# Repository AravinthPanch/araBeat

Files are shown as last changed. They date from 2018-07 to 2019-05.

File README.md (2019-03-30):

<p align="center">
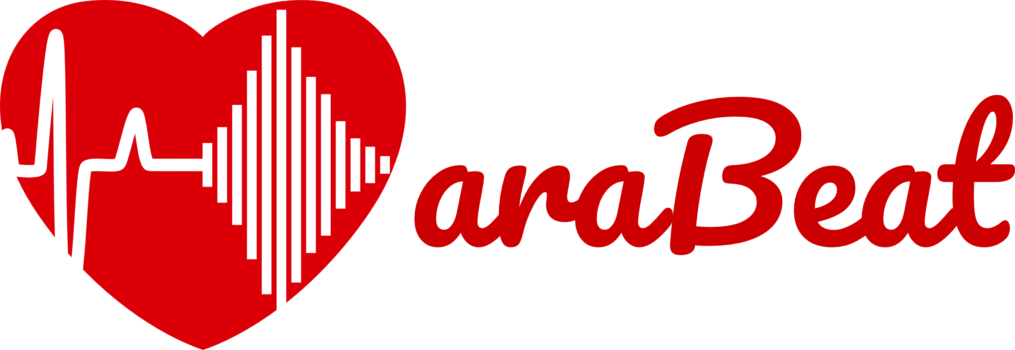
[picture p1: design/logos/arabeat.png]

</p>

# araBeat

araBeat is an interactive new media art developed for the artistic sonification of Electrocardiogram (ECG). It is a complete system that consists of modules of ECG, DSP, MCU & Motherboard.

araBeat captures ECG of human Interactors through two gel-less electrodes, identifies the QRS complex of ECG, calculates the time difference between the R wave peaks and using Audio DSP, it synthesizes high & low frequency sound in realtime, which is synchronized with the heartbeats of the Interactor.

araBeat lies in the spectrum of new media art, the form of interaction with the technology is designed with aesthetics in mind using stainless steel electrodes in the form of human hand.

araBeat is designed to be extendable using modular designs, so that every component can be just individually plugged into the motherboard. It is also built as an industrial grade system to operate in harsh weather conditions from -40 ° Celsius to 85 ° Celsius. Furthermore, it is designed to comply with medical grade electronics to have low electrical noises and safety.

In the first public appearance, araBeat is integrated into a permanent & public mosaic art installation called "The Heart Of Uptown", located at MoZaic East, Minneapolis, USA.

<p align="center">
<b>The Heart Of Uptown powered by araBeat</b>
</br>
</br>
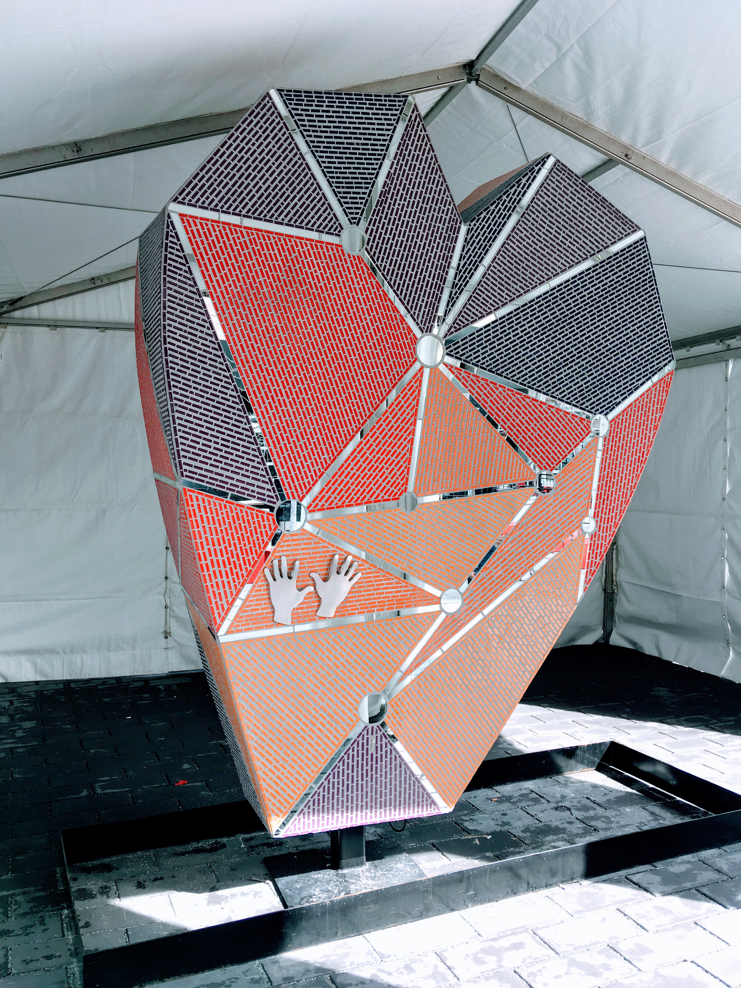
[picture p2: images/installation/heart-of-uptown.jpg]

</p>

## ARTISTS

-   Aravinth Panch &lt; <http://aravinth.info> > New Media Art
-   Stacia Goodman &lt; <http://www.staciagoodmanmosaics.com> > Mosaic Art

## COLLABORATORS

-   Marc Basara - Project Management, Minneapolis
-   Stuart Ackerberg - Art Producer, Minneapolis
-   Felix Christmann - Industrial Design, Berlin
-   Alessandro Aresta - Sound Engineering, Berlin
-   Len Goodman - Graphic Design, Minneapolis
-   John Bean, Giam Nguyen, Hart Johnson, Randi Johnson - Production Management, Minneapolis
-   Pavel Spieker, Kelly Ludeking, Anthony Kling - Structural Design & Construction, Minneapolis
-   Shresth Agrawal - Software Engineering, Berlin
-   Chris Kooper - Metalworking, Berlin

## SUPPORTERS

-   Natalia Aravinth, Mladen Miljic, Darina Onoprienko - Family & Mental Support
-   David Riding, Jasmin Skenderi - Electrical Design Review, Next Big Thing, Berlin
-   Karissa Xie, Rolin Pei - CNC Machining, HLH Prototypes, Shenzhen
-   Monica Shen, Ivy Li, Carmen Zheng - PCB Manufacturing, Seeed Studio, Shenzhen
-   Goran, Sascha Hamacher - WaterJet Cutting, S-Hamacher Art Production Studio, Berlin
-   Robert Blowsky - Digital Signal Processing, Analog Devices, EZ Forum

## STUDIOS AND MANUFACTURERS

-   nLab, Berlin - Interaction Technology Design & Development
-   MotionLab, Berlin - Prototype CNC Machining
-   Tivoli Too, Minneapolis - Structural Design & Construction
-   Seeed Studio, Shenzhen - PCB Manufacturing
-   Troublemaker, Shenzhen - Prototyping
-   HLH Prototypes, Shenzhen - CNC Machining
-   S-Hamacher Art Production Studio, Berlin - WaterJet Cutting & Metalworking

## DESIGN

### Interaction Technology & Mosaic Installation Concept

<p align="center">
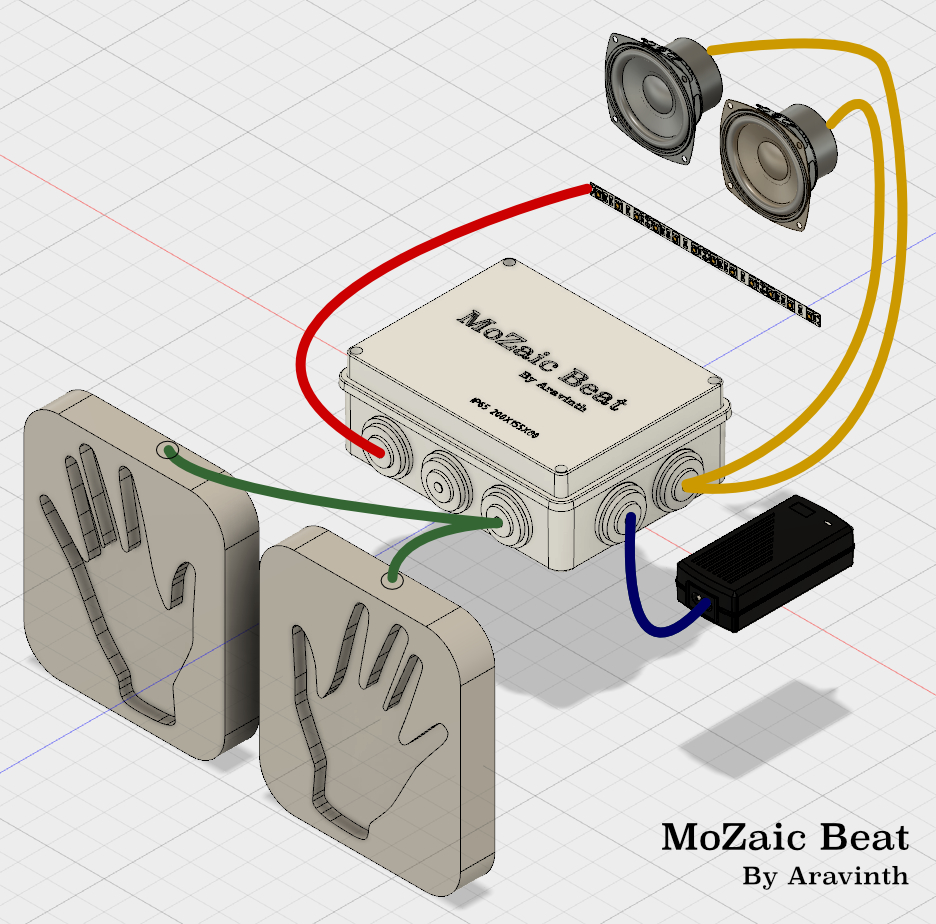
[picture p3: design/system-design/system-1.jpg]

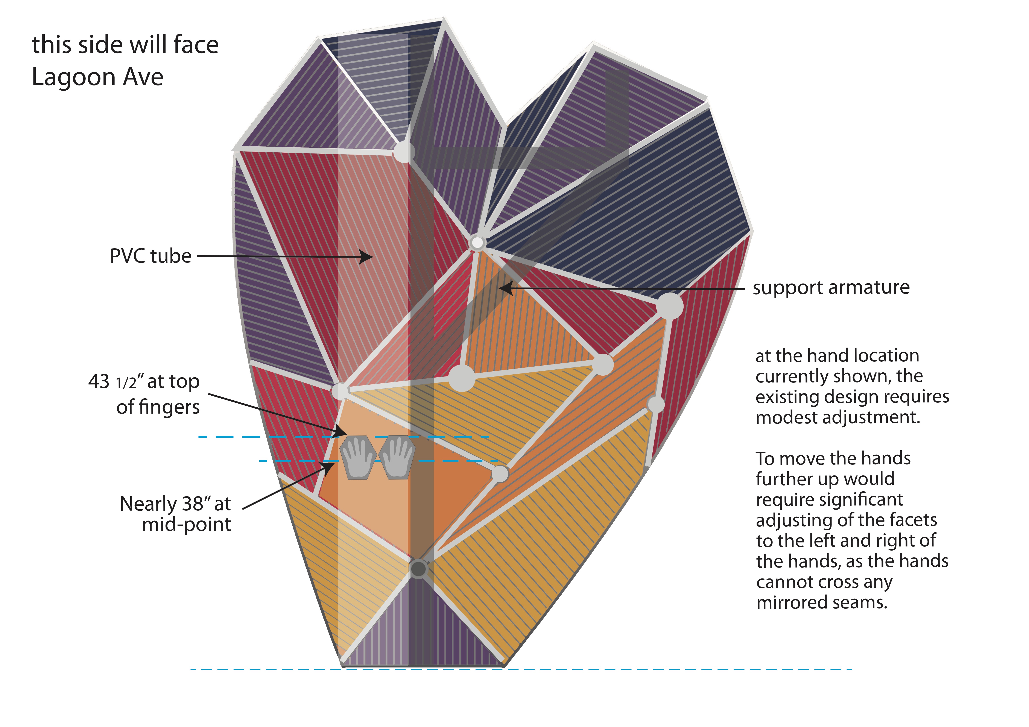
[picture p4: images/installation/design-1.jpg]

</p>

## DEVELOPMENT

### The Heart Of Uptown Installation

-   #### Stage 1 Completion

<p align="center">
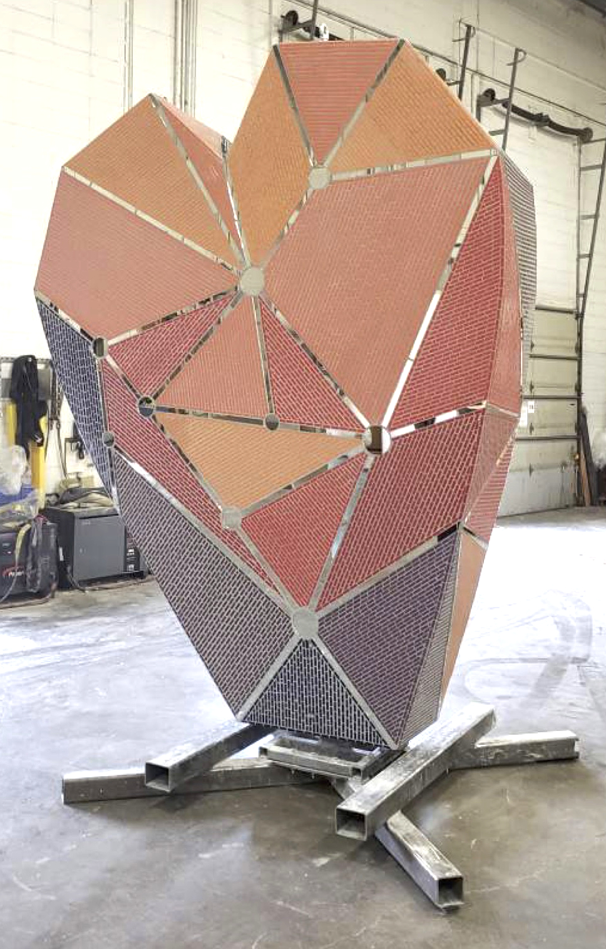
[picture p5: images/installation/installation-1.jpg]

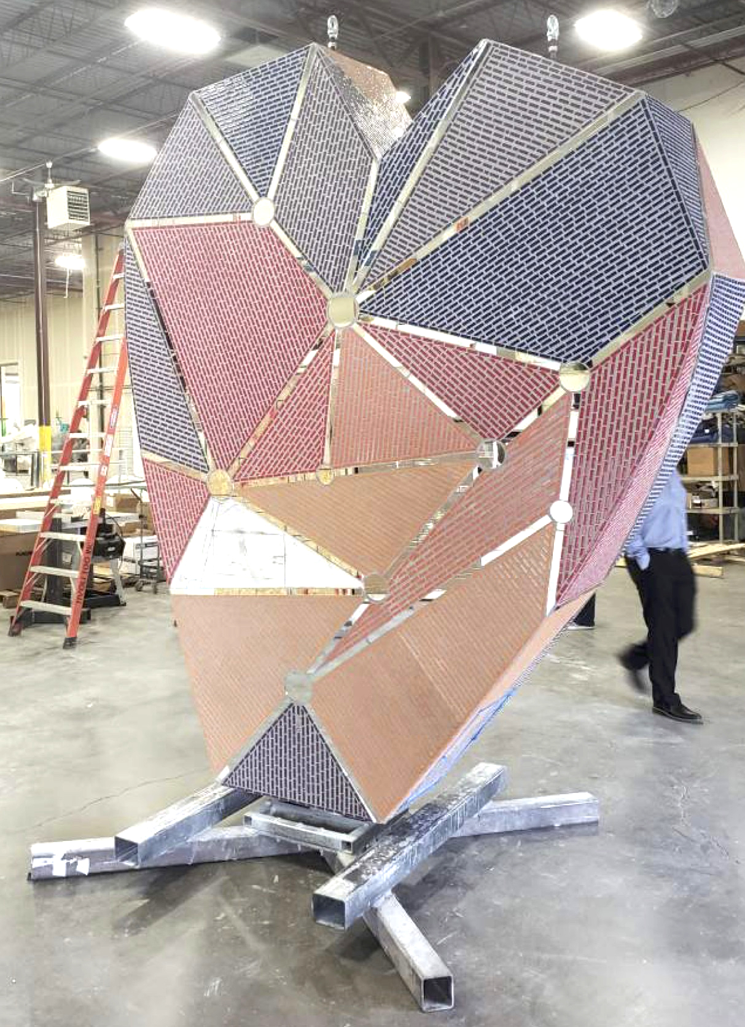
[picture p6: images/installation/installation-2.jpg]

</p>

-   #### Stage 2 Completion

<p align="center">
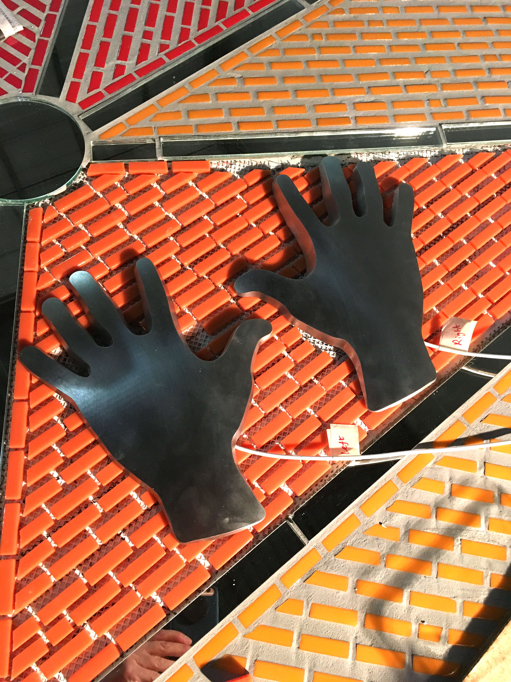
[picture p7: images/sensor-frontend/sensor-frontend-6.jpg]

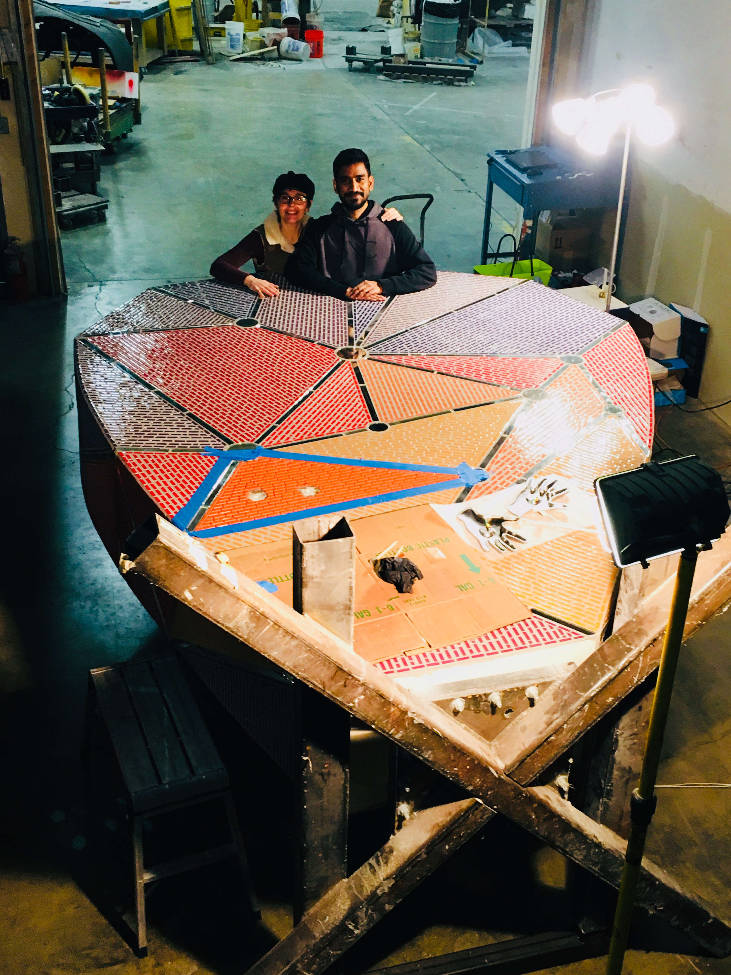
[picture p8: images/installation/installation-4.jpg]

</p>

-   #### Stage 3 Completion

<p align="center">
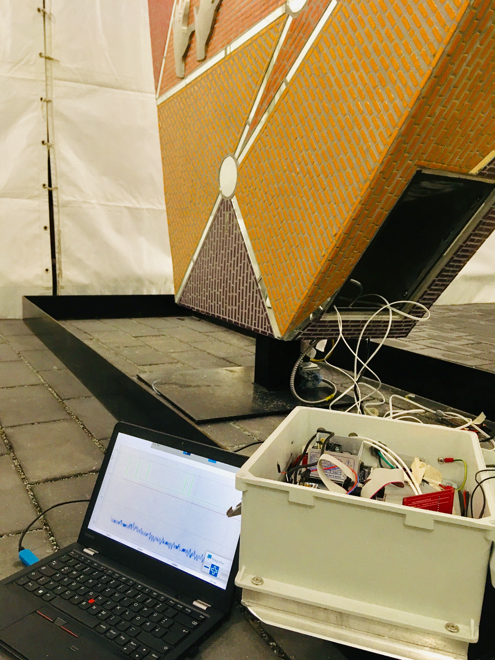
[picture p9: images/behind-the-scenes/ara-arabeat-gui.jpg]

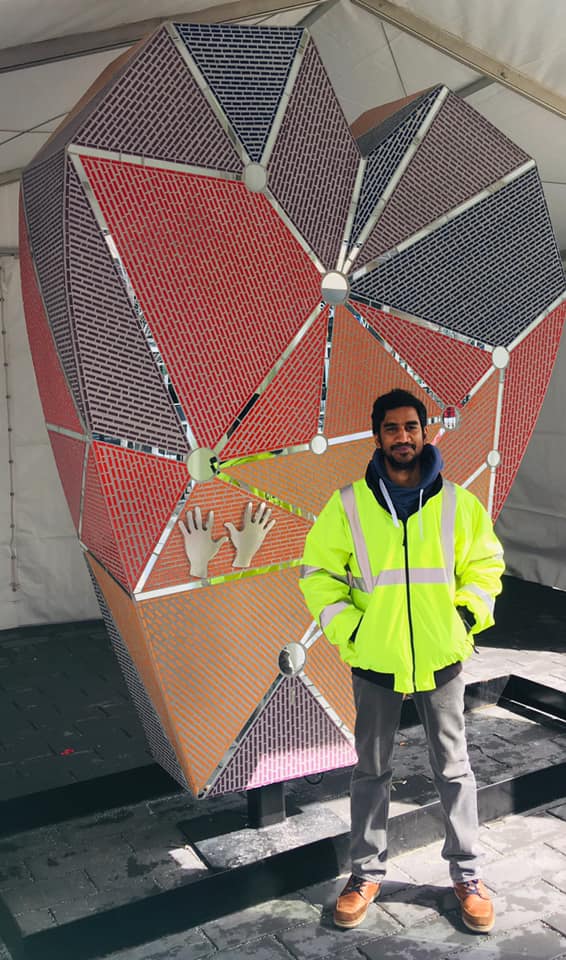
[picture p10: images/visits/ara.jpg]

</p>

### Interaction Technology

-   #### Wiring Design

<p align="center">
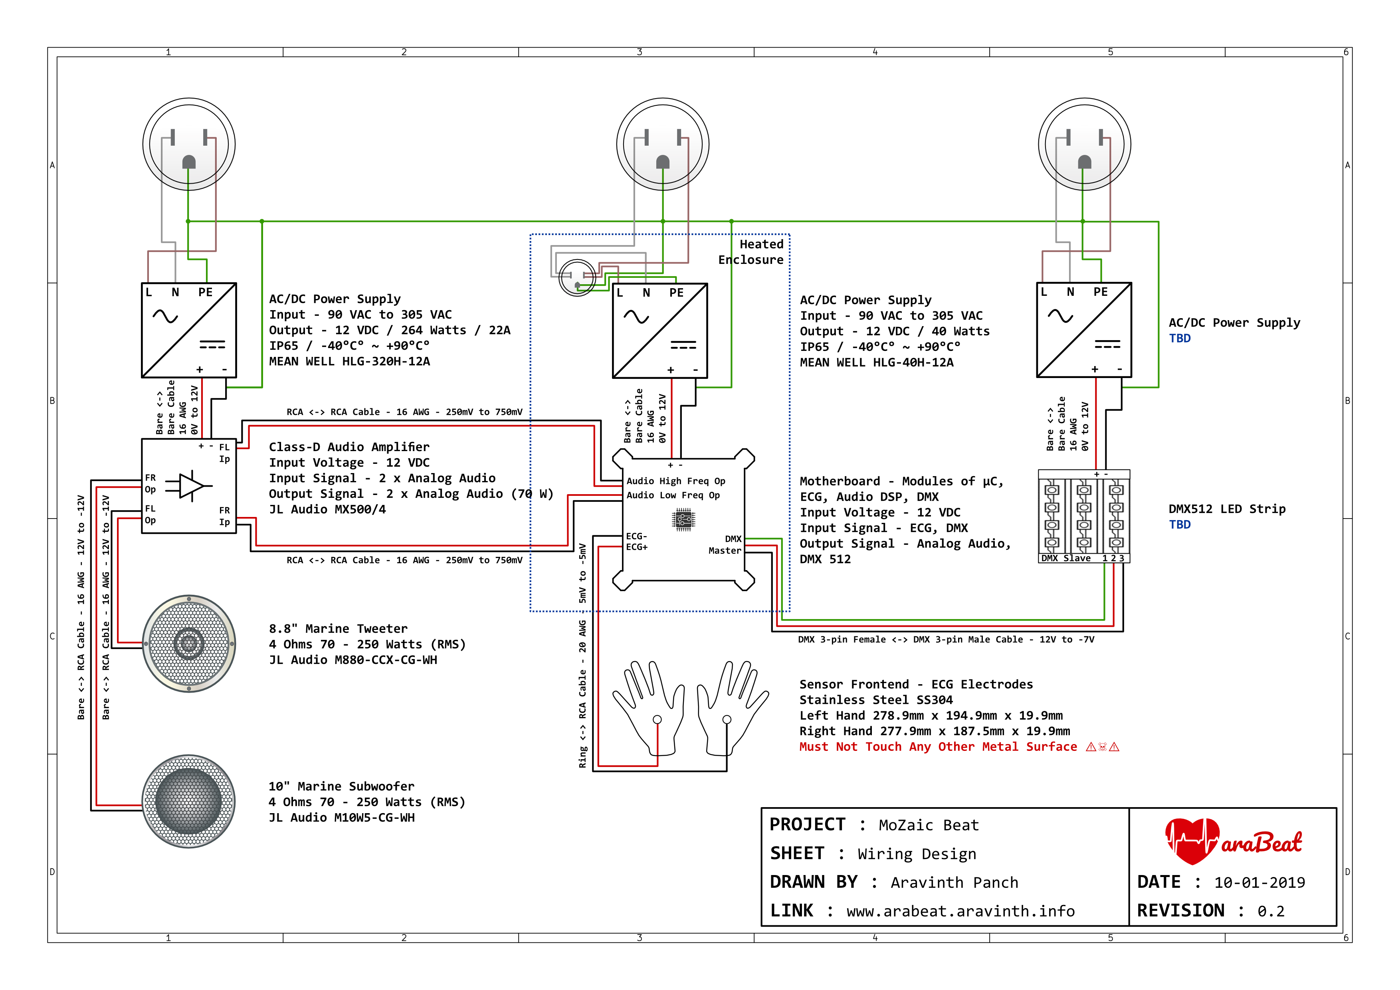
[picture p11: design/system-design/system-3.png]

</p>

-   #### Prototype v1.0

<p align="center">
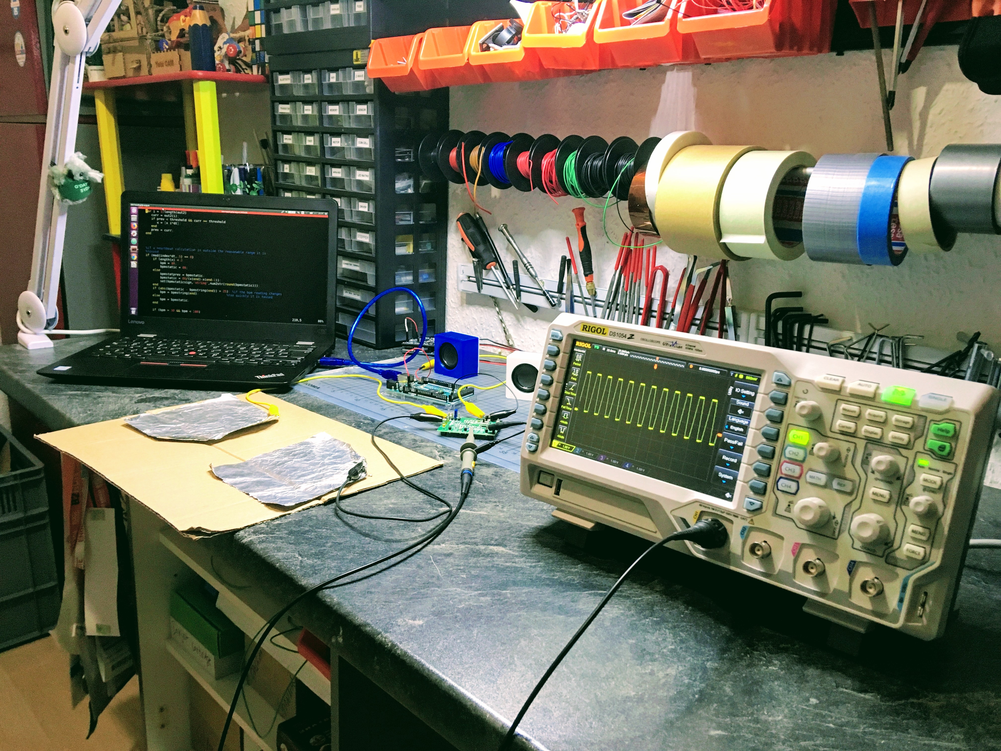
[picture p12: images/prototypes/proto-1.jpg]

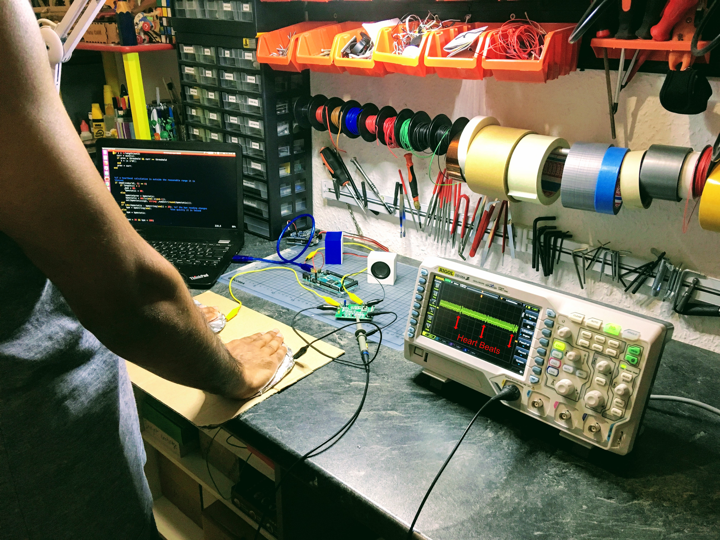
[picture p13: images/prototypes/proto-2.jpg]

</p>

-   #### Prototype v2.0

<p align="center">
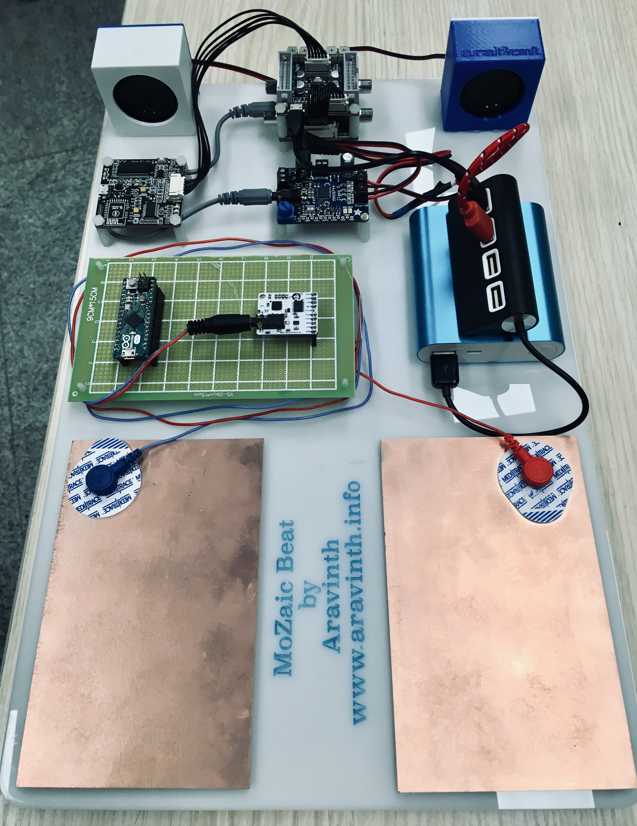
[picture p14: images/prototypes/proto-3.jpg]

</p>

-   #### Prototype v3.0

<p align="center">
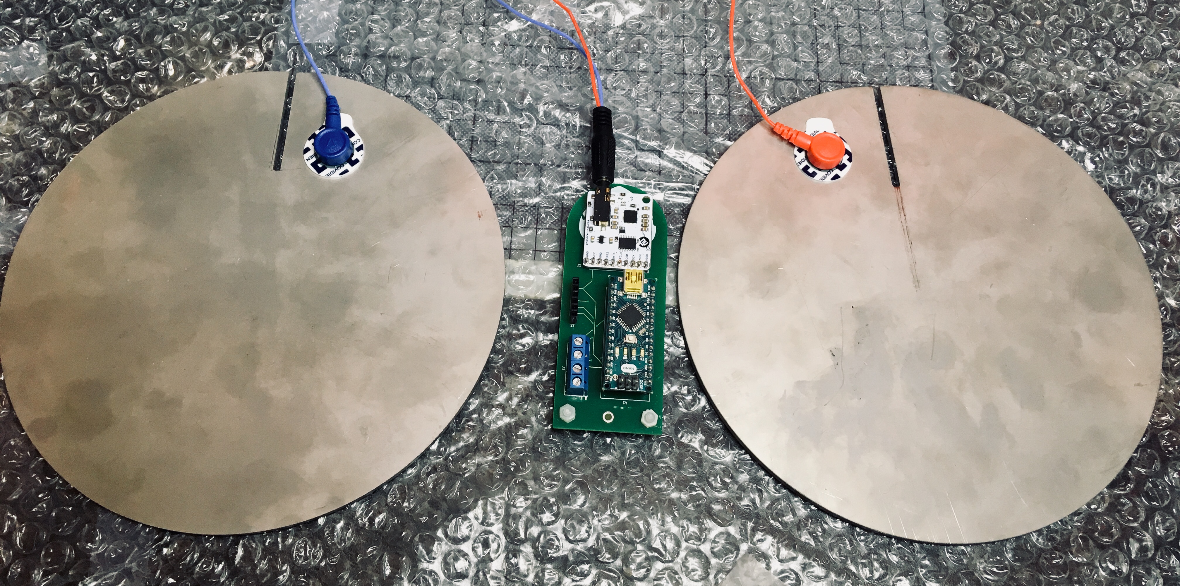
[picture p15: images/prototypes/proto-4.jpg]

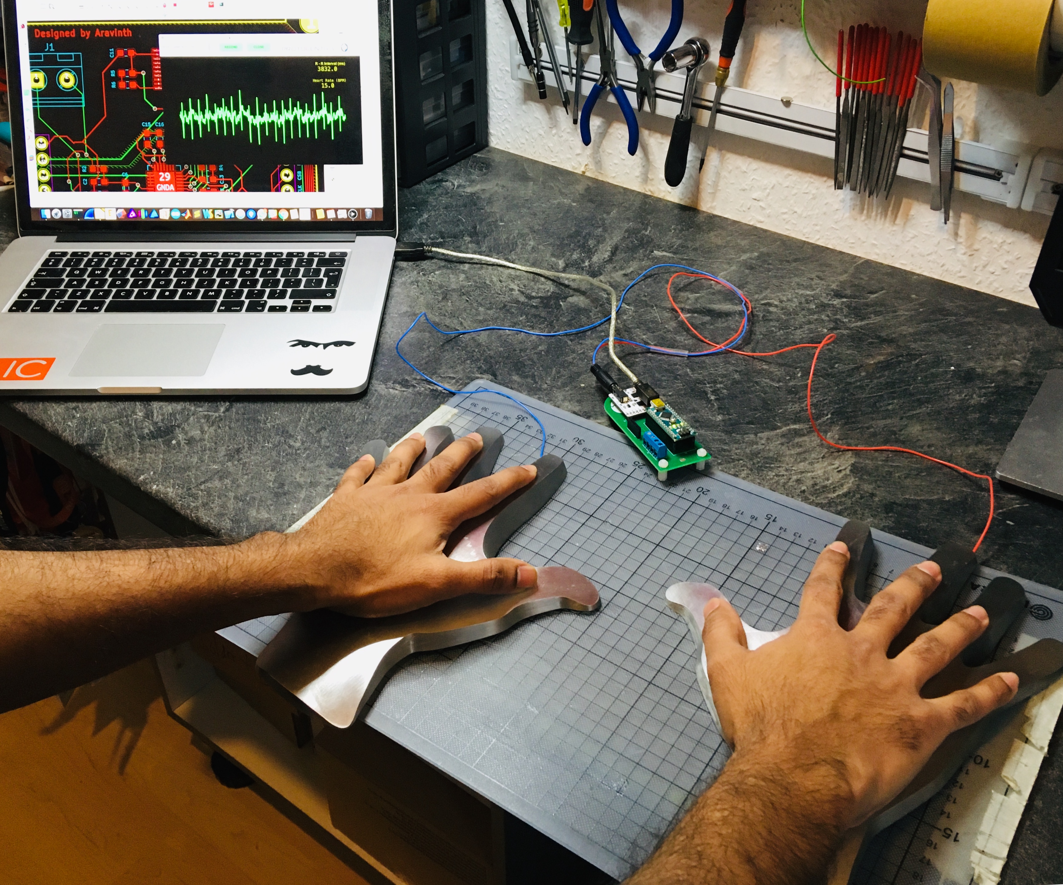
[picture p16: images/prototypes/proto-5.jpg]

</p>

-   #### Prototype v4.0

<p align="center">
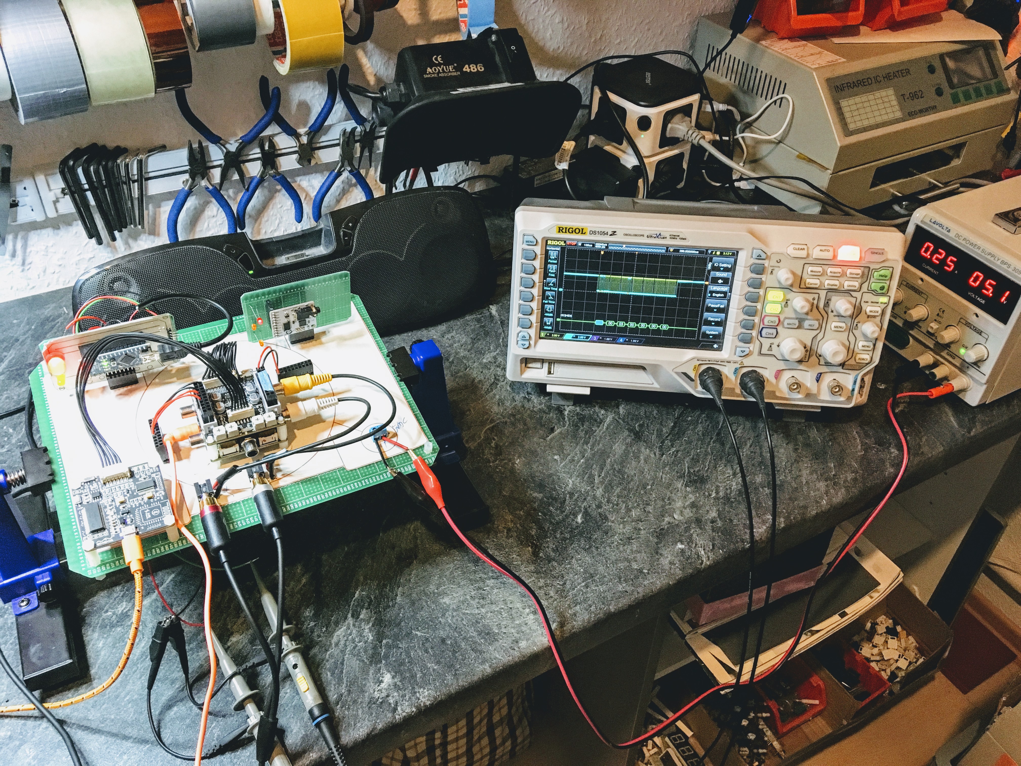
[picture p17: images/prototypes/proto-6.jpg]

</p>

-   #### Motherboard v0.1

<p align="center">
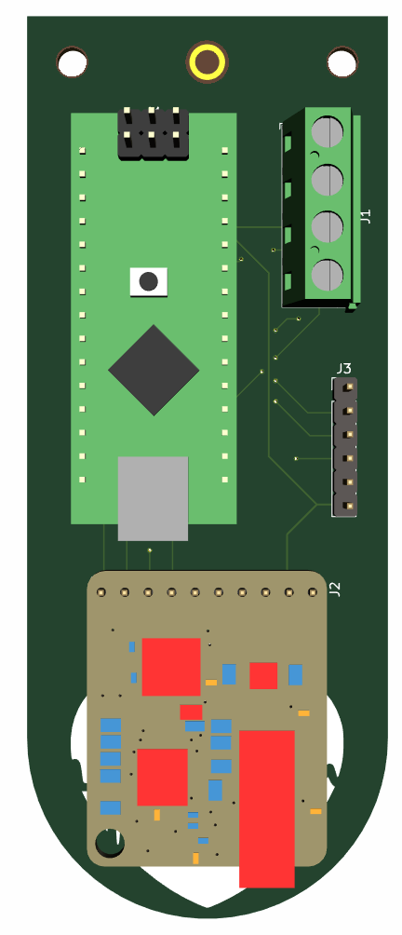
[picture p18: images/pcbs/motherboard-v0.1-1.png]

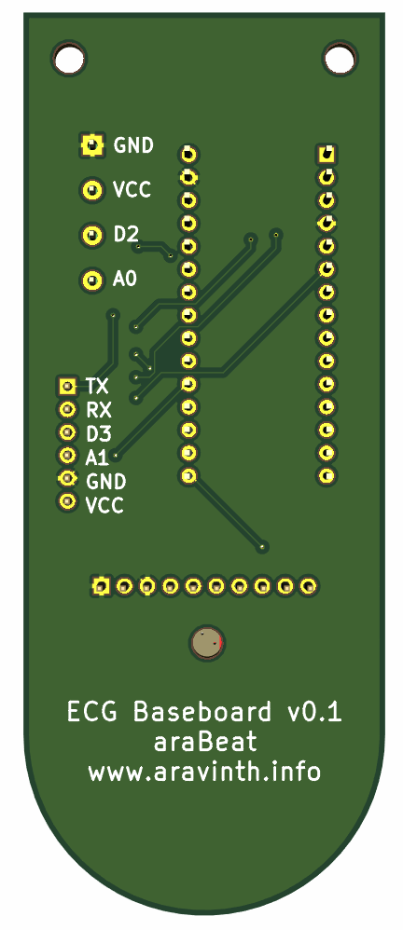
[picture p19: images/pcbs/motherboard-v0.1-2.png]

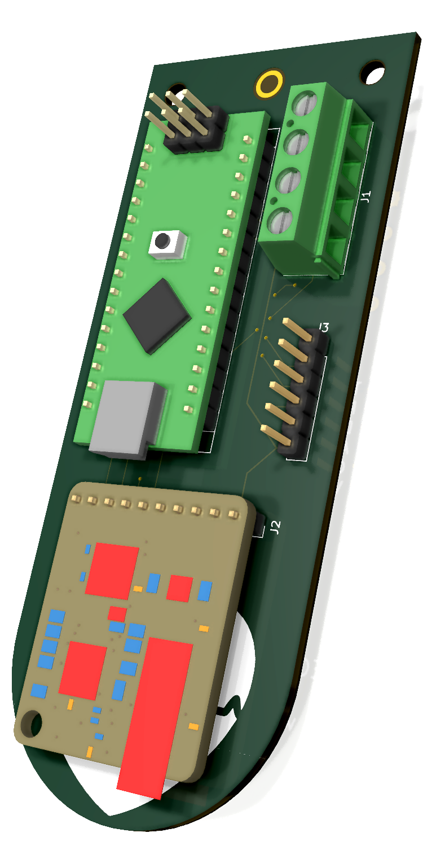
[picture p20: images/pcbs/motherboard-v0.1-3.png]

</br>
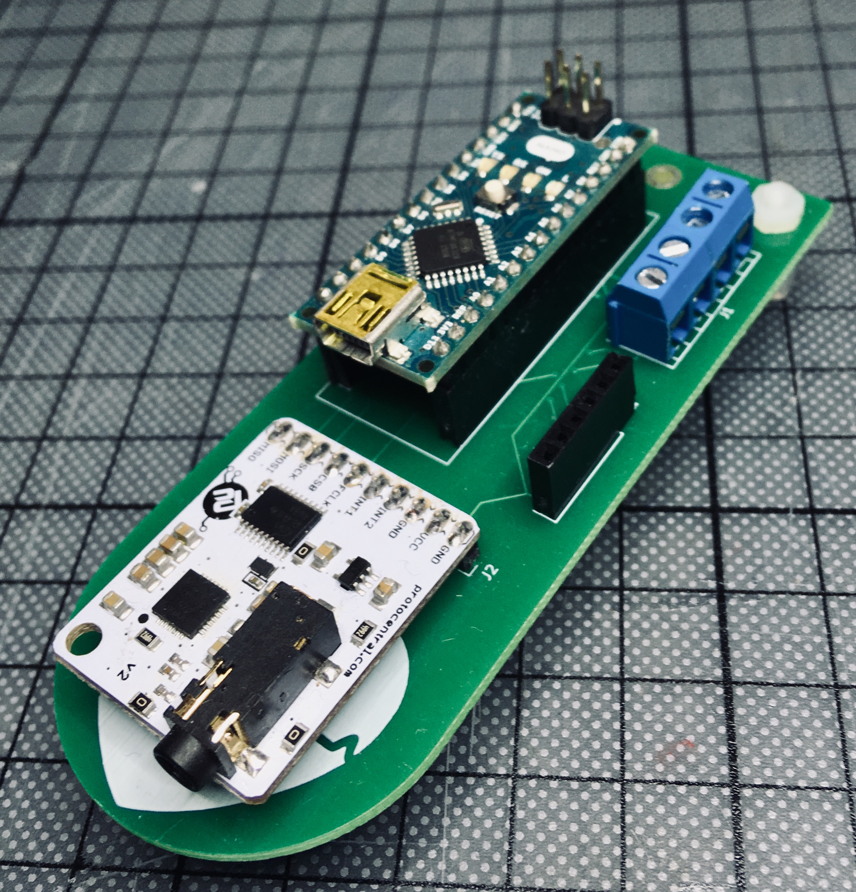
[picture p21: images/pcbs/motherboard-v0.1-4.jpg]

</p>

-   #### ECG Module v0.1

<p align="center">
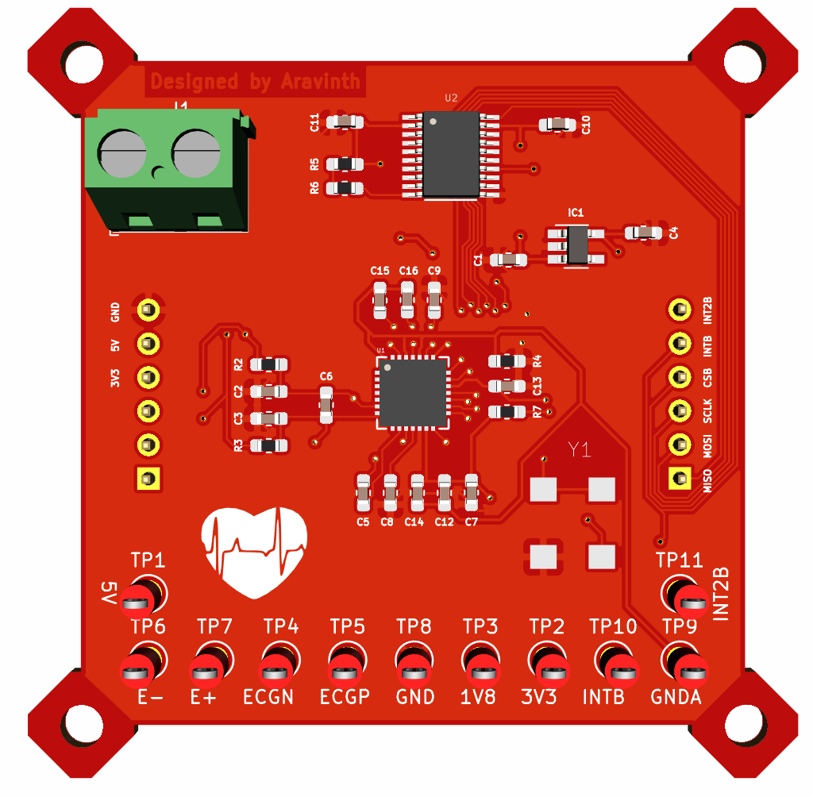
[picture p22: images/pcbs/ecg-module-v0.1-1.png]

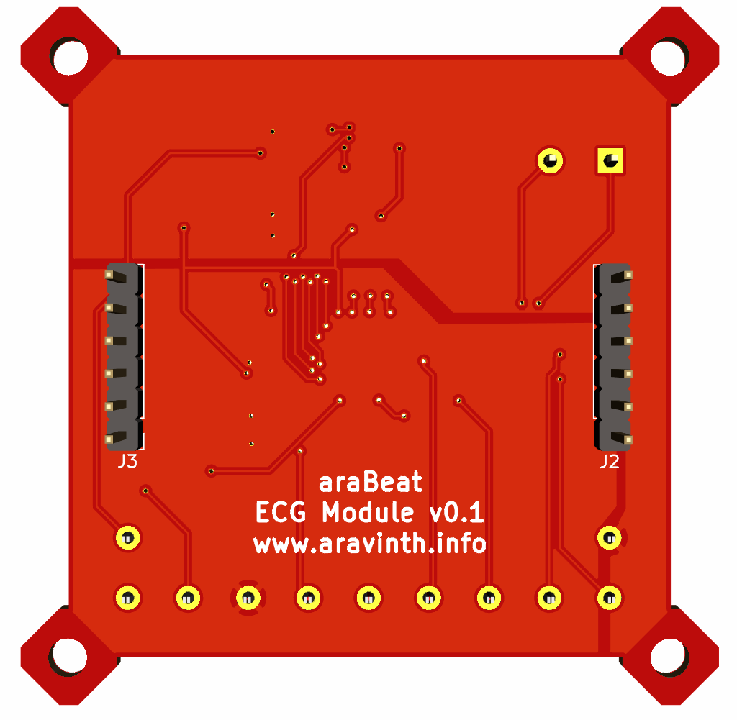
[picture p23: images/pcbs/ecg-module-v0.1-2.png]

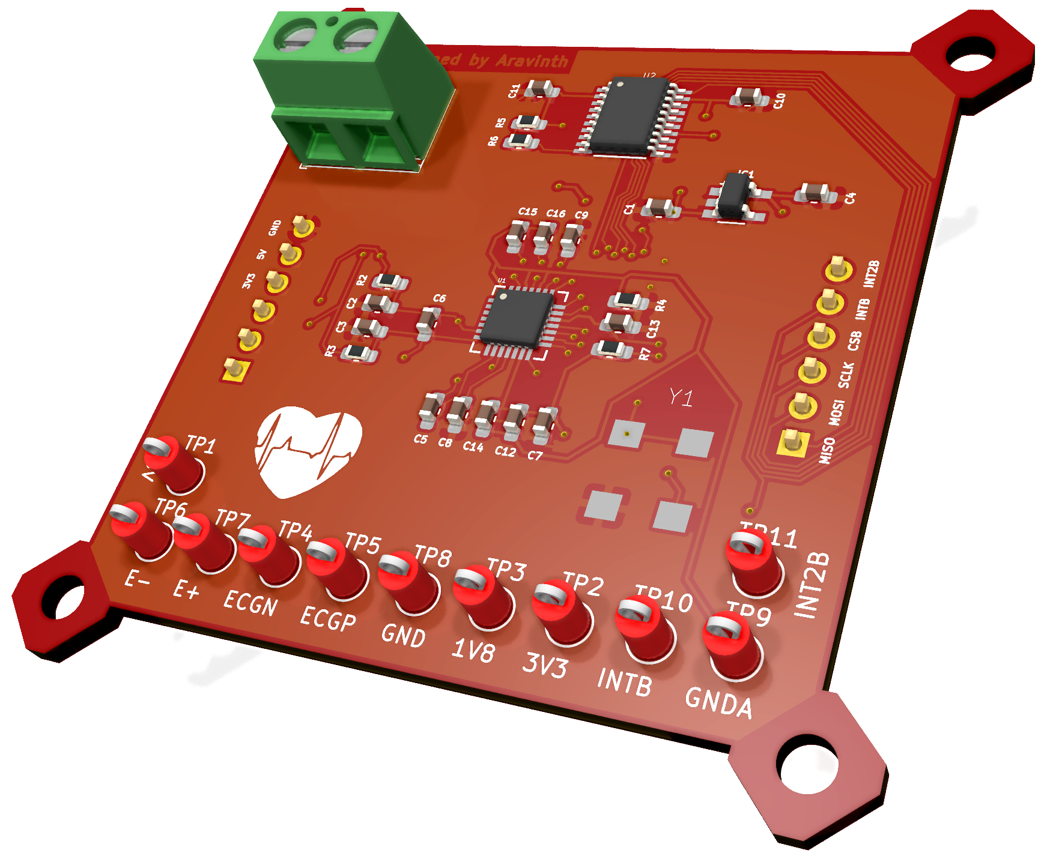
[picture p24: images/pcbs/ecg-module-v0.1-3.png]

</p>

-   #### ECG Module v0.2

<p align="center">
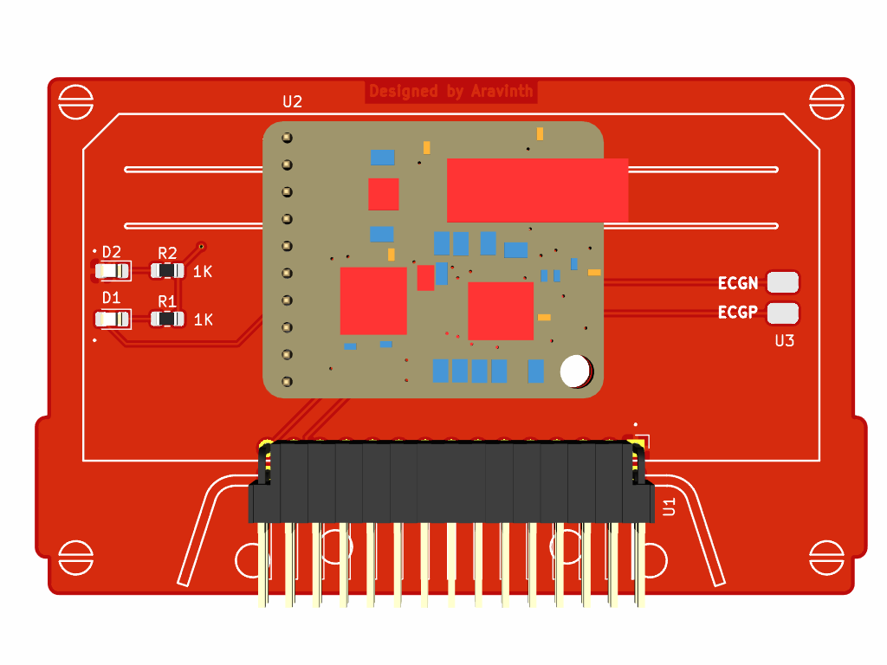
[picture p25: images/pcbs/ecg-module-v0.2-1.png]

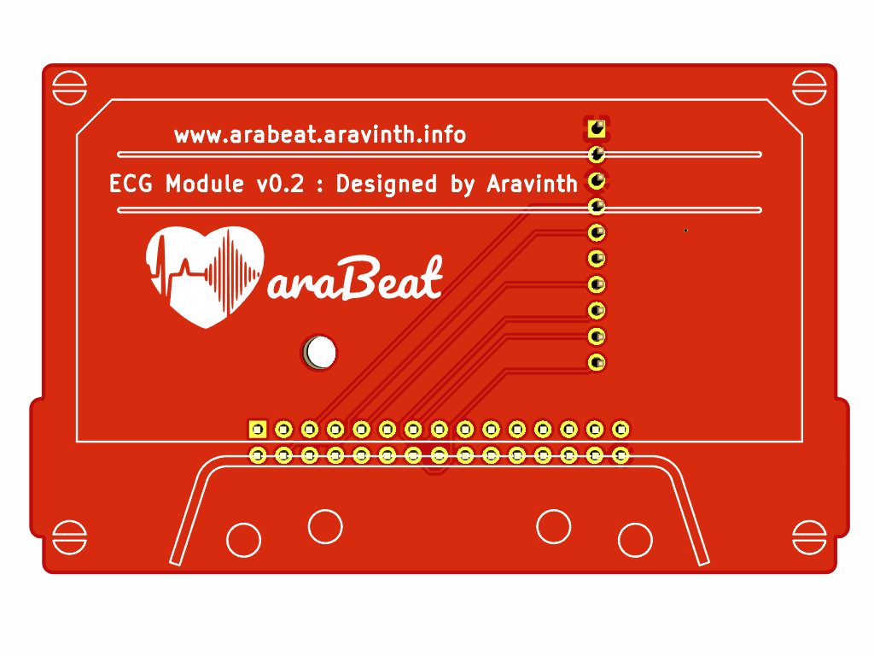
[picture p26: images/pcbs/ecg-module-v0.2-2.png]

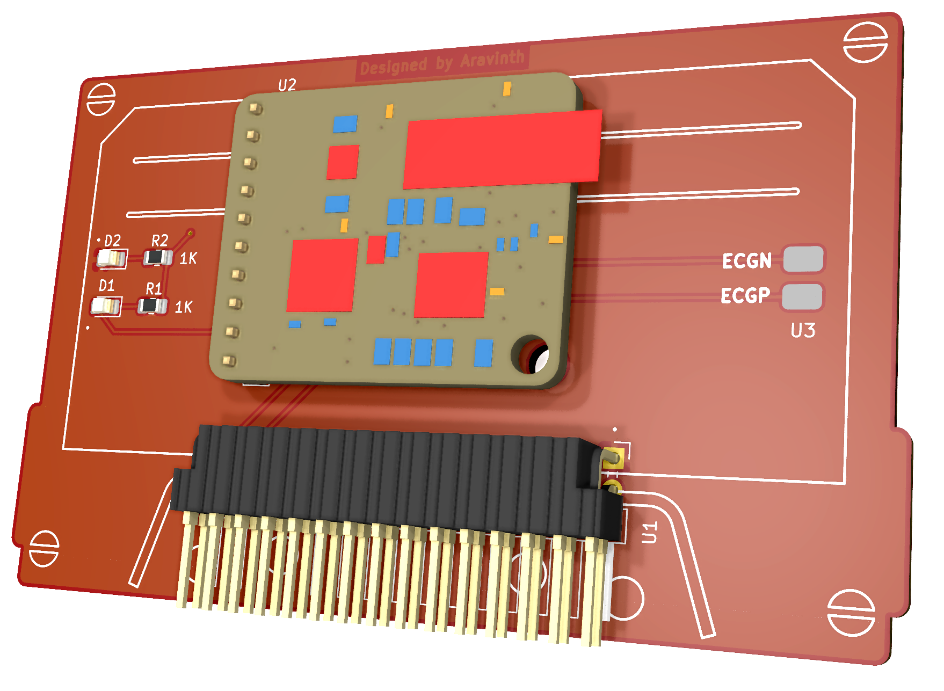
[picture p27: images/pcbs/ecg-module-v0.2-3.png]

</p>

-   #### MCU Module v0.1

<p align="center">
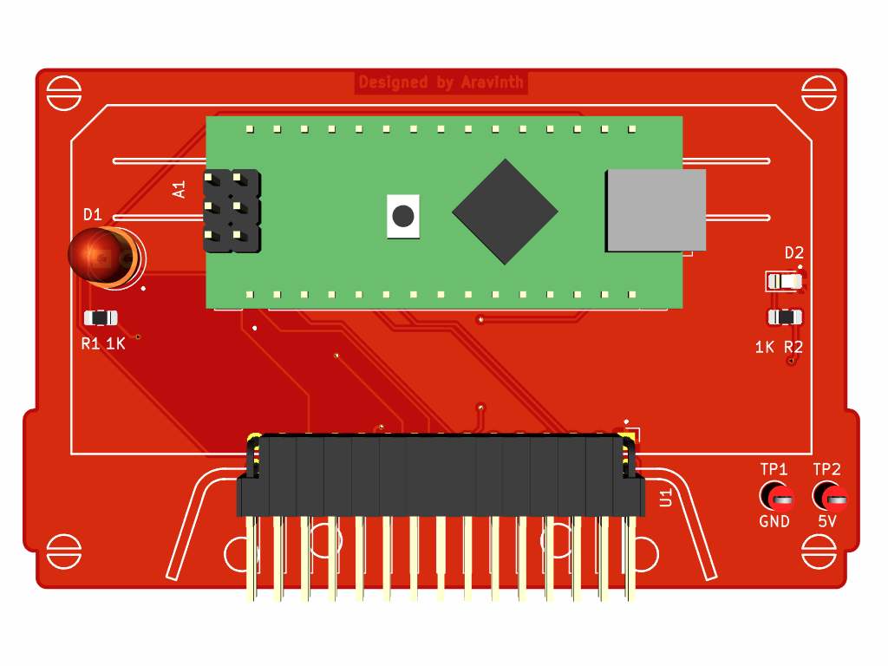
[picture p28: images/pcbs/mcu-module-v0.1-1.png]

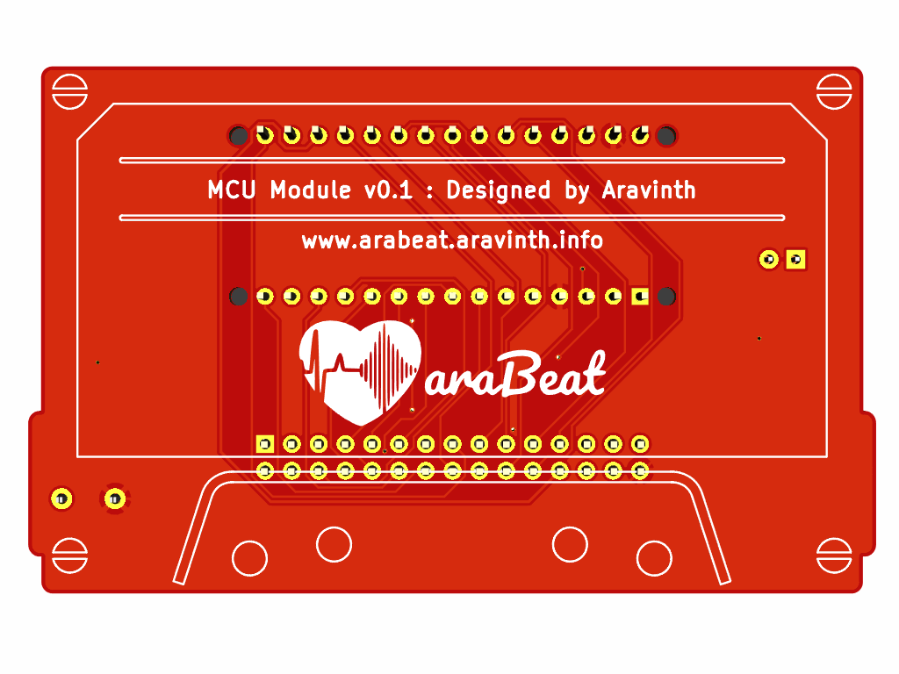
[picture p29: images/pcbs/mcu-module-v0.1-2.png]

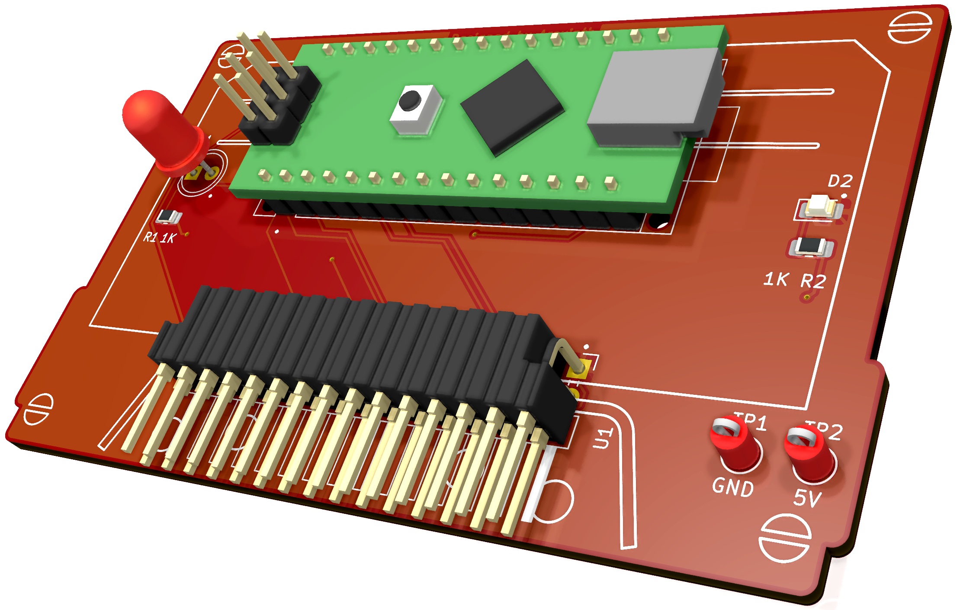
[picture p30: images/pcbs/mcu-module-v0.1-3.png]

</p>

-   #### Motherboard v1.0

<p align="center">
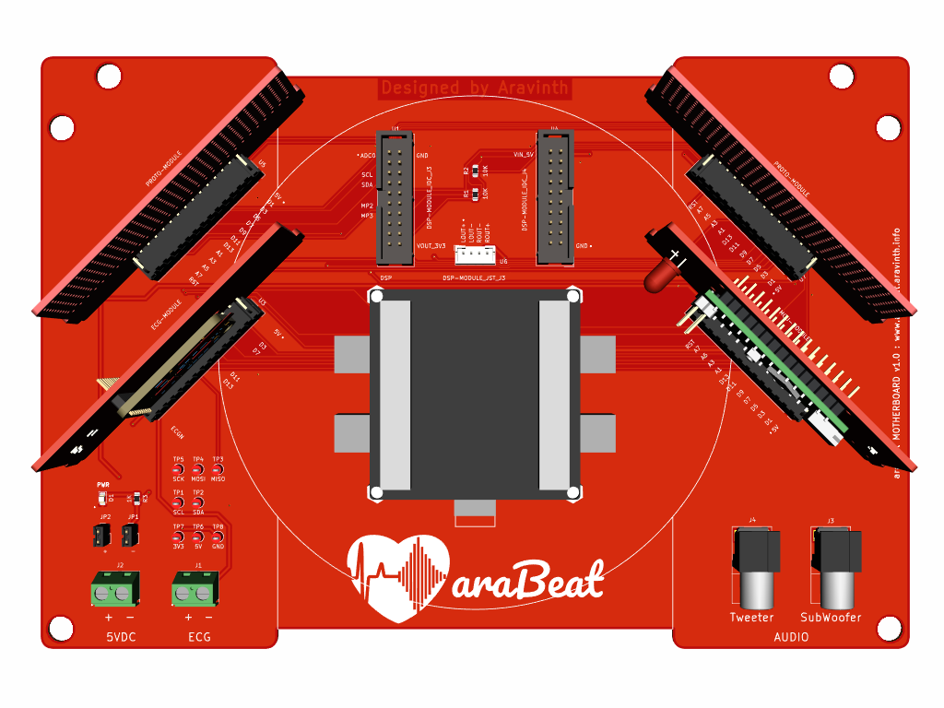
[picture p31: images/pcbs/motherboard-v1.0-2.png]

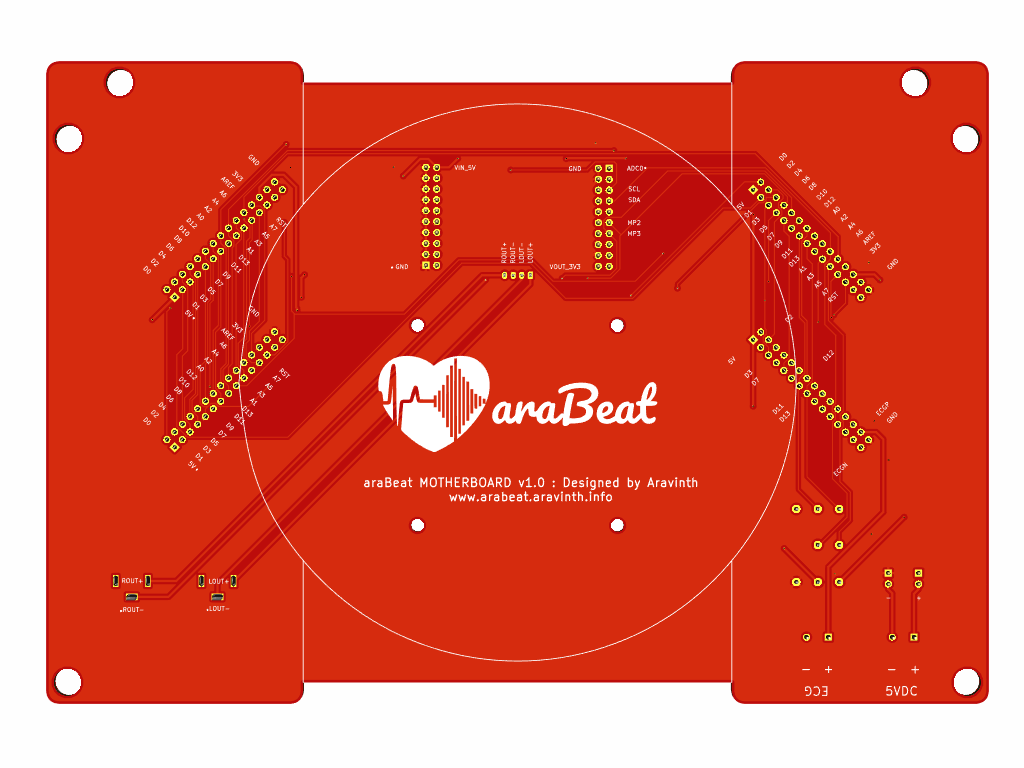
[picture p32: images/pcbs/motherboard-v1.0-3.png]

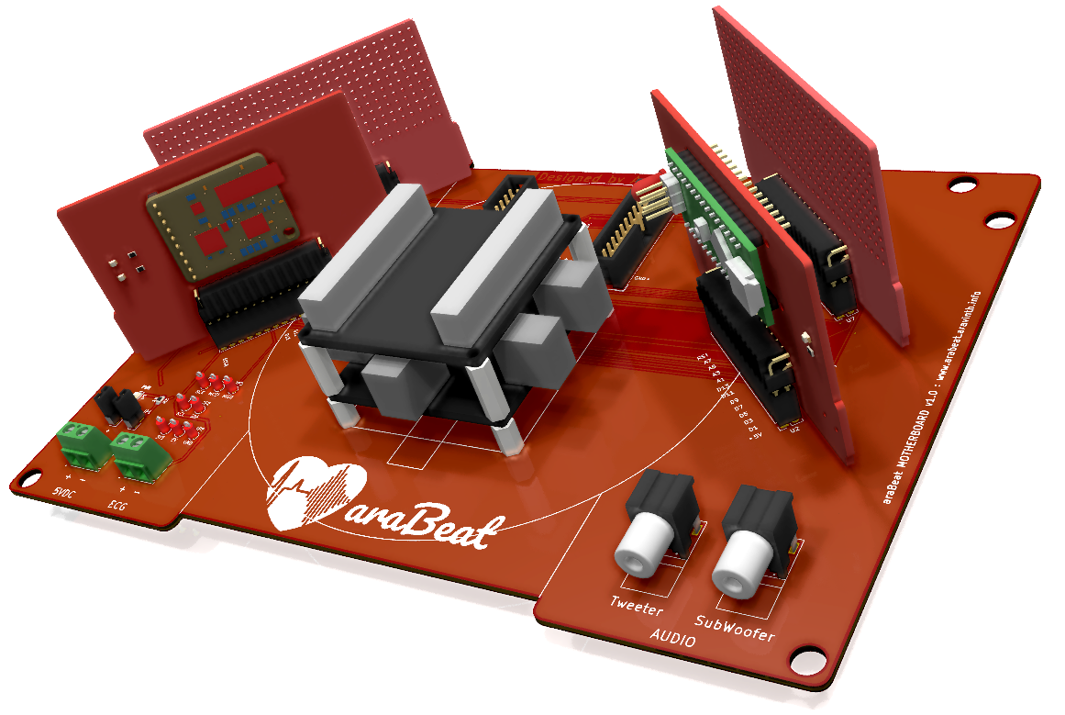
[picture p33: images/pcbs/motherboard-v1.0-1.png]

</br>
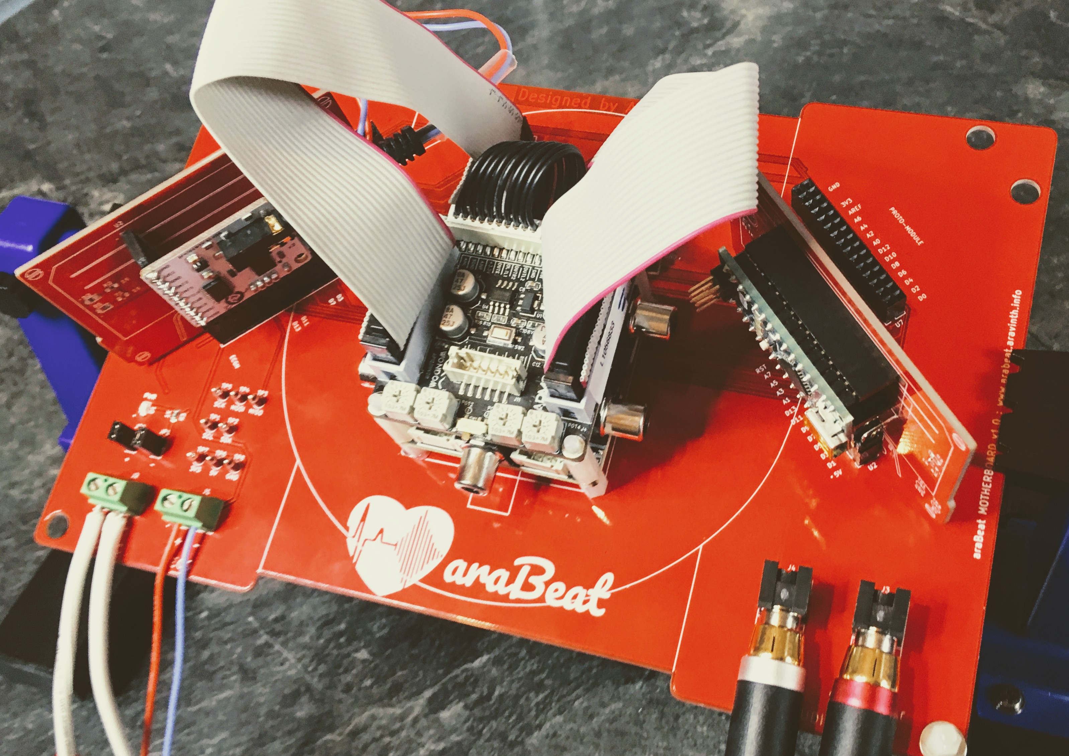
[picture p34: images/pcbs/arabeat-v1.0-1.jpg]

</p>

-   #### Motherboard v1.0 in Weatherproof Industrial Heated Enclosure

<p align="center">
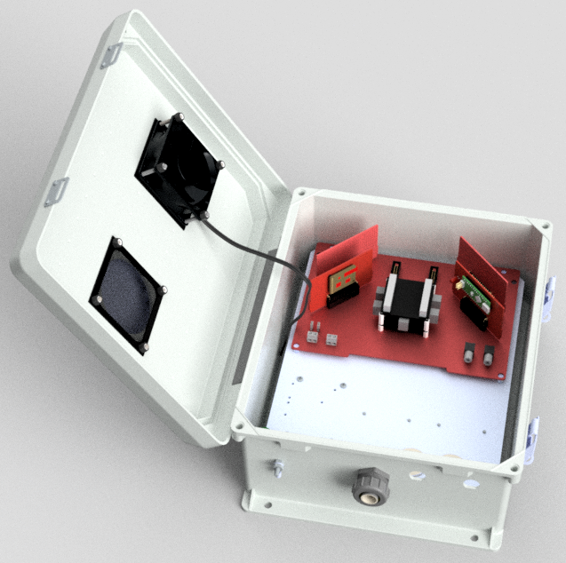
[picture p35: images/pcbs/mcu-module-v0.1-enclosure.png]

</p>

### Sensor Frontend

-   #### Design

<p align="center">
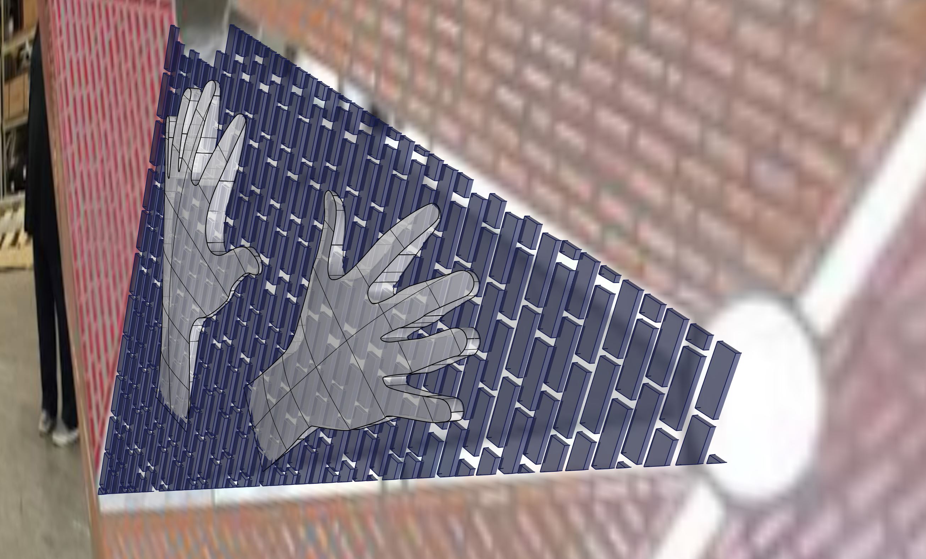
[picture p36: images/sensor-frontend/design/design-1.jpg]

</p>

-   #### Prototype

<p align="center">
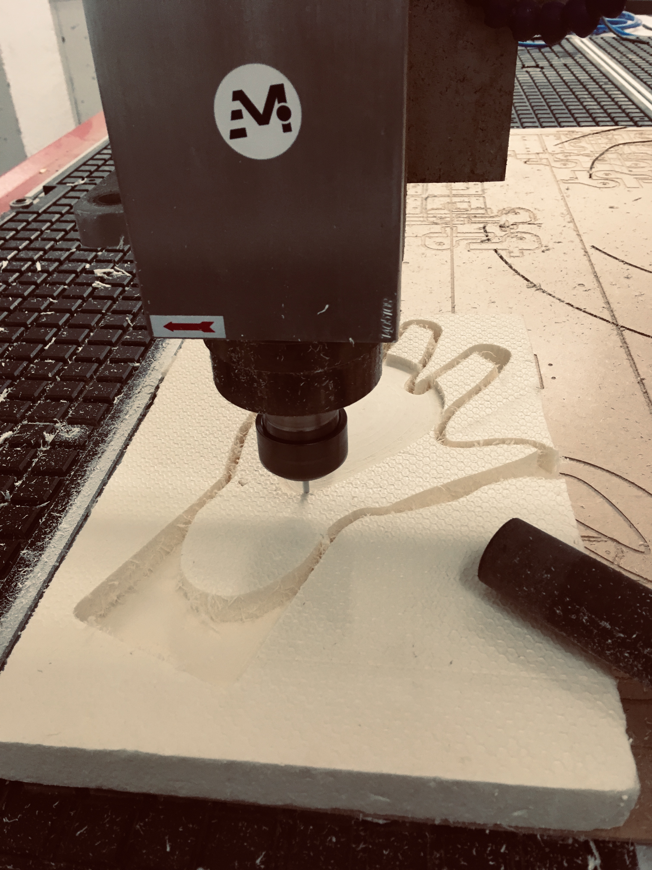
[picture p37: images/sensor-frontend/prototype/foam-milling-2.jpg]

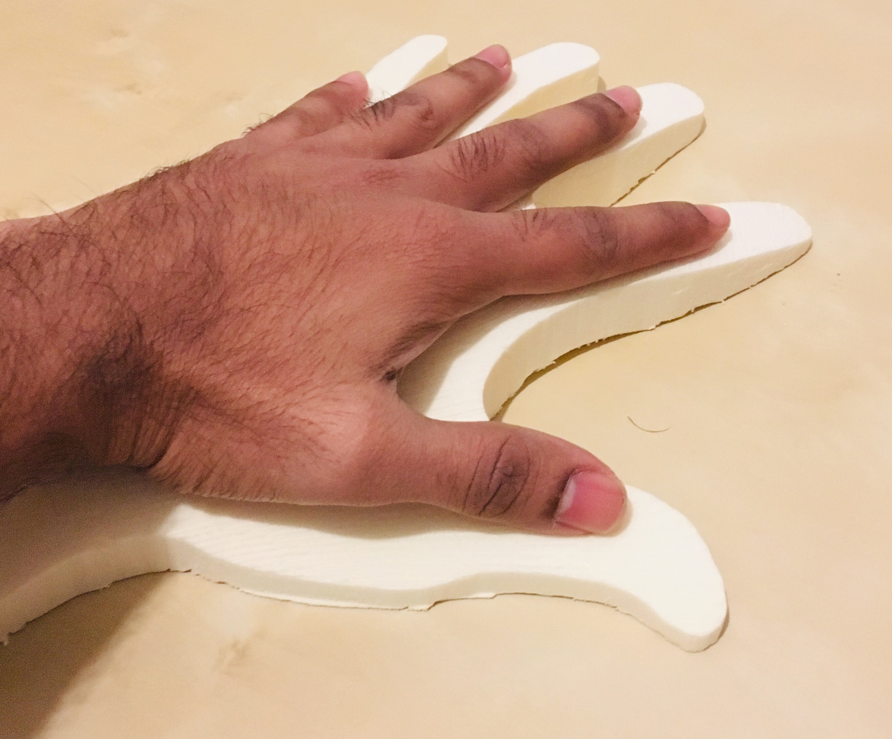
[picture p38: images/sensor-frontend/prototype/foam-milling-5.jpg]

</p>

-   #### Sensor Frontend v1.0

<p align="center">
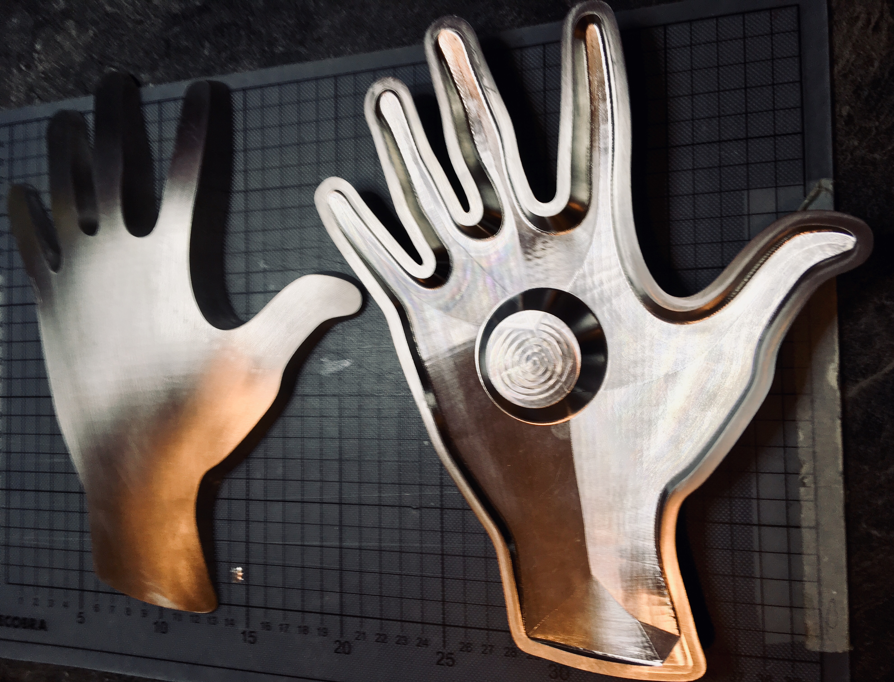
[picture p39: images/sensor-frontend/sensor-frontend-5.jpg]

</p>

#### Marine Standard Tweeter, Sub-Woofer, Amplifier, PSU

<p align="center">
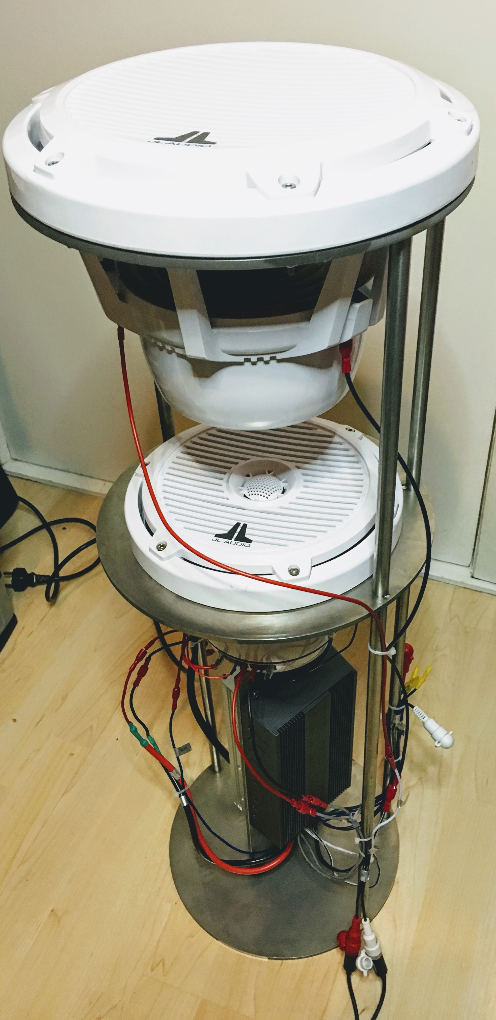
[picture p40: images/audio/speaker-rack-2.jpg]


</p>

#### Electronics & Audio Chambers

<p align="center">


</p>

## DESIGN & DEVELOPMENT TOOLS

-   #### KiCad v5.0.1-3 for PCB Design

<p align="center">

</p>

-   #### Atom v1.34.0 + Platform IO v4.0.0a3 for ECG Firmware Development

<p align="center">

</p>

-   #### Fusion 360 v2.0.5357 for Mechanical Design

<p align="center">

</p>

-   #### Rhino + Grasshoper for Surface Design

<p align="center">

</p>

-   #### Affinity Designer v1.6.1 for Vector Design

<p align="center">

</p>

-   #### SigmaStudio v4.2 for Audio Synthesis

<p align="center">

</p>

-   #### Processing v3.5.3 for araBeat GUI Software Development

<p align="center">

</p>

-   #### araBeat GUI v0.9 for Optimisation of ECG and Audio Waveforms

<p align="center">

</p>

## The Making - Behind the scenes

-   #### Aravinth - Prototype CNC Milling at MotionLab, Berlin

<p align="center">

</p>

-   #### Stacia - Mosaic Making at Private Studio, Minneapolis

<p align="center">

</p>

-   #### Stacia - Mosaic Making at Private Studio, Minneapolis

<p align="center">

</p>

-   #### Len - Structural Construction at Tivoli Too, Minneapolis

<p align="center">

</p>

-   #### Stacia - Styrofoam + Fibreglass Surface Finish at Tivoli Too, Minneapolis

<p align="center">

</p>

-   #### Len - Mosaic Finish at Tivoli Too, Minneapolis

<p align="center">

</p>

-   #### Alessandro - Sound Design at Private Studio, Berlin

<p align="center">

</p>

-   #### Chris - Metalworking at S-Hamacher Art Production Studio, Berlin

<p align="center">

</p>

-   #### Pavel - Metalworking at Tivoli Too, Minneapolis

<p align="center">

</p>

-   #### Kelly - Metalworking at Tivoli Too, Minneapolis

<p align="center">

</p>

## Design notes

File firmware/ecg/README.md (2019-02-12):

# ECG Firmware

This is developed to detect heartbeats reliably from 2 gel-less electrodes and send the pulses to DSP, that produces music from ECG.

### Firmware Development Setup
- Install Atom IDE (https://atom.io)
- Install PlatformIO IDE for Atom (https://platformio.org/platformio-ide) and restart Atom
- Open ./firmware/ecg/src/main.cpp
- Plugin araBeat ECG Development Kit via USB and click "Upload" under "PlatformIO" menu in Atom to flash the firmware

### araBeat ECG Development Kit

<p align="center">
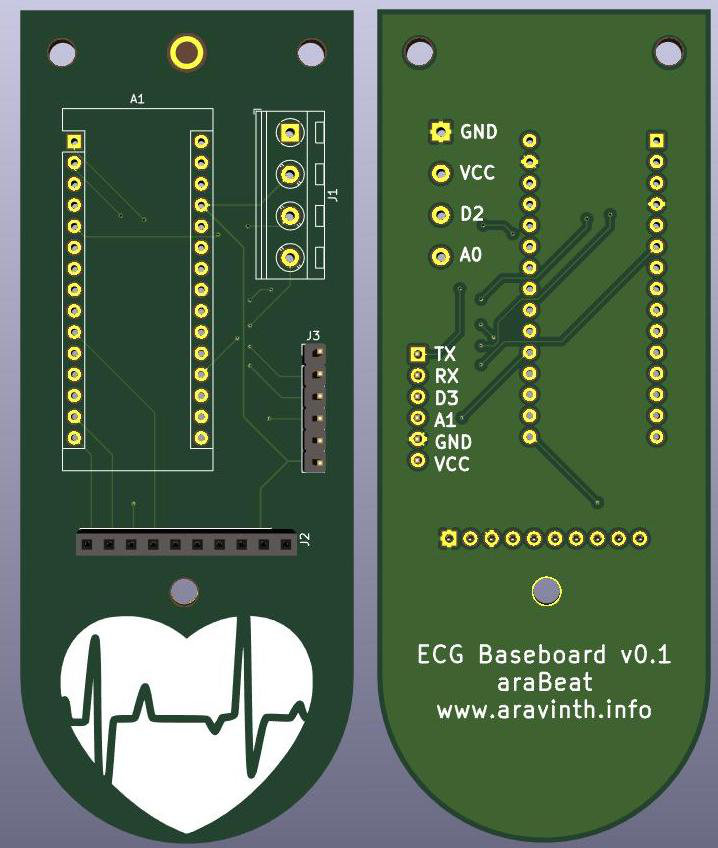
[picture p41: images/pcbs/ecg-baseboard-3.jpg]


</p>

## MAX30003

MAX30003 is a complete, biopotential, analog front- end solution for wearable applications. It offers high performance for clinical and fitness applications, with ultra-low power for long battery life. The MAX30003 is a single biopotential channel providing ECG waveforms and heart rate detection.

The biopotential channel has ESD protection, EMI filtering, internal lead biasing, DC leads-off detection, ultra-low power leads-on detection during standby mode, and extensive calibration voltages for built-in self-test. Soft power-up sequencing ensures no large transients are injected into the electrodes. The biopotential channel also has high input impedance, low noise, high CMRR, programmable gain, various low-pass and high-pass filter options, and a high resolution analog-to-digital converter. The biopotential channel is DC coupled, can handle large electrode voltage offsets, and has a fast recovery mode to quickly recover from overdrive conditions, such as defibrillation and electrosurgery.

### Production Hardware

<p align="center">
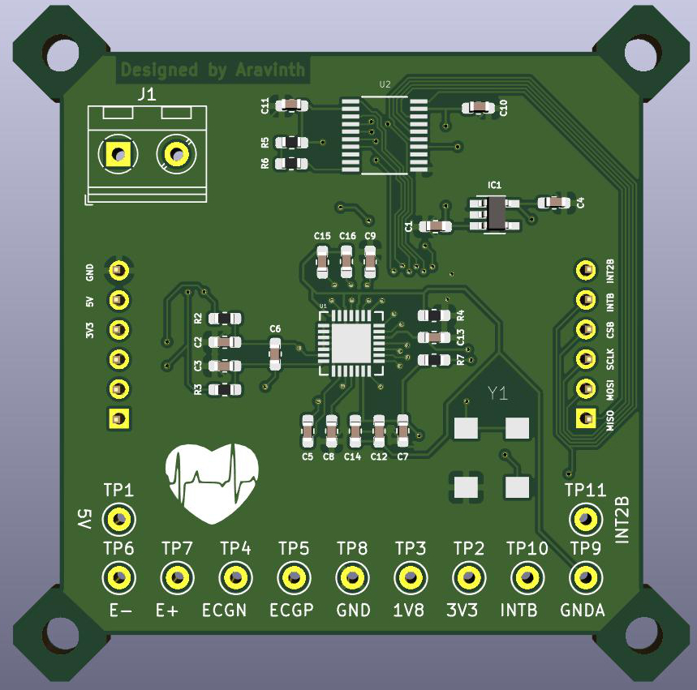
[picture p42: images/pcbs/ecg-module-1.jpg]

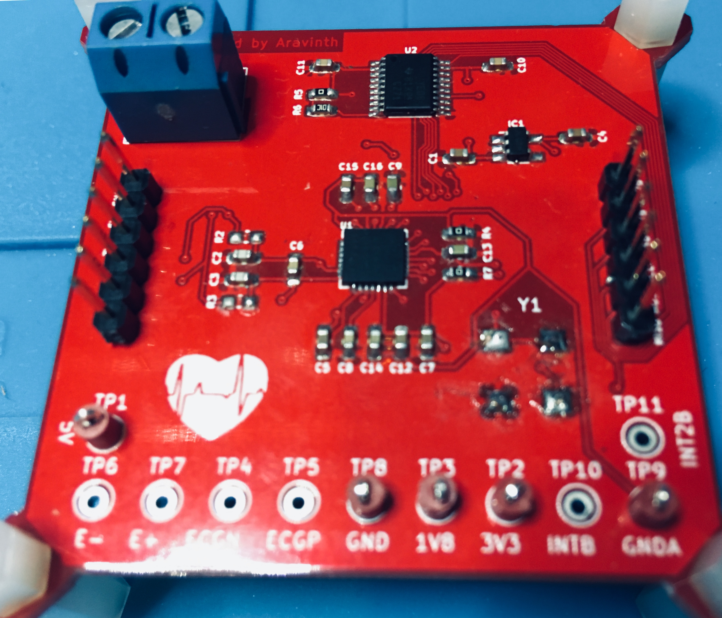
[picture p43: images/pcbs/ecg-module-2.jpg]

</p>

### Pinout

|MAX30003 pin | Pin Function |ATMEGA328 Pin |
|---|:---:|---:|
| MISO | Slave Out |  D12 |
| MOSI | Slave In |  D11 |
| SCLK | Serial Clock |  D13 |
| CS | Chip Select |  D7 |
| VCC | Digital VDD |  +5V |
| GND | Digital Gnd |  Gnd |
| FCLK | 32K CLOCK |  - |
| INT1 | Interrupt1 |  - |
| INT2 | Interrupt2 |  - |

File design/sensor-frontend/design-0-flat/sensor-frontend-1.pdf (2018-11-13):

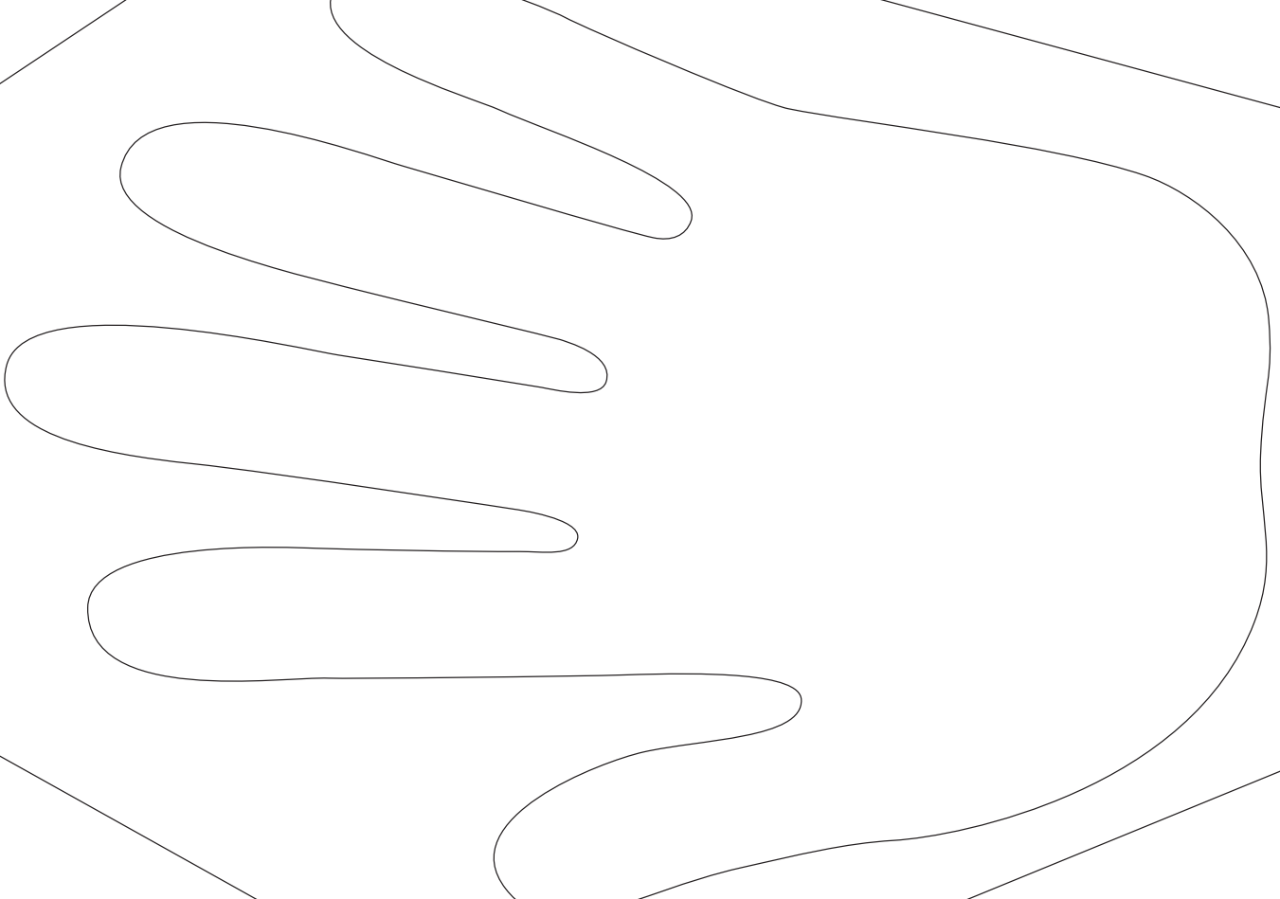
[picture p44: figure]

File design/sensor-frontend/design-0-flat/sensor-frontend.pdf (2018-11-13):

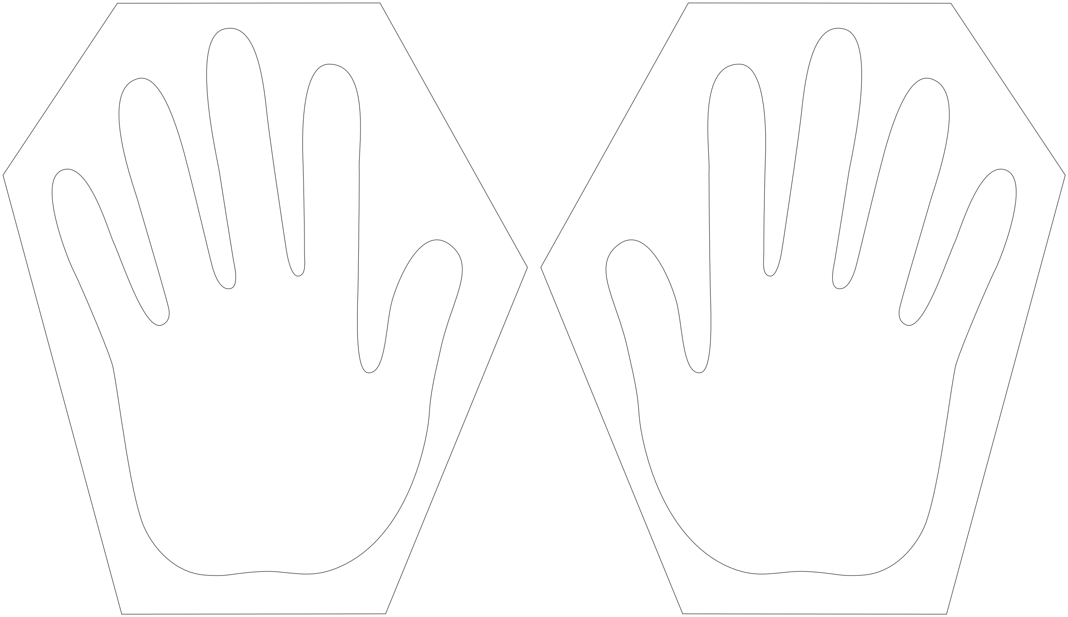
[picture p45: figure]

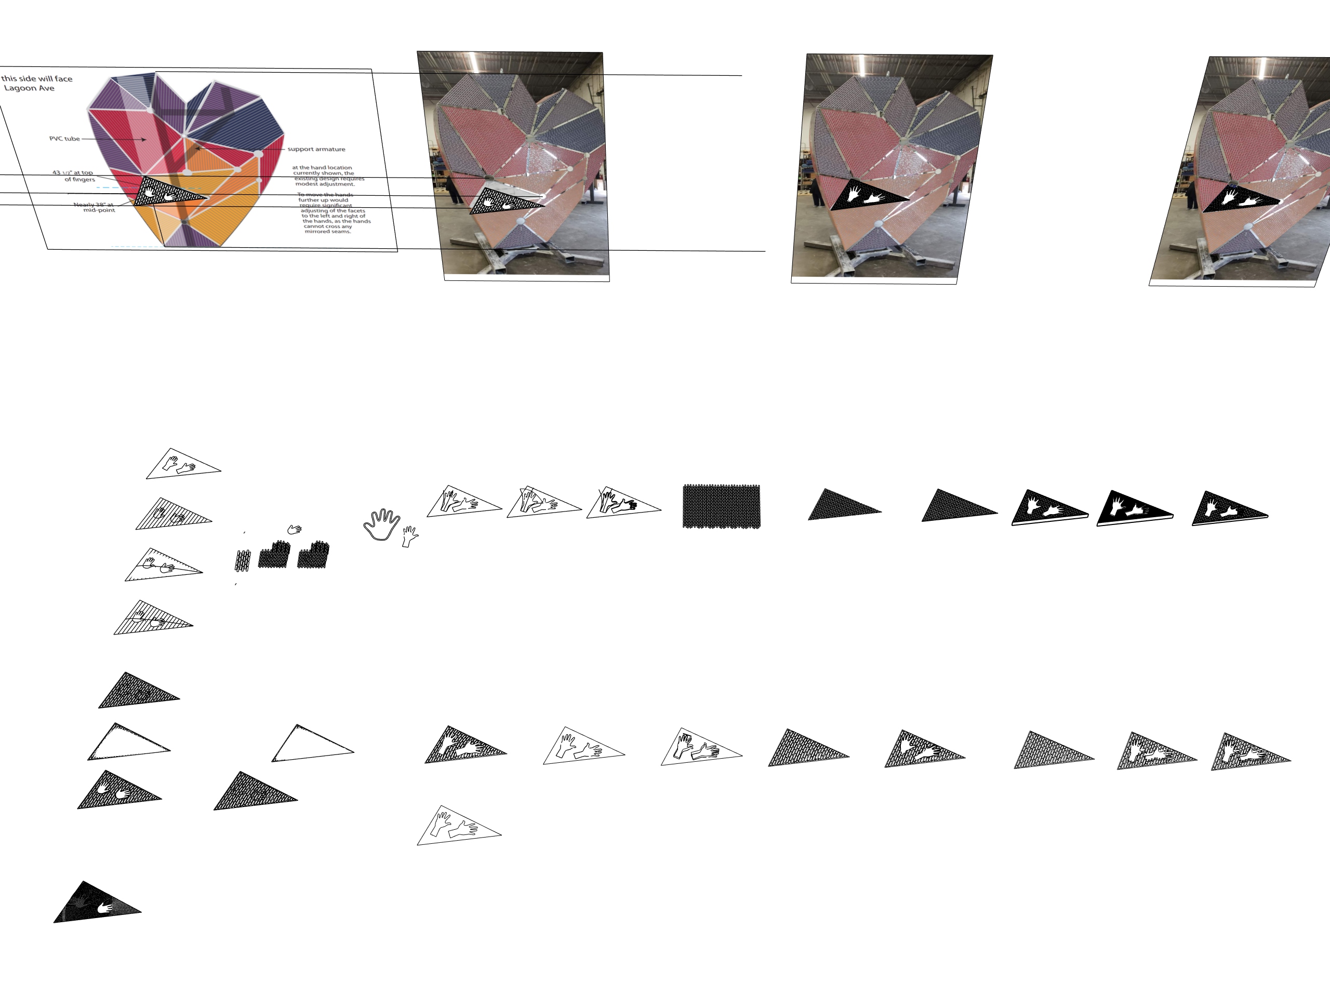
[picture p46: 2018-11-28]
images/sensor-frontend/design/design-process.jpg

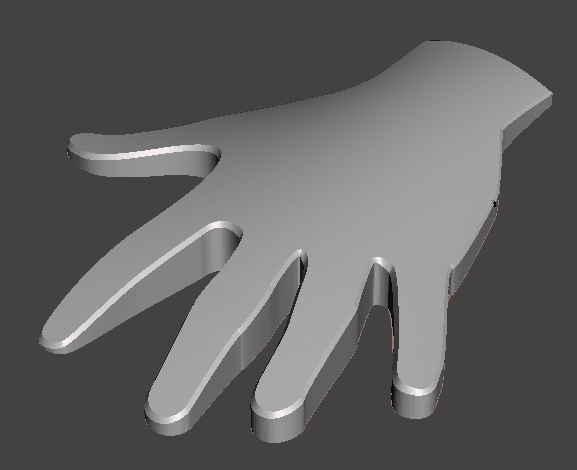
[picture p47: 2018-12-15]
images/sensor-frontend/design/steel-design-1.png

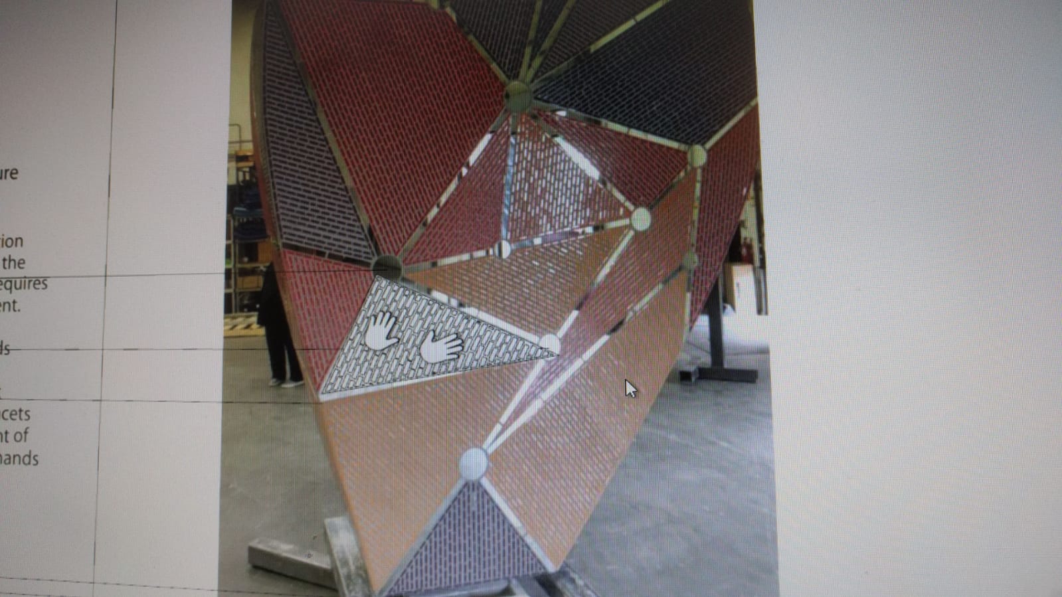
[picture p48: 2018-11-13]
images/sensor-frontend/design/initial-design.jpg

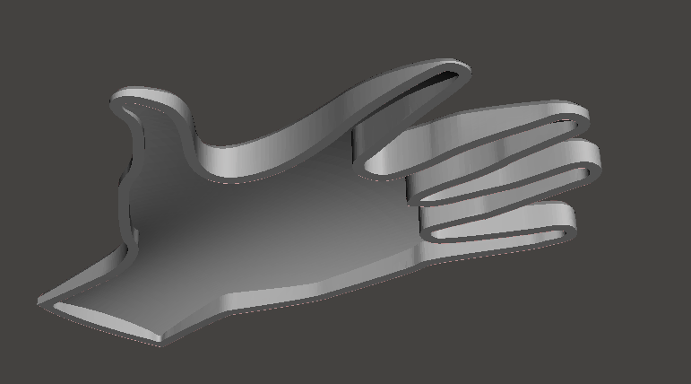
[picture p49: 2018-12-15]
images/sensor-frontend/design/steel-design-2.png

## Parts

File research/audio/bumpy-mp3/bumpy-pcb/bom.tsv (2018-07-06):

Name | Vendor | Part number | Count | Identifier
12.288 MHz crystal | Digikey | XC1771CT-ND | 1 | Y2
8 MHz crystal | Digikey | XC1271CT-ND | 1 | Y1
Power switcher | Digikey | 296-34595-5-ND | 1 | U1
Encoder wheel | Digikey | P13381SCT-ND | 1 | S2
8-bit shift register | Digikey | 568-2263-1-ND | 1 | U6
Green LED (1206) | Digikey | 160-1169-1-ND | 8 | LED1-8
2.8V buck regulator | Digikey | LM3671MF-2.8/NOPBCT-ND | 1 | U5
3.3V buck regulator | Digikey | LM3671MF-3.3/NOPBCT-ND | 1 | U4
2.2uH inductor | Digikey | 541-1236-1-ND | 2 | L1, L2
Slide switch | Digikey | 401-1999-1-ND | 1 | S1
MicroSD holder | Digikey | 732-3819-1-ND | 1 | U3
USB mini plug | Digikey | ED2992CT-ND | 1 | JP1
Audio jack | Digikey | CP-3523SJCT-ND | 1 | U7
6-pin FTDI header | Digikey | A106757-ND | 1 | JP2
6-pin SPI header | Digikey | A106478-ND | 1 | J1
Atmega32u4 | Digikey | ATMEGA32U4-AURCT-ND | 1 | U9
Max1555 charger | Digikey | MAX1555EZK+TCT-ND | 1 | U2
10 Ohm 0603 resistor | Digikey | P10GCT-ND | 3 | R17, R18, R19
22 Ohm 0603 resistor | Digikey | P22GCT-ND | 2 | R1, R2
75 Ohm 0603 resistor | Digikey | P75GCT-ND | 8 | R24-31
100 Ohm 0603 resistor | Digikey | P100GCT-ND | 2 | R20, R21
392 Ohm 0603 resistor | Digikey | P392HCT-ND | 1 | R5
10 Kohm 0603 resistor | Digikey | P10KGCT-ND | 7 | R3, R4, R10, R11, R22, R23
100 Kohm 0603 resistor | Digikey | P100KGCT-ND | 5 | R7, R12,R13, R14, R16
1 MOhm 0603 resistor | Digikey | P1.0MGCT-ND | 1 | R15
33 pF 0603 capacitor | Digikey | 1276-2267-1-ND | 4 | C5, C6, C11, C12
10 nF 0603 capacitor | Digikey | 445-1311-1-ND | 2 | C28, C29
47 nF 0603 capacitor | Digikey | 445-1313-1-ND | 1 | C27
0.1 uF 0603 capacitor | Digikey | 445-1314-1-ND | 12 | C2, C3, C8, C15, C16, C17, C19, C20, C21, C22, C23, C24, C25
1 uF 0603 capacitor | Digikey | 445-1322-1-ND | 4 | C4, C7, C18, C26
4.7 uF 0603 capacitor | Digikey | 445-5178-1-ND | 2 | C9, C10
10 uF 0603 capacitor | Digikey | 445-4112-1-ND | 5 | C1, C13, C14, C30, C31
1000 mAh Lithium battery | Sparkfun | PRT-00339 | 1 | JP3
MP3 codec | Sparkfun | COM-09398 | 1 | U8

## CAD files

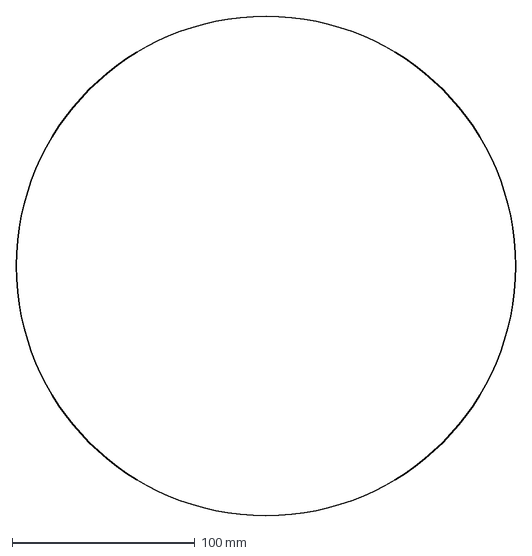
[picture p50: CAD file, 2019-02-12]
design/audio-rack/base-disc.dxf
273.0 x 273.0 mm

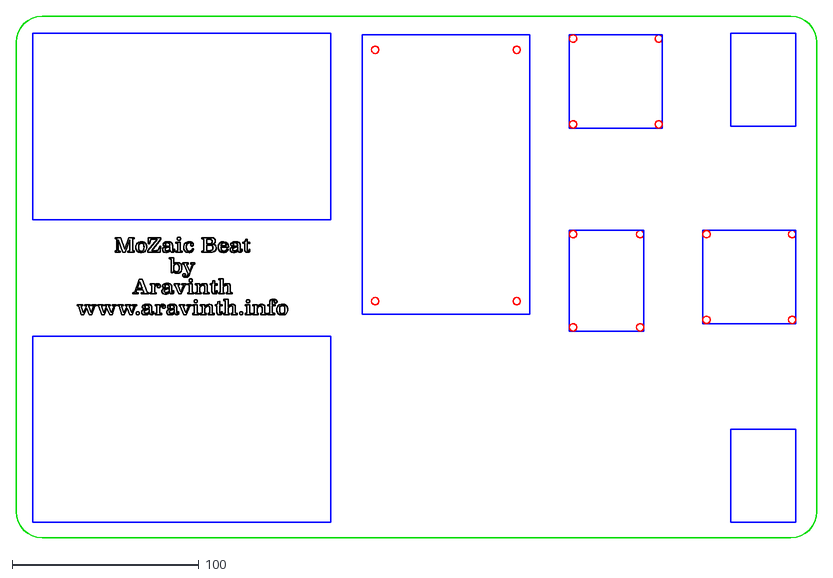
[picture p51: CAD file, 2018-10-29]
design/prototypes/acrylic-plate/proto-1.dxf
429.0 x 279.4

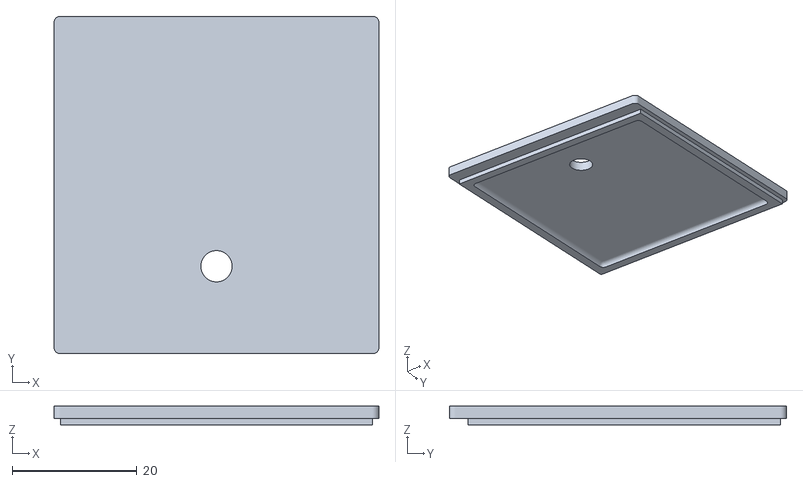
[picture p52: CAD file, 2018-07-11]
design/prototypes/mini-speaker-enclosure/enclosure-back.stl
52.0 x 54.0 x 3.00

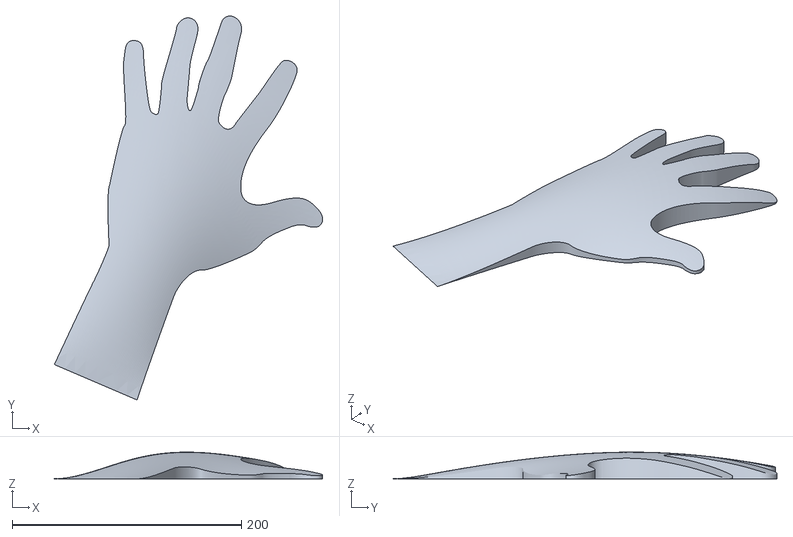
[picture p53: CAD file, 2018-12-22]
design/sensor-frontend/design-1-long/left-shell.stl
234.3 x 335.2 x 23.3

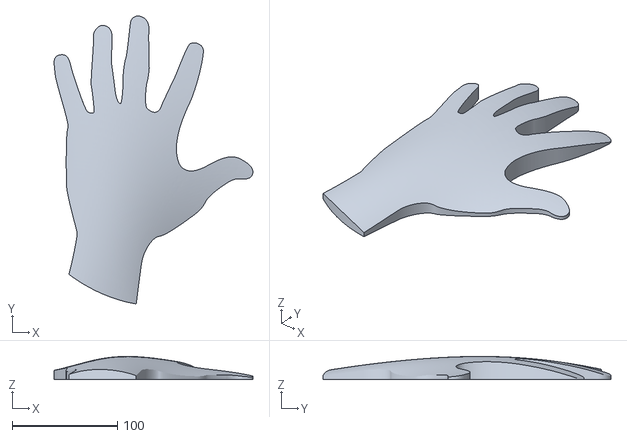
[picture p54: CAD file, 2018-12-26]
design/sensor-frontend/design-2-chamfer/left-shell.stl
189.2 x 274.0 x 22.0

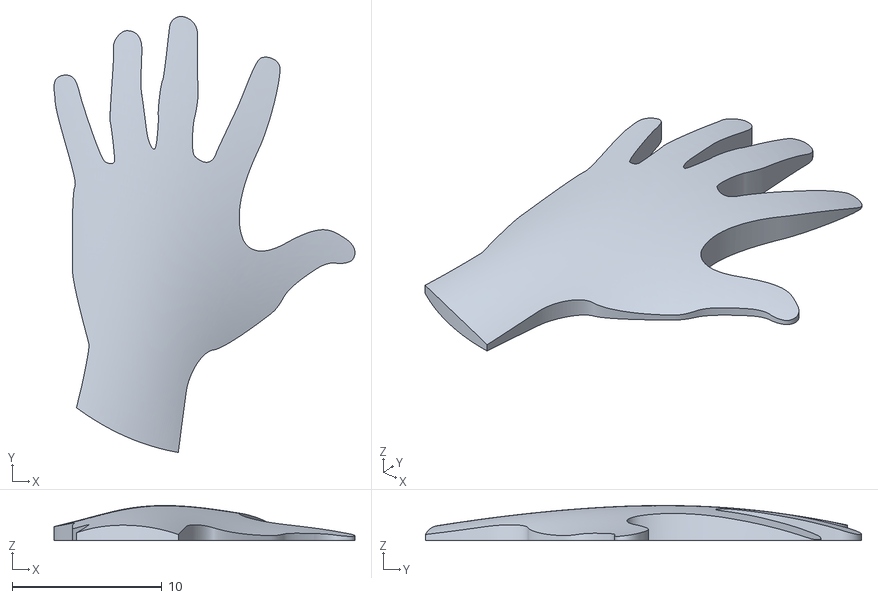
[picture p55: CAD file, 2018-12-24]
design/sensor-frontend/design-3-no-chamfer/left.stl
20.1 x 29.1 x 2.33

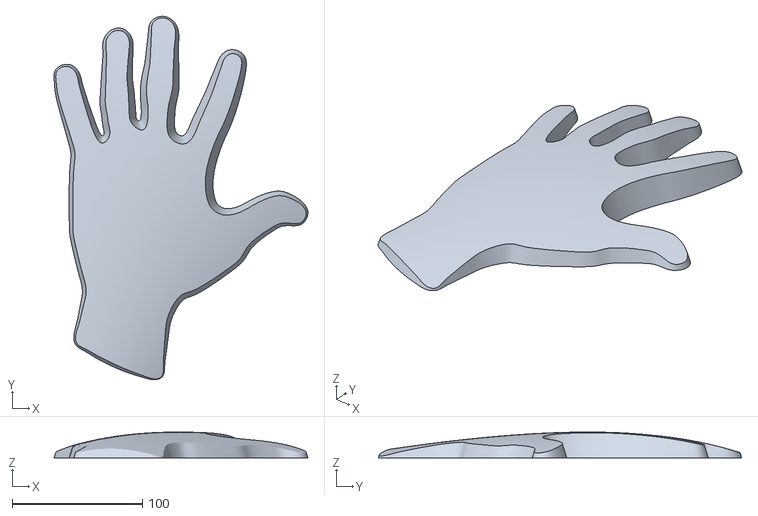
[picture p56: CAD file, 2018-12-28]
design/sensor-frontend/design-4-draft-chamfer/left-final.stl
194.9 x 278.9 x 19.9

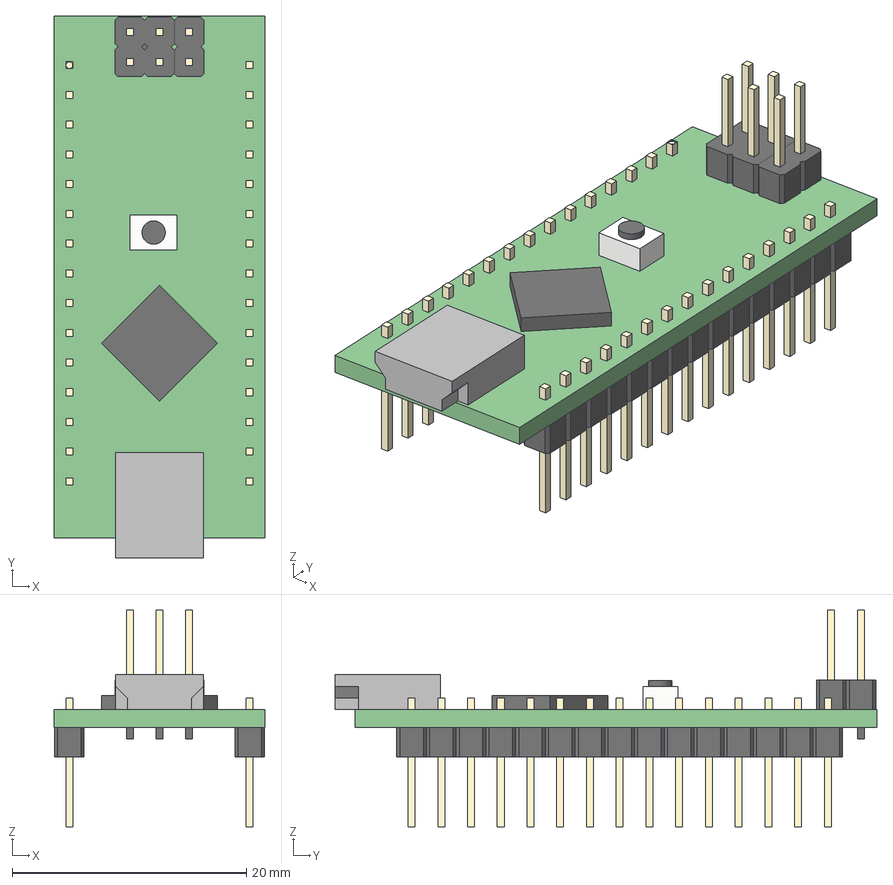
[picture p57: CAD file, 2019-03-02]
hardware/-resources/3d-models/arduino-nano.step
18.0 x 46.3 x 18.5 mm

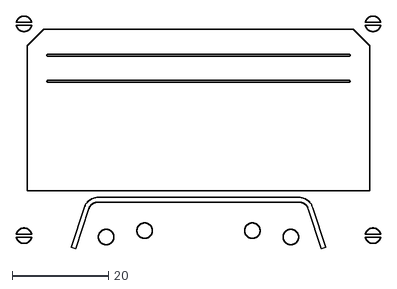
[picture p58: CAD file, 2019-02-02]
hardware/-resources/edgecut-silkscreen/ecg-cassette/ecg-cassette-silkscreen.dxf
75.6 x 48.3

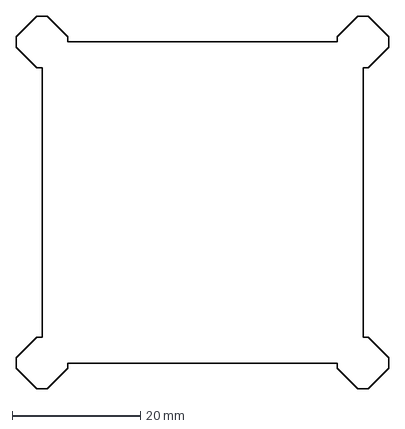
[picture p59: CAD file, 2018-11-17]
hardware/-resources/edgecut-silkscreen/ecg-module/ecg-module.dxf
58.0 x 58.0 mm

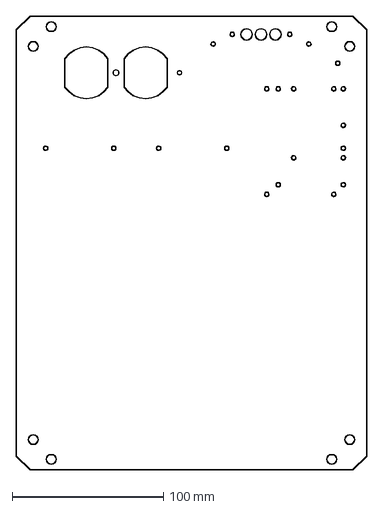
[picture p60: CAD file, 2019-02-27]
hardware/-resources/edgecut-silkscreen/heated-plate/heated-enclosure.dxf
231.8 x 300.0 mm

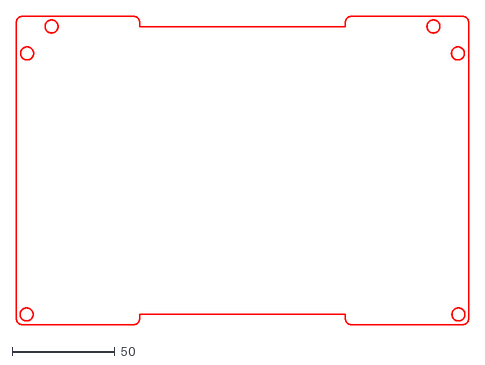
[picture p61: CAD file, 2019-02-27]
hardware/-resources/edgecut-silkscreen/motherboard/motherboard-mounting.dxf
220.0 x 150.0

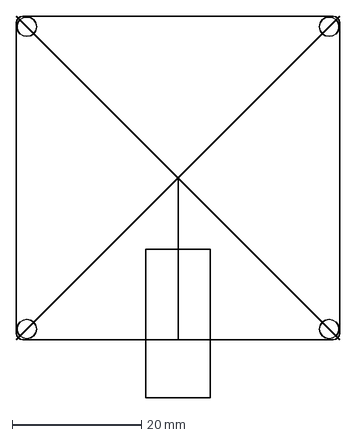
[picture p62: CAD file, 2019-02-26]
hardware/-resources/edgecut-silkscreen/wondom-dsp-board.dxf
50.0 x 59.0 mm

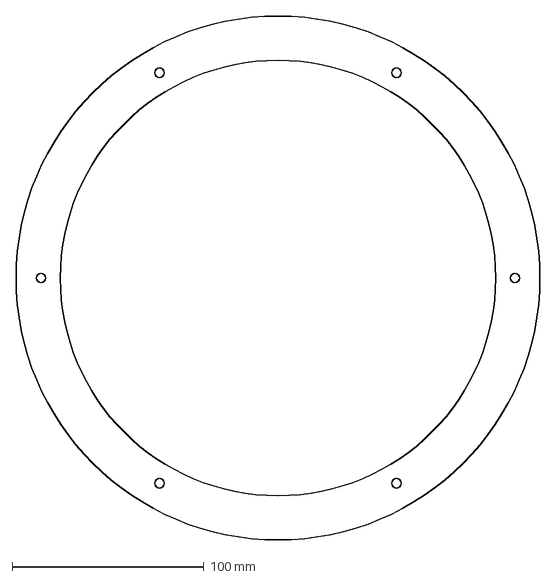
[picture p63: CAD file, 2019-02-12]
design/audio-rack/subwoofer-disc.dxf
273.0 x 273.0 mm

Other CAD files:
design/prototypes/mini-speaker-enclosure/enclosure-front.stl
design/sensor-frontend/design-1-long/left-filled.stl
design/sensor-frontend/design-2-chamfer/right-shell.stl
design/sensor-frontend/design-3-no-chamfer/right.stl
design/audio-rack/tweeter-disc.dxf
design/prototypes/mini-speaker-enclosure/mini-speaker-enclosure.f3d
design/sensor-frontend/design-1-long/left-right-mosaic.stp
design/sensor-frontend/design-1-long/right-shell.stl
design/sensor-frontend/design-2-chamfer/left-right-chamfer.stp
design/sensor-frontend/design-3-no-chamfer/left-right-no-chamfer.stp
design/sensor-frontend/design-4-draft-chamfer/right-final.stl
design/sensor-frontend/design-4-draft-chamfer/right-final.stp
hardware/-resources/3d-models/ecg-baseboard.step
hardware/-resources/3d-models/ecg-cassette.step
hardware/-resources/3d-models/keystone-5000.step
hardware/-resources/3d-models/mcu-cassette.step
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

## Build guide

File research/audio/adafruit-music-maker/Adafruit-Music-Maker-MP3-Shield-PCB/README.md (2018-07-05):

# Adafruit-Music-Maker-MP3-Shield-PCB
PCB files for the Adafruit Music Maker VS1053 (MP3/MIDI/WAV/Ogg...) Shield for Arduino

Format is EagleCAD schematic and board layout

For more details, check out the product page at

-----> https://www.adafruit.com/product/1788

-----> https://www.adafruit.com/product/1790

Adafruit invests time and resources providing this open source design, 
please support Adafruit and open-source hardware by purchasing 
products from Adafruit!

Designed by Adafruit Industries.  
Creative Commons Attribution, Share-Alike license, check license.txt for more information
All text above must be included in any redistribution

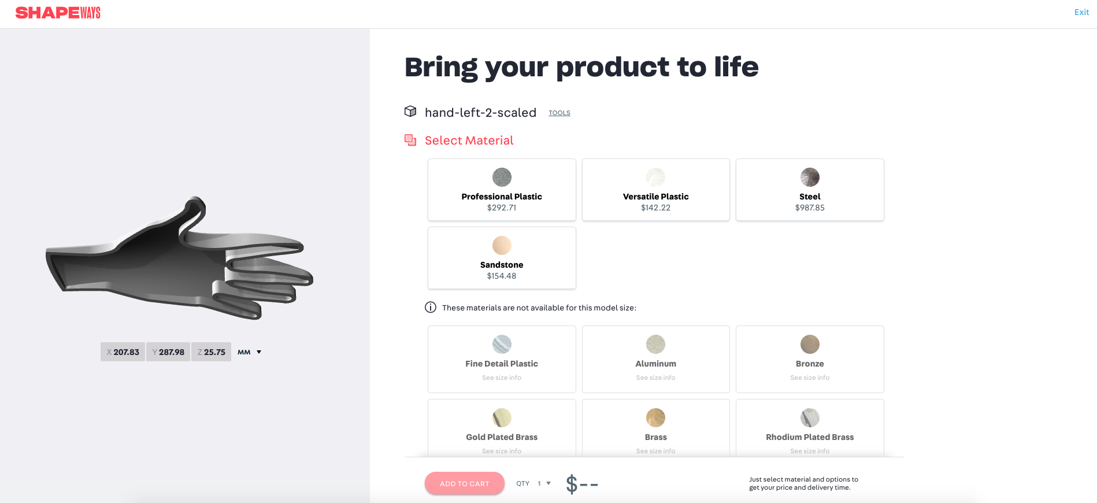
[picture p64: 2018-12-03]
images/sensor-frontend/prototype/3d-print-steel.png

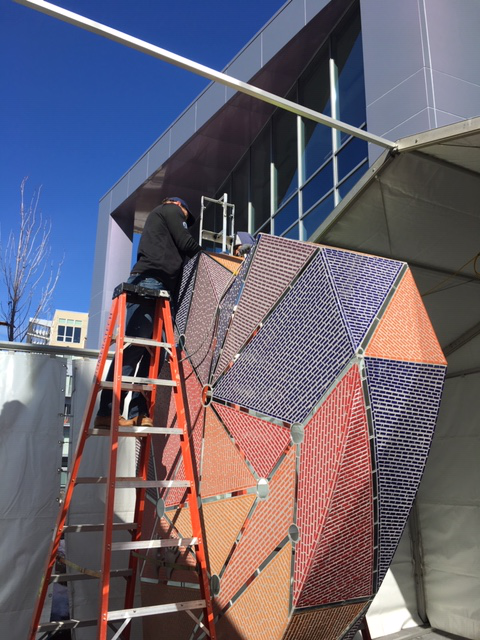
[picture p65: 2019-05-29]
images/behind-the-scenes/ara-speaker-installation.jpg

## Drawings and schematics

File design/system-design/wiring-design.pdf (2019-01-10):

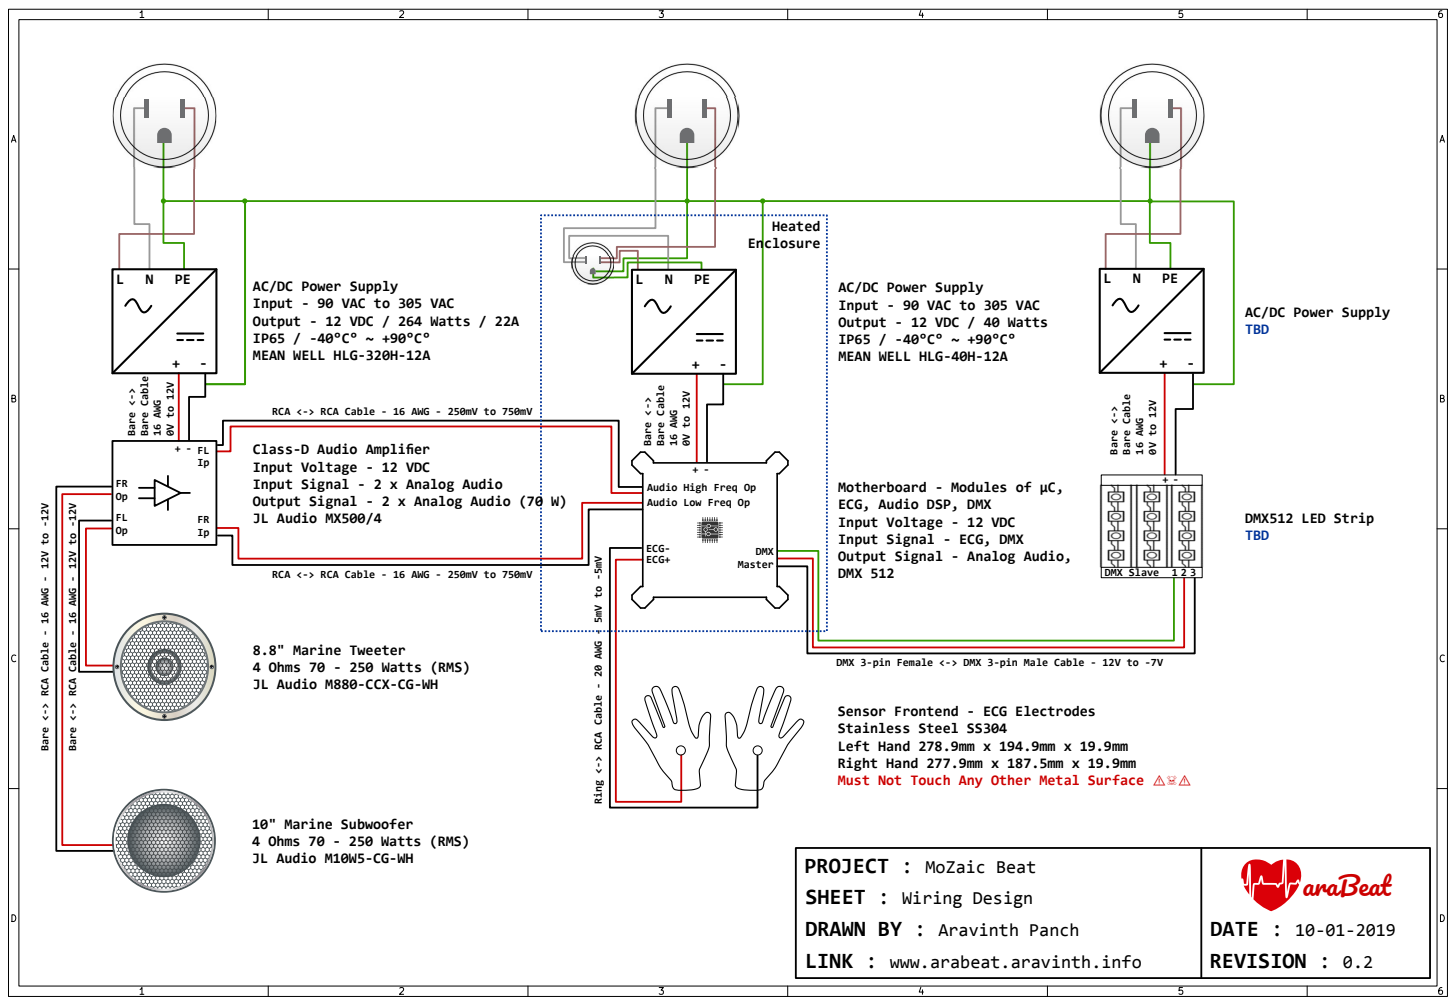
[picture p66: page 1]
DRAWN BY : Aravinth Panch; DATE : 10-01-2019; REVISION : 0.2; araBeat; ECG- ECG+; DMX Master; Heated Enclosure; Bare <->; Bare Cable; 16 AWG; DMX Slave 1 2 3; DMX512 LED Strip TBD

AC/DC Power Supply
Input - 90 VAC to 305 VAC
Output - 12 VDC / 264 Watts / 22A
MEAN WELL HLG-320H-12A

Output - 12 VDC / 40 Watts
MEAN WELL HLG-40H-12A

TBD

Audio Low Freq Op Bare <-> Bare Cable 16 AWG 0V to 12V

RCA <-> RCA Cable - 16 AWG - 250mV to 750mV

Class-D Audio Amplifier
Input Voltage - 12 VDC
Input Signal - 2 x Analog Audio
Output Signal - 2 x Analog Audio (70 W)
JL Audio MX500/4

Audio High Freq Op

Motherboard - Modules of μC,
ECG, Audio DSP, DMX
Input Signal - ECG, DMX
Output Signal - Analog Audio,
DMX 512

Bare <-> RCA Cable - 16 AWG - 12V to -12V

Ring <-> RCA Cable - 20 AWG - 5mV to -5mV

8.8" Marine Tweeter
4 Ohms 70 - 250 Watts (RMS)
JL Audio M880-CCX-CG-WH

DMX 3-pin Female <-> DMX 3-pin Male Cable - 12V to -7V

Sensor Frontend - ECG Electrodes
Stainless Steel SS304
Left Hand 278.9mm x 194.9mm x 19.9mm
Right Hand 277.9mm x 187.5mm x 19.9mm
Must Not Touch Any Other Metal Surface ⚠☠⚠

10" Marine Subwoofer
JL Audio M10W5-CG-WH

PROJECT : MoZaic Beat
SHEET : Wiring Design
LINK : www.arabeat.aravinth.info

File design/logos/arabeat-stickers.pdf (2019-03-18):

# araBeat

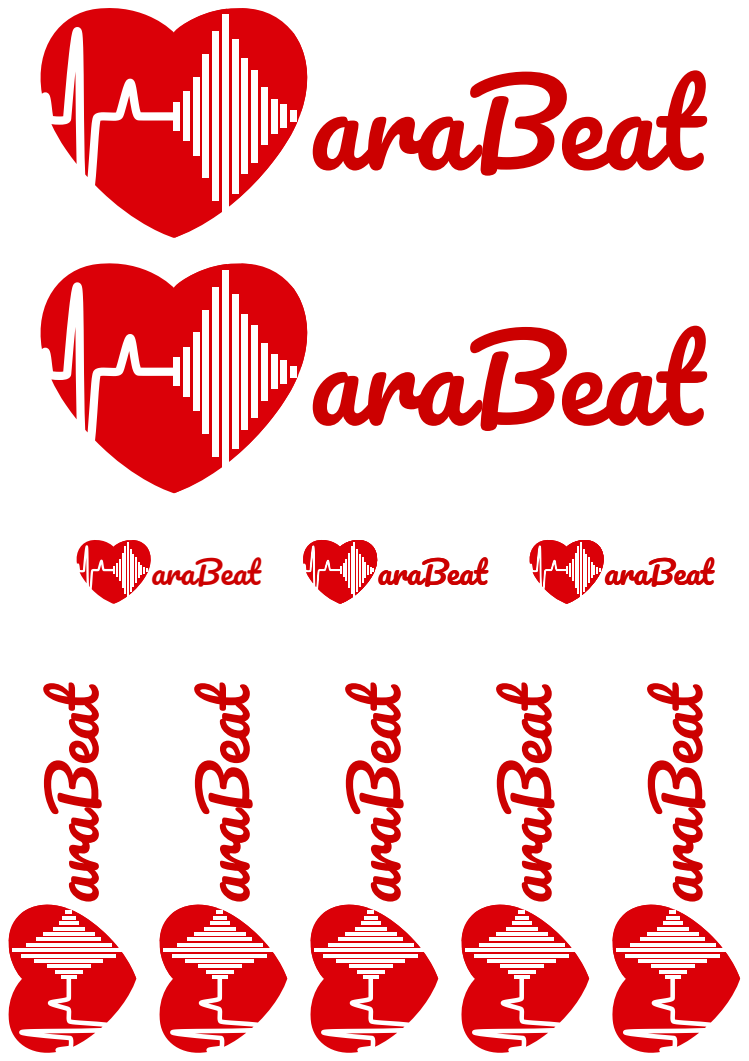
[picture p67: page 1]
araBeat

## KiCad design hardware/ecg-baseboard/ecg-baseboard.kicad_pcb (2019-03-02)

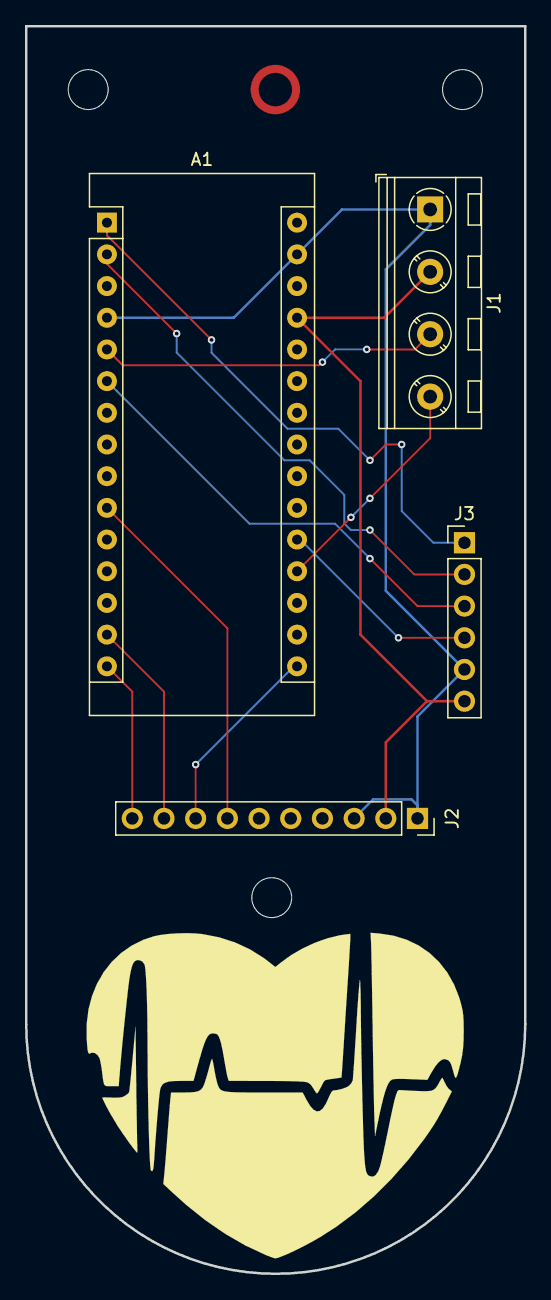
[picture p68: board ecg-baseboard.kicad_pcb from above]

Board: 2 copper layers, 40.0 x 100.0 mm, 4 parts (0 on the bottom side), 12 nets.

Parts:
A1: Arduino_Nano_v3.x; Arduino_Nano
J1: Screw_Terminal_01x04; TerminalBlock_RND_205-00047_1x04_P5.00mm_Horizontal
J2: Protocentral MAX30003; PinSocket_1x10_P2.54mm_Vertical
J3: Conn_01x06; PinHeader_1x06_P2.54mm_Vertical

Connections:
/VCC: A1.27, J1.2, J2.2, J3.6
GND: A1.4, A1.29, J1.1, J2.1, J2.3, J3.5
unnamed: A1.1, J3.1
unnamed: A1.2, J3.2
unnamed: A1.5, J1.3
unnamed: A1.6, J3.3
unnamed: A1.10, J2.7
unnamed: A1.14, J2.9
unnamed: A1.15, J2.10
unnamed: A1.16, J2.8
unnamed: A1.19, J1.4
unnamed: A1.20, J3.4

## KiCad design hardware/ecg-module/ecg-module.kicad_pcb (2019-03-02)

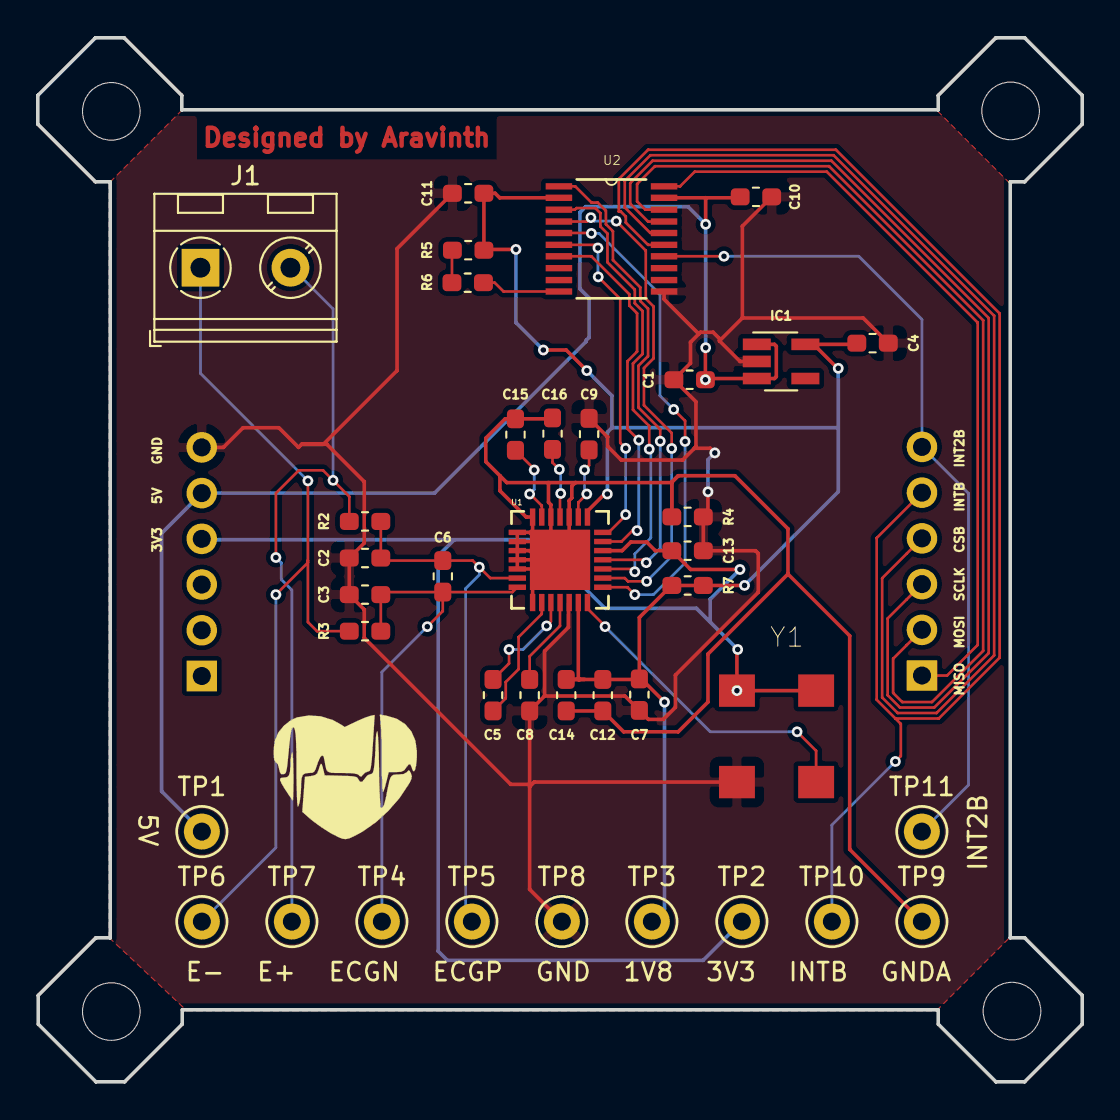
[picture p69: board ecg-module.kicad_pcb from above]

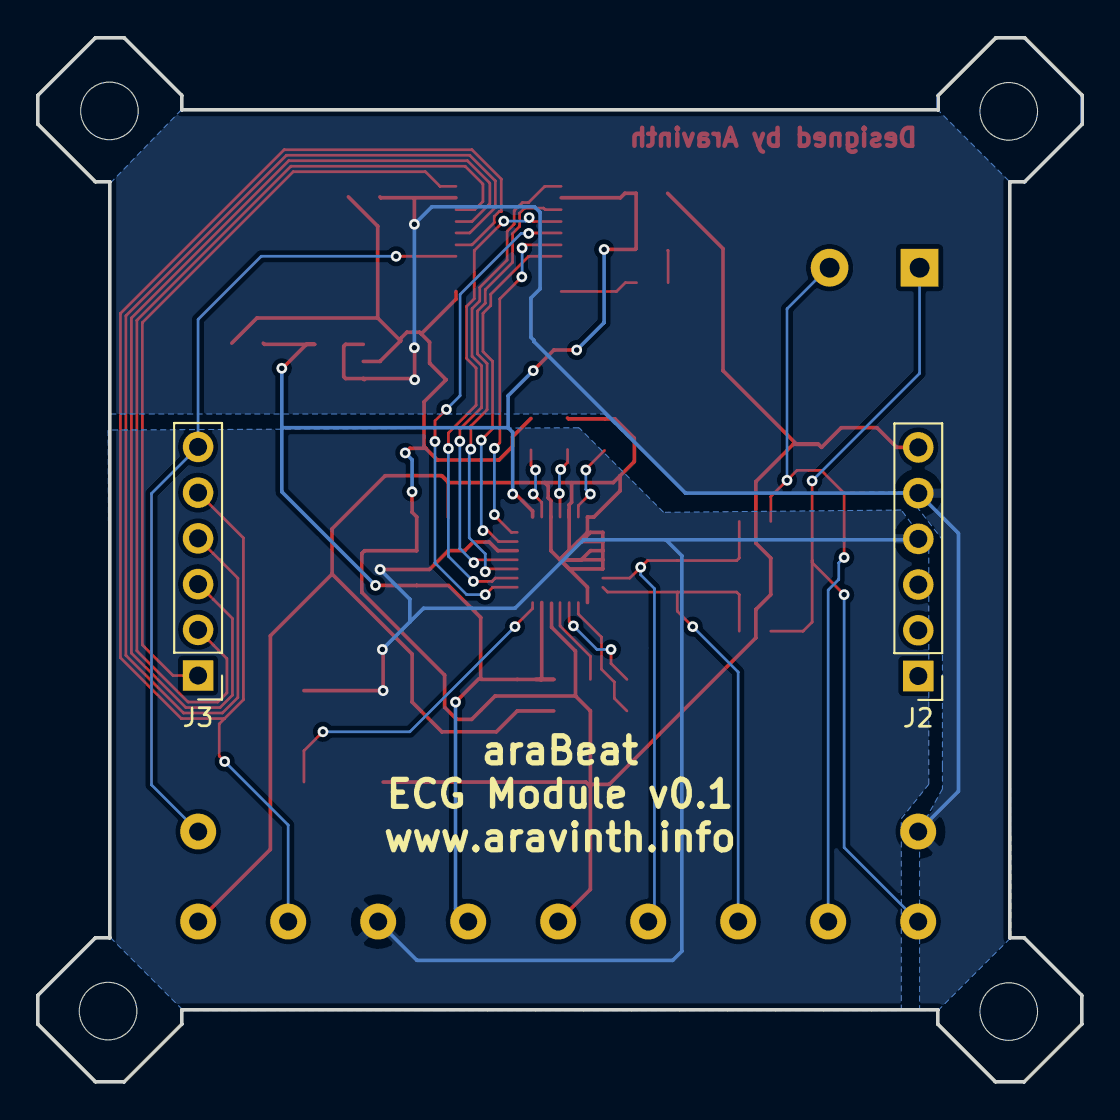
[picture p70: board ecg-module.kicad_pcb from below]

Board: 2 copper layers, 58.0 x 58.0 mm, 40 parts (2 on the bottom side), 30 nets.

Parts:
C1, C4, C5, C7, C12, C15: 1uF; C_0603_1608Metric_Pad1.05x0.95mm_HandSolder
C2, C3: 10pF; C_0603_1608Metric_Pad1.05x0.95mm_HandSolder
C6, C8: 1000pF; C_0603_1608Metric_Pad1.05x0.95mm_HandSolder
C9, C13, C16: 10uF; C_0603_1608Metric_Pad1.05x0.95mm_HandSolder
C10, C11, C14: 0.1uF; C_0603_1608Metric_Pad1.05x0.95mm_HandSolder
IC1: AP2112K-1.8TRG1; SOT-23-5_HandSoldering
J1: ST_01x02; TerminalBlock_RND_205-00045_1x02_P5.00mm_Horizontal
J2: LEFT-UI; PinHeader_1x06_P2.54mm_Vertical
J3: RIGHT-UI; PinHeader_1x06_P2.54mm_Vertical
R2, R3: 49.9K; R_0603_1608Metric_Pad1.05x0.95mm_HandSolder
R4, R5, R7: 0R; R_0603_1608Metric_Pad1.05x0.95mm_HandSolder
R6: 10K; R_0603_1608Metric_Pad1.05x0.95mm_HandSolder
TP1: 5V; TestPoint_Keystone_5000-5004_Miniature
TP2: 3V3; TestPoint_Keystone_5000-5004_Miniature
TP3: 1V8; TestPoint_Keystone_5000-5004_Miniature
TP4: ECGN; TestPoint_Keystone_5000-5004_Miniature
TP5: ECGP; TestPoint_Keystone_5000-5004_Miniature
TP6: E-; TestPoint_Keystone_5000-5004_Miniature
TP7: E+; TestPoint_Keystone_5000-5004_Miniature
TP8: GND; TestPoint_Keystone_5000-5004_Miniature
TP9: GNDA; TestPoint_Keystone_5000-5004_Miniature
TP10: INTB; TestPoint_Keystone_5000-5004_Miniature
TP11: INT2B; TestPoint_Keystone_5000-5004_Miniature
U1: 21-0140L_T2855-8
U2: SOP65P640X120-20N
Y1: OSCSC508P500X700X155-4N

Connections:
+1V8: C4.1, C7.1, C11.2, C12.1, C14.1, IC1.5, R5.2, R7.1, R7.2, TP3.1, U1.13, U1.22, U2.2
+3V3: C13.1, J2.4, TP2.1, U1.19, Y1.1, Y1.4
+5V: C1.1, C10.2, IC1.1, IC1.3, J2.5, TP1.1, U2.19
CSB_1.8V: U1.15, U2.5
CSB_5V: J3.4, U2.16
GND: C1.2, C2.1, C3.2, C4.2, C7.2, C8.2, C9.2, C10.1, C11.1, C13.2, IC1.2, J2.6, R4.2, TP8.1, U1.12, U2.11, Y1.2
GNDA: C12.2, C14.2, C15.2, C16.2, R4.1, TP9.1, U1.1, U1.2, U1.3, U1.4, U1.5, U1.8, U1.24, U1.26, U1.28, U1.29
INT2B_1.8V: U1.20, U2.7
INT2B_5V: J3.6, TP11.1, U2.14
INTB_1.8V: U1.21, U2.6
INTB_5V: J3.5, TP10.1, U2.15
MISO_1.8V: U1.18, U2.1
MISO_5V: J3.1, U2.20
MOSI_1.8V: U1.17, U2.3
MOSI_5V: J3.2, U2.18
unnamed: C2.2, C6.2, R2.1, TP5.1, U1.6
unnamed: C3.1, C6.1, R3.1, TP4.1, U1.7
unnamed: C5.1, U1.9
unnamed: C5.2, U1.10
unnamed: C8.1, U1.11
unnamed: C9.1, U1.23
unnamed: C15.1, U1.27
unnamed: C16.1, U1.25
unnamed: J1.1, R3.2, TP6.1
unnamed: J1.2, R2.2, TP7.1
unnamed: R5.1, R6.2
unnamed: R6.1, U2.10
unnamed: U1.14, Y1.3
SCLK_1.8V: U1.16, U2.4
SCLK_5V: J3.3, U2.17

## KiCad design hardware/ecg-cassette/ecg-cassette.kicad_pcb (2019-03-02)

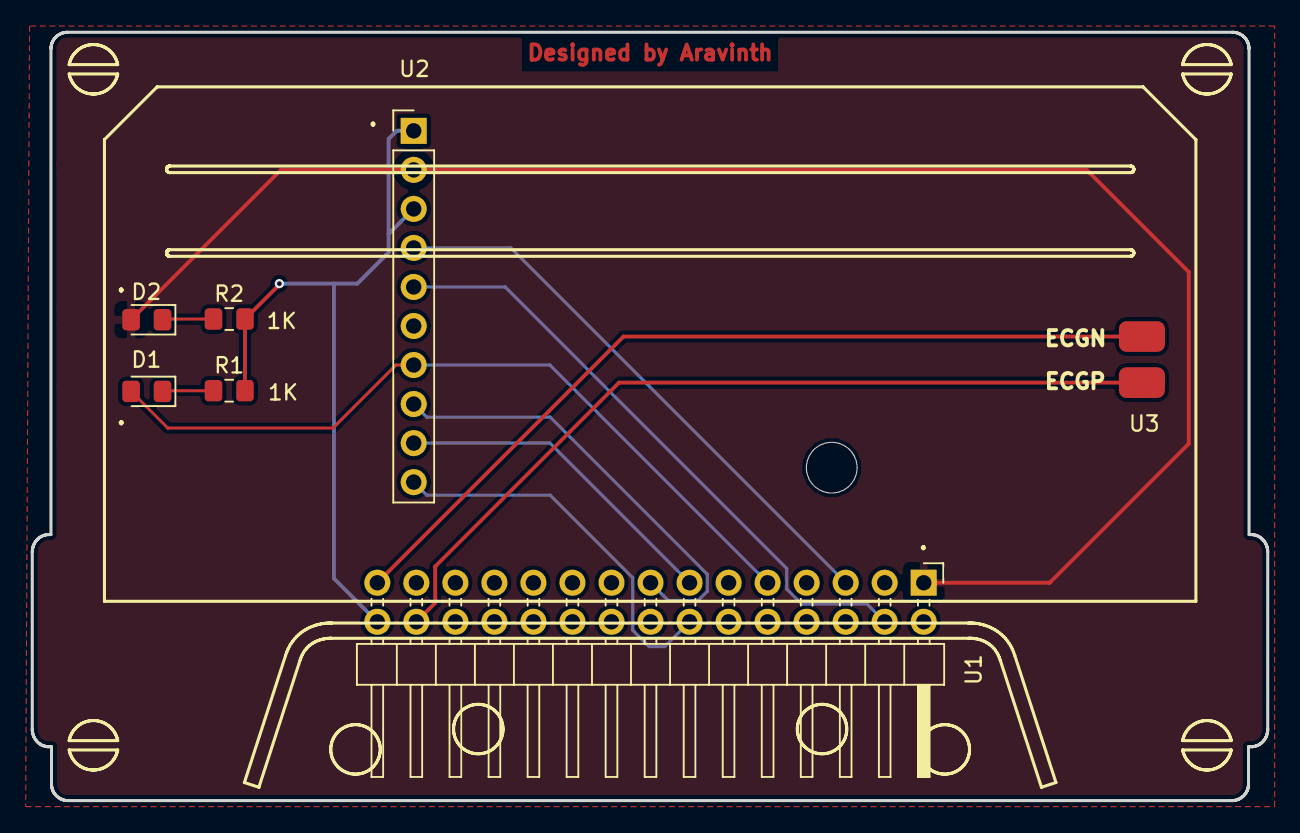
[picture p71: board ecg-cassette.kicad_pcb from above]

Board: 2 copper layers, 80.4 x 50.0 mm, 9 parts (0 on the bottom side), 12 nets.

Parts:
D1: RED_STATUS_LED; LED_0805_2012Metric_Pad1.15x1.40mm_HandSolder
D2: GREEN_PWR_LED; LED_0805_2012Metric_Pad1.15x1.40mm_HandSolder
MARK: CASSETTE-MARK; MCU-CASSETTE-MARK
R1, R2: 1K; R_0805_2012Metric_Pad1.15x1.40mm_HandSolder
SILK: CASSETTE-SILKSCREEN; ECG-CASSETTE-SILKSCREEN-EDGECUT
U1: 02x15_PIN_HEADER_SOCKET; PinHeader_2x15_P2.54mm_Horizontal
U2: MAX30003
U3: ECG-WIRE-TO-BOARD

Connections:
5V: D2.2, U1.1, U2.2
D2: U1.4, U2.5
D3: U1.5, U2.4
D7: D1.2, U1.9, U2.7
D11: U1.13, U2.9
D12: U1.14, U2.10
D13: U1.15, U2.8
ECGN: U1.29, U3.1
ECGP: U1.28, U3.2
GND: R1.2, R2.2, U1.30, U2.1, U2.3
unnamed: D1.1, R1.1
unnamed: D2.1, R2.1

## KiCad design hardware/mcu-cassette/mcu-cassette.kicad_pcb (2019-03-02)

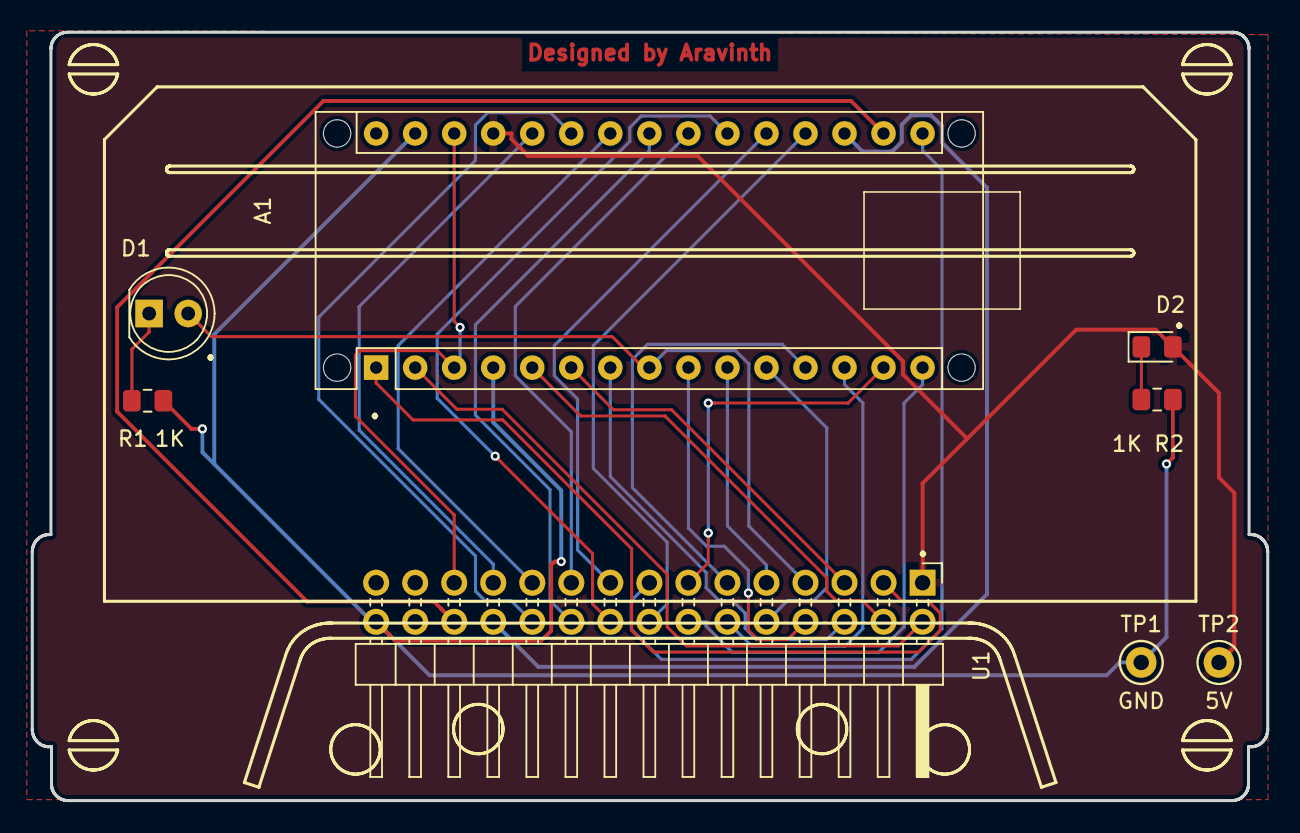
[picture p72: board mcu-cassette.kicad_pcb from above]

Board: 2 copper layers, 80.4 x 50.0 mm, 10 parts (0 on the bottom side), 29 nets.

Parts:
A1: Arduino_Nano_v3.x; Arduino_Nano_WithMountingHoles
D1: RED_HEART_LED; LED_D5.0mm
D2: GREEN_PWR_LED; LED_0805_2012Metric_Pad1.15x1.40mm_HandSolder
R1, R2: 1K; R_0805_2012Metric_Pad1.15x1.40mm_HandSolder
SLK-FR: CASSETTE-SILKSCREEN; MCU-CASSETTE-SILKSCREEN-EDGECUT
SLK-MK: CASSETTE-MARK; MCU-CASSETTE-MARK
TP1: GND; TestPoint_Keystone_5000-5004_Miniature
TP2: 5V; TestPoint_Keystone_5000-5004_Miniature
U1: 02x15_PIN_HEADER_SOCKET; PinHeader_2x15_P2.54mm_Horizontal

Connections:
3V3: A1.17, U1.26
5V: A1.27, D2.2, TP2.1, U1.1
A0: A1.19, U1.16
A1: A1.20, U1.17
A2: A1.21, U1.18
A3: A1.22, U1.19
A4: A1.23, U1.20
A5: A1.24, U1.21
A6: A1.25, U1.22
A7: A1.26, U1.23
AREF: A1.18, U1.24
D0: A1.2, U1.2
D1: A1.1, U1.3
D2: A1.5, U1.4
D3: A1.6, U1.5
D4: A1.7, U1.6
D5: A1.8, D1.2, U1.7
D6: A1.9, U1.8
D7: A1.10, U1.9
D8: A1.11, U1.10
D9: A1.12, U1.11
D10: A1.13, U1.12
D11: A1.14, U1.13
D12: A1.15, U1.14
D13: A1.16, U1.15
GND: A1.4, A1.29, R1.2, R2.2, TP1.1, U1.30
unnamed: D1.1, R1.1
unnamed: D2.1, R2.1
RST: A1.3, A1.28, U1.25

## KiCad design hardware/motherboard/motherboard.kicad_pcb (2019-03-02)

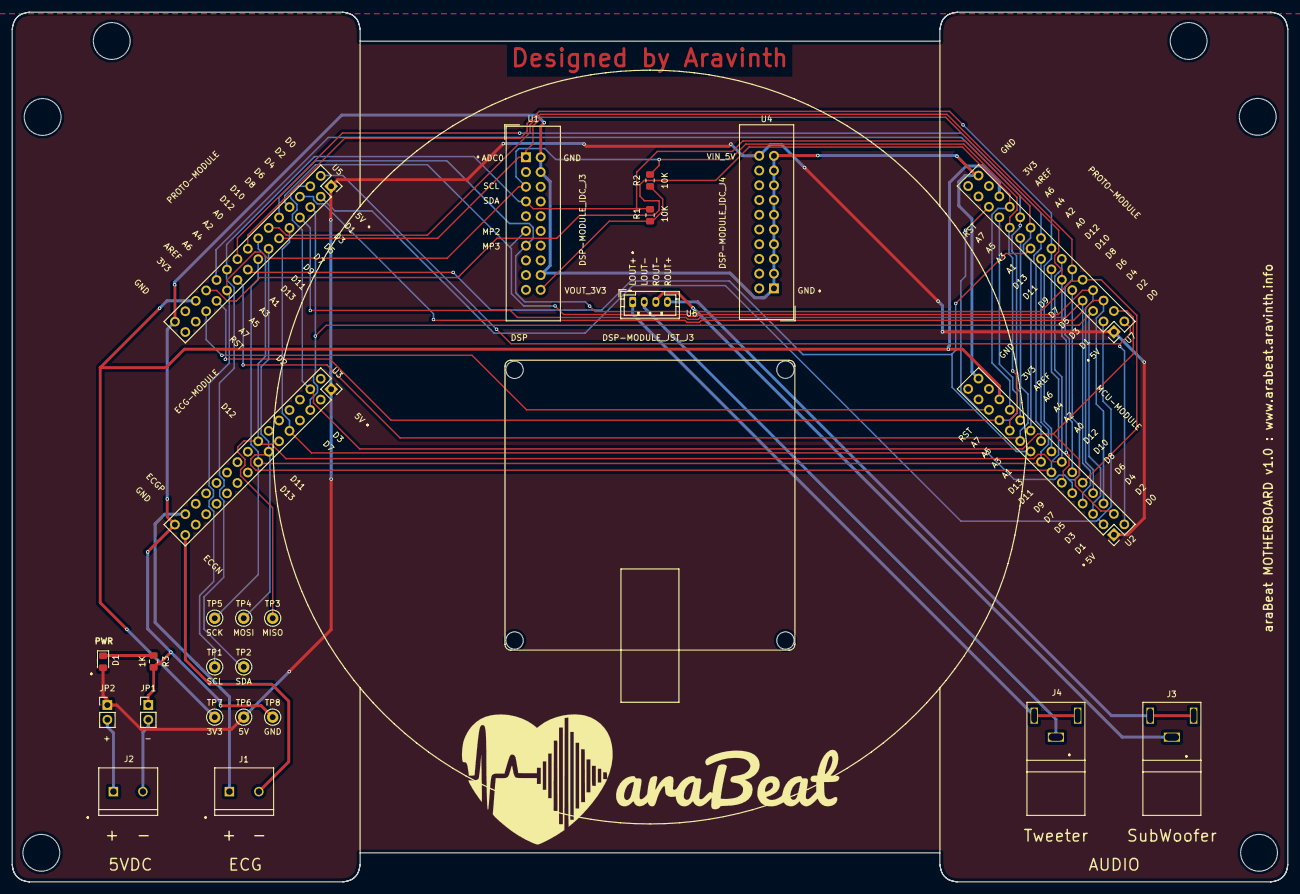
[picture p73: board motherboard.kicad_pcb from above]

Board: 2 copper layers, 220.0 x 150.0 mm, 27 parts (0 on the bottom side), 37 nets.

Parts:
D1: GREEN_PWR_LED; LED_0805_2012Metric_Pad1.15x1.40mm_HandSolder
DSP: WONDOM-DSP
J1: 01x02_Screw_ECG; 282837-2
J2: 01x02_Screw_5VDC_IN; 282837-2
J3: RCA_L_Female_Tweeter; PJRAN1X1U01X
J4: RCA_R_Female_Sub; PJRAN1X1U01X
JP1: GND_Jumper; 382811-8
JP2: 5V_Jumper; 382811-8
MOTHERBOARD: MOTHERBOARD-SILKSCREEN-EDGECUT-MARK
R1, R2: 10K; R_0805_2012Metric_Pad1.15x1.40mm_HandSolder
R3: 1K; R_0805_2012Metric_Pad1.15x1.40mm_HandSolder
TP1: SCL; TestPoint_Keystone_5000-5004_Miniature
TP2: SDA; TestPoint_Keystone_5000-5004_Miniature
TP3: MISO; TestPoint_Keystone_5000-5004_Miniature
TP4: MOSI; TestPoint_Keystone_5000-5004_Miniature
TP5: SCK; TestPoint_Keystone_5000-5004_Miniature
TP6: 5V; TestPoint_Keystone_5000-5004_Miniature
TP7: 3V3; TestPoint_Keystone_5000-5004_Miniature
TP8: GND; TestPoint_Keystone_5000-5004_Miniature
U1: DSP-MODULE_IDC_J3; IDC-Header_2x10_P2.54mm_Vertical
U2: MCU-MODULE; PinSocket_2x15_P2.54mm_Vertical
U3: ECG-MODULE; PinSocket_2x15_P2.54mm_Vertical
U4: DSP-MODULE_IDC_J4; IDC-Header_2x10_P2.54mm_Vertical
U5, U7: PROTO-MODULE; PinSocket_2x15_P2.54mm_Vertical
U6: DSP-MODULE_JST_J3; JST_PH_B4B-PH-K_1x04_P2.00mm_Vertical

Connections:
3V3: TP7.1, U2.26, U5.26, U7.26
5V: D1.2, JP2.1, TP6.1, U2.1, U3.1, U4.20, U5.1, U7.1
A0: U2.16, U5.16, U7.16
A1: U2.17, U5.17, U7.17
A2: U2.18, U5.18, U7.18
A3: U2.19, U5.19, U7.19
A4: R1.2, TP2.1, U1.7, U2.20, U5.20, U7.20
A5: R2.2, TP1.1, U1.5, U2.21, U5.21, U7.21
A6: U2.22, U5.22, U7.22
A7: U2.23, U5.23, U7.23
AREF: U2.24, U5.24, U7.24
D0: U2.2, U5.2, U7.2
D1: U2.3, U5.3, U7.3
D2: U2.4, U3.4, U5.4, U7.4
D3: U2.5, U3.5, U5.5, U7.5
D4: U2.6, U5.6, U7.6
D5: U2.7, U5.7, U7.7
D6: U1.11, U2.8, U5.8, U7.8
D7: U2.9, U3.9, U5.9, U7.9
D8: U1.13, U2.10, U5.10, U7.10
D9: U1.1, U2.11, U5.11, U7.11
D10: U2.12, U5.12, U7.12
D11: TP4.1, U2.13, U3.13, U5.13, U7.13
D12: TP3.1, U2.14, U3.14, U5.14, U7.14
D13: TP5.1, U2.15, U3.15, U5.15, U7.15
ECGN: J1.2, U3.29
ECGP: J1.1, U3.28
GND: JP1.1, R3.2, TP8.1, U1.2, U1.4, U1.18, U2.30, U3.30, U4.1, U4.3, U4.5, U4.7, U4.9, U4.11, U4.13, U4.15, U4.17, U4.19, U5.30, U7.30
LOUT+: J4.2, J4.3, U6.1
LOUT-: J4.1, U6.2
unnamed: D1.1, R3.1
unnamed: J2.1, JP2.2
unnamed: J2.2, JP1.2
unnamed: R1.1, R2.1, U1.20
ROUT+: J3.2, J3.3, U6.4
ROUT-: J3.1, U6.3
RST: U2.25, U5.25, U7.25

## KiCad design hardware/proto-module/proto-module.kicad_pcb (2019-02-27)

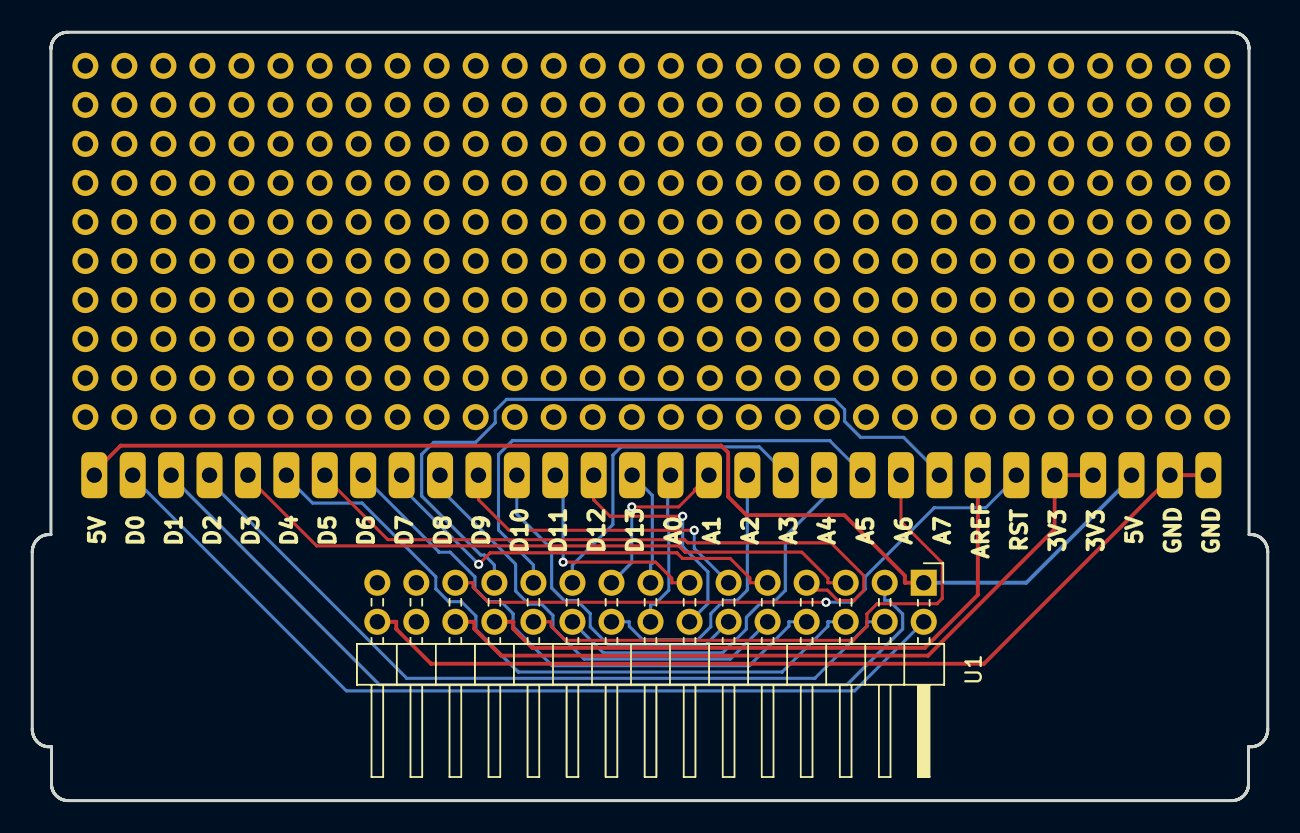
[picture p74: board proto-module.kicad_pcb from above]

Board: 2 copper layers, 80.4 x 50.0 mm, 3 parts (0 on the bottom side), 27 nets.

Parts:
J1: Conn_01x30; PERF-PADS
PERF: PERF-BOARD
U1: 02x15_PIN_HEADER_SOCKET; PinHeader_2x15_P2.54mm_Horizontal

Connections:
3V3: J1.26, J1.27, U1.26
5V: J1.1, J1.28, U1.1
A0: J1.16, U1.16
A1: J1.17, U1.17
A2: J1.18, U1.18
A3: J1.19, U1.19
A4: J1.20, U1.20
A5: J1.21, U1.21
A6: J1.22, U1.22
A7: J1.23, U1.23
AREF: J1.24, U1.24
D0: J1.2, U1.2
D1: J1.3, U1.3
D2: J1.4, U1.4
D3: J1.5, U1.5
D4: J1.6, U1.6
D5: J1.7, U1.7
D6: J1.8, U1.8
D7: J1.9, U1.9
D8: J1.10, U1.10
D9: J1.11, U1.11
D10: J1.12, U1.12
D11: J1.13, U1.13
D12: J1.14, U1.14
D13: J1.15, U1.15
GND: J1.29, J1.30, U1.30
RST: J1.25, U1.25

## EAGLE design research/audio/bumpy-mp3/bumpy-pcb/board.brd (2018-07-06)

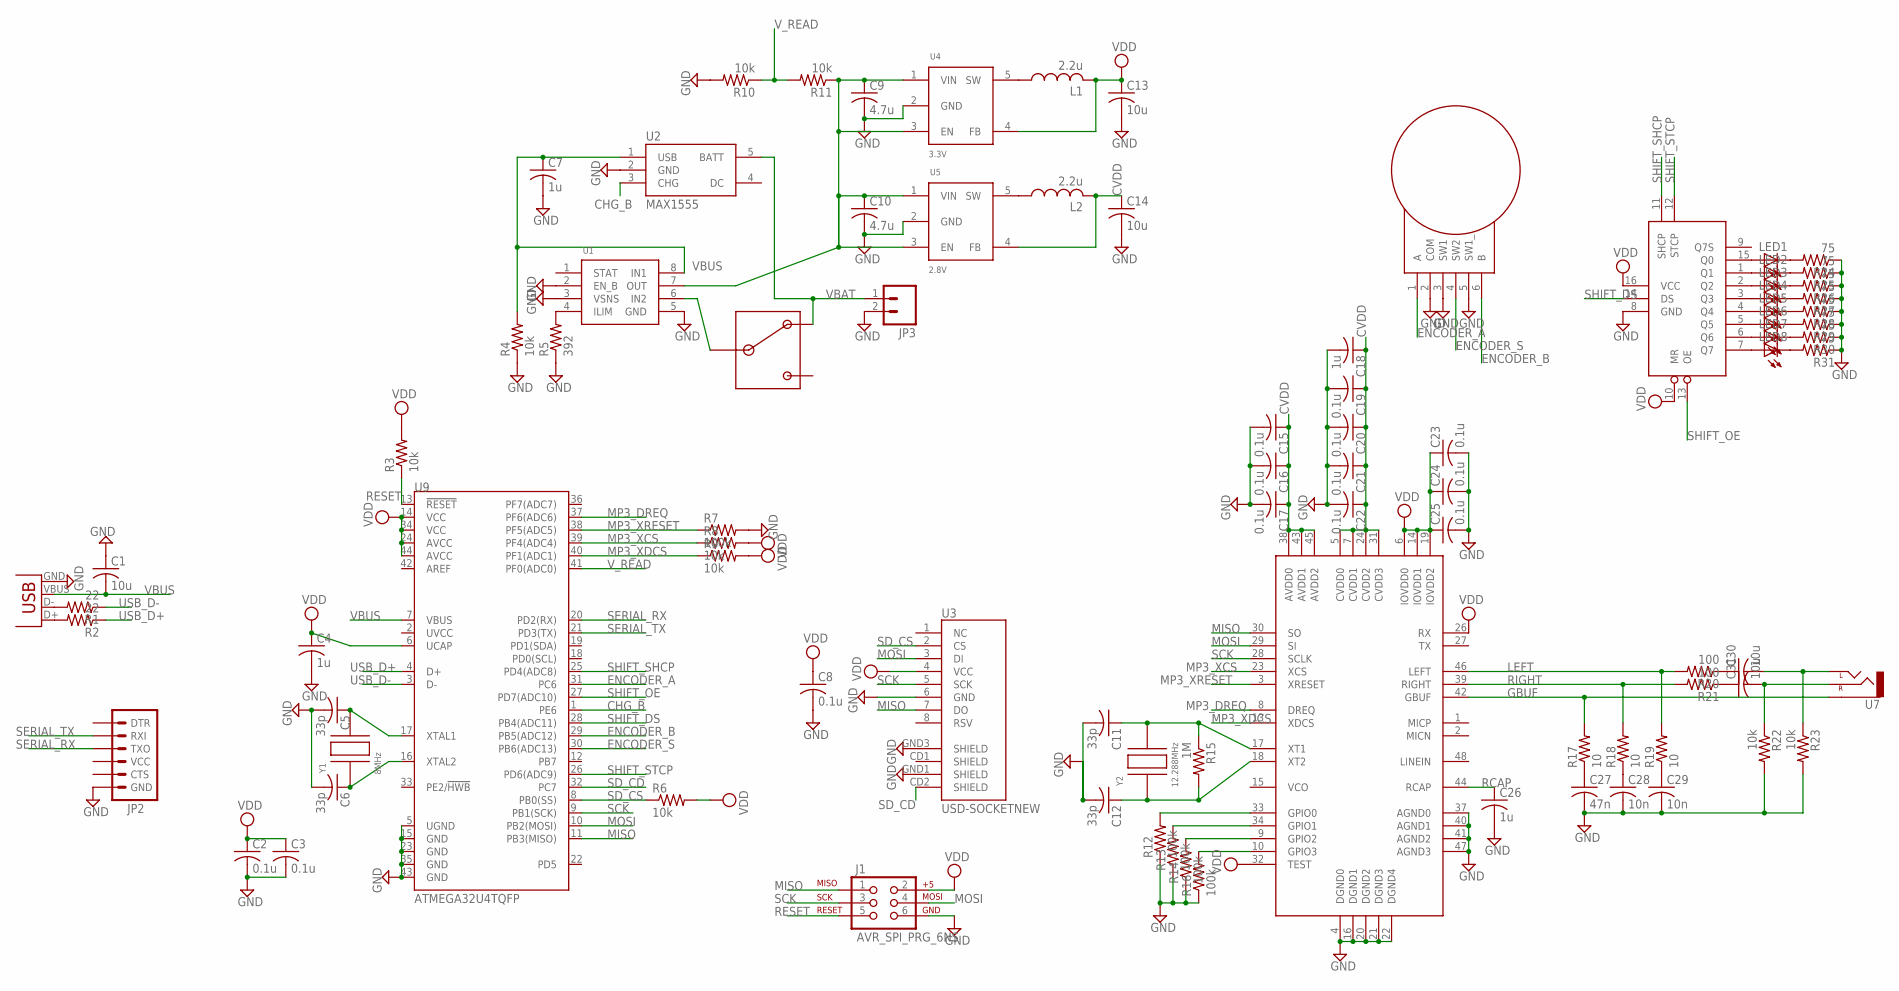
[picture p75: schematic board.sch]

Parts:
C1, C13, C14, C30, C31: 10u; C0603K
C2, C3, C8, C15, C16, C17, C19, C20, C21, C22, C23, C24, C25: 0.1u; C0603K
C4, C7, C18, C26: 1u; C0603K
C5, C6, C11, C12: 33p; C0603K
C9, C10: 4.7u; C0603K
C27: 47n; C0603K
C28, C29: 10n; C0603K
J1: AVR_SPI_PRG_6NS; 2X3-NS
JP1: USBSMD; USB-MINIB
JP2: ARDUINO_SERIAL_PROGRAMLOCK; 1X06_LOCK
JP3: M02PTH; 1X02
L1, L2: 2.2u; IHLP-2020CZ-11
LED1, LED2, LED3, LED4, LED5, LED6, LED7, LED8: LED1206; LED-1206
R1, R2: 22; R0603W
R3, R4, R10, R11: 10k; R0603
R5: 392; R0603
R6, R8, R9, R22, R23: 10k; R0603W
R7, R12, R13, R14, R16: 100k; R0603W
R15: 1M; R0603
R17, R18, R19: 10; R0603W
R20, R21: 100; R0603W
R24, R25, R26, R27, R28, R29, R30, R31: 75; R0603W
S1: JS102011SAQN
S2: EVQ-WKA
U1: TPS2112A; TSSOP8
U2: MAX1555; SOT23-5
U3: USD-SOCKETNEW; MICRO-SD-SOCKET-PP
U4: 3.3V; SOT23-5
U5: 2.8V; SOT23-5
U6: 74HC595; TSSOP16
U7: AUDIO-JACKSMD2; AUDIO-JACK-3.5MM-SMD
U8: VS1003; LQFP-48
U9: ATMEGA32U4TQFP; SPARKFUN-DIGITALIC_TQFP44
Y1: 8MHz; HC49/US
Y2: 12.288MHz; CSM-3X

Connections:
CHG_B: U2.3 (CHG), U9.1 (PE6)
CVDD: C14.1, C15.1, C16.1, C17.1, C18.1, C19.1, C20.1, C21.1, C22.1, L2.P$2 (2), U5.4 (FB), U8.5 (CVDD0), U8.7 (CVDD1), U8.24 (CVDD2), U8.31 (CVDD3), U8.38 (AVDD0), U8.43 (AVDD1), U8.45 (AVDD2)
ENCODER_A: S2.1 (A), U9.31 (PC6)
ENCODER_B: S2.6 (B), U9.29 (PB5(ADC12))
ENCODER_S: S2.4 (SW2), U9.30 (PB6(ADC13))
GBUF: R17.2, U7.SLEEVE, U8.42 (GBUF)
GND: C1.1, C2.2, C3.2, C4.2, C5.2, C6.2, C7.2, C8.2, C9.2, C10.2, C11.2, C12.2, C13.2, C14.2, C15.2, C16.2, C17.2, C18.2, C19.2, C20.2, C21.2, C22.2, C23.2, C24.2, C25.2, C26.2, C27.2, C28.2, C29.2, J1.6, JP1.GND, JP2.6 (GND), JP3.2, R4.1, R5.1, R7.2, R10.2, R12.1, R13.1, R14.1, R16.1, R22.2, R23.2, R24.1, R25.1, R26.1, R27.1, R28.1, R29.1, R30.1, R31.1, S2.2 (COM), S2.3 (SW1), S2.5 (SW1_), U1.2 (EN_B), U1.3 (VSNS), U1.5 (GND), U2.2 (GND), U3.6 (GND), U3.GND1 (SHIELD), U3.GND3 (SHIELD), U4.2 (GND), U5.2 (GND), U6.8 (GND), U8.4 (DGND0), U8.16 (DGND1), U8.20 (DGND2), U8.21 (DGND3), U8.22 (DGND4), U8.37 (AGND0), U8.40 (AGND1), U8.41 (AGND2), U8.47 (AGND3), U9.5 (UGND), U9.15 (GND), U9.23 (GND), U9.35 (GND), U9.43 (GND)
GPIO0: R12.2, U8.33 (GPIO0)
GPIO1: R13.2, U8.34 (GPIO1)
GPIO2: R14.2, U8.9 (GPIO2)
GPIO3: R16.2, U8.10 (GPIO3)
LEFT: R19.2, R20.2, U8.46 (LEFT)
MISO: J1.1, U3.7 (DO), U8.30 (SO), U9.11 (PB3(MISO))
MOSI: J1.4, U3.3 (DI), U8.29 (SI), U9.10 (PB2(MOSI))
MP3_DREQ: U8.8 (DREQ), U9.37 (PF6(ADC6))
MP3_XCS: R8.1, U8.23 (XCS), U9.39 (PF4(ADC4))
MP3_XDCS: R9.1, U8.13 (XDCS), U9.40 (PF1(ADC1))
MP3_XRESET: R7.1, U8.3 (XRESET), U9.38 (PF5(ADC5))
unnamed: JP1.D-, R1.2
unnamed: C5.1, U9.17 (XTAL1), Y1.P$2
unnamed: C27.1, R17.1
unnamed: C28.1, R18.1
unnamed: C29.1, R19.1
unnamed: JP1.D+, R2.2
unnamed: C12.1, R15.2, U8.18 (XT2), Y2.P$1
unnamed: C11.1, R15.1, U8.17 (XT1), Y2.P$2
unnamed: C31.1, R21.1
unnamed: C30.1, R20.1
unnamed: C31.2, R22.1, U7.RING (RIGHT)
unnamed: C30.2, R23.1, U7.TIP (LEFT)
unnamed: C6.1, U9.16 (XTAL2), Y1.P$1
unnamed: R5.2, U1.4 (ILIM)
unnamed: C9.1, C10.1, R11.1, U1.7 (OUT), U4.1 (VIN), U4.3 (EN), U5.1 (VIN), U5.3 (EN)
unnamed: LED8.A, U6.7 (Q7)
unnamed: LED7.A, U6.6 (Q6)
unnamed: LED6.A, U6.5 (Q5)
unnamed: LED5.A, U6.4 (Q4)
unnamed: LED4.A, U6.3 (Q3)
unnamed: LED3.A, U6.2 (Q2)
unnamed: LED2.A, U6.1 (Q1)
unnamed: LED1.A, U6.15 (Q0)
unnamed: LED1.C, R24.2
unnamed: LED2.C, R25.2
unnamed: LED3.C, R26.2
unnamed: LED4.C, R27.2
unnamed: LED5.C, R28.2
unnamed: LED6.C, R29.2
unnamed: LED7.C, R30.2
unnamed: LED8.C, R31.2
unnamed: L1.P$1 (1), U4.5 (SW)
unnamed: L2.P$1 (1), U5.5 (SW)
unnamed: S1.P$2 (2), U1.6 (IN2)
RCAP: C26.1, U8.44 (RCAP)
RESET: J1.5, R3.1, U9.13 (!RESET)
RIGHT: R18.2, R21.2, U8.39 (RIGHT)
SCK: J1.3, U3.5 (SCK), U8.28 (SCLK), U9.9 (PB1(SCK))
SD_CD: U3.CD2 (SHIELD), U9.32 (PC7)
SD_CS: R6.1, U3.2 (CS), U9.8 (PB0(SS))
SERIAL_RX: JP2.3 (TXO), U9.20 (PD2(RX))
SERIAL_TX: JP2.2 (RXI), U9.21 (PD3(TX))
SHIFT_DS: U6.14 (DS), U9.28 (PB4(ADC11))
SHIFT_OE: U6.13 (OE), U9.27 (PD7(ADC10))
SHIFT_SHCP: U6.11 (SHCP), U9.25 (PD4(ADC8))
SHIFT_STCP: U6.12 (STCP), U9.26 (PD6(ADC9))
USB_D+: R2.1, U9.4 (D+)
USB_D-: R1.1, U9.3 (D-)
VBAT: JP3.1, S1.P$3 (3), U2.5 (BATT)
VBUS: C1.2, C7.1, JP1.VBUS, R4.2, U1.8 (IN1), U2.1 (USB), U9.7 (VBUS)
VDD: C2.1, C3.1, C4.1, C8.1, C13.1, C23.1, C24.1, C25.1, J1.2, L1.P$2 (2), R3.2, R6.2, R8.2, R9.2, U3.4 (VCC), U4.4 (FB), U6.10 (MR), U6.16 (VCC), U8.6 (IOVDD0), U8.14 (IOVDD1), U8.19 (IOVDD2), U8.26 (RX), U8.32 (TEST), U9.6 (UCAP), U9.14 (VCC), U9.24 (AVCC), U9.34 (VCC), U9.44 (AVCC)
V_READ: R10.1, R11.2, U9.41 (PF0(ADC0))

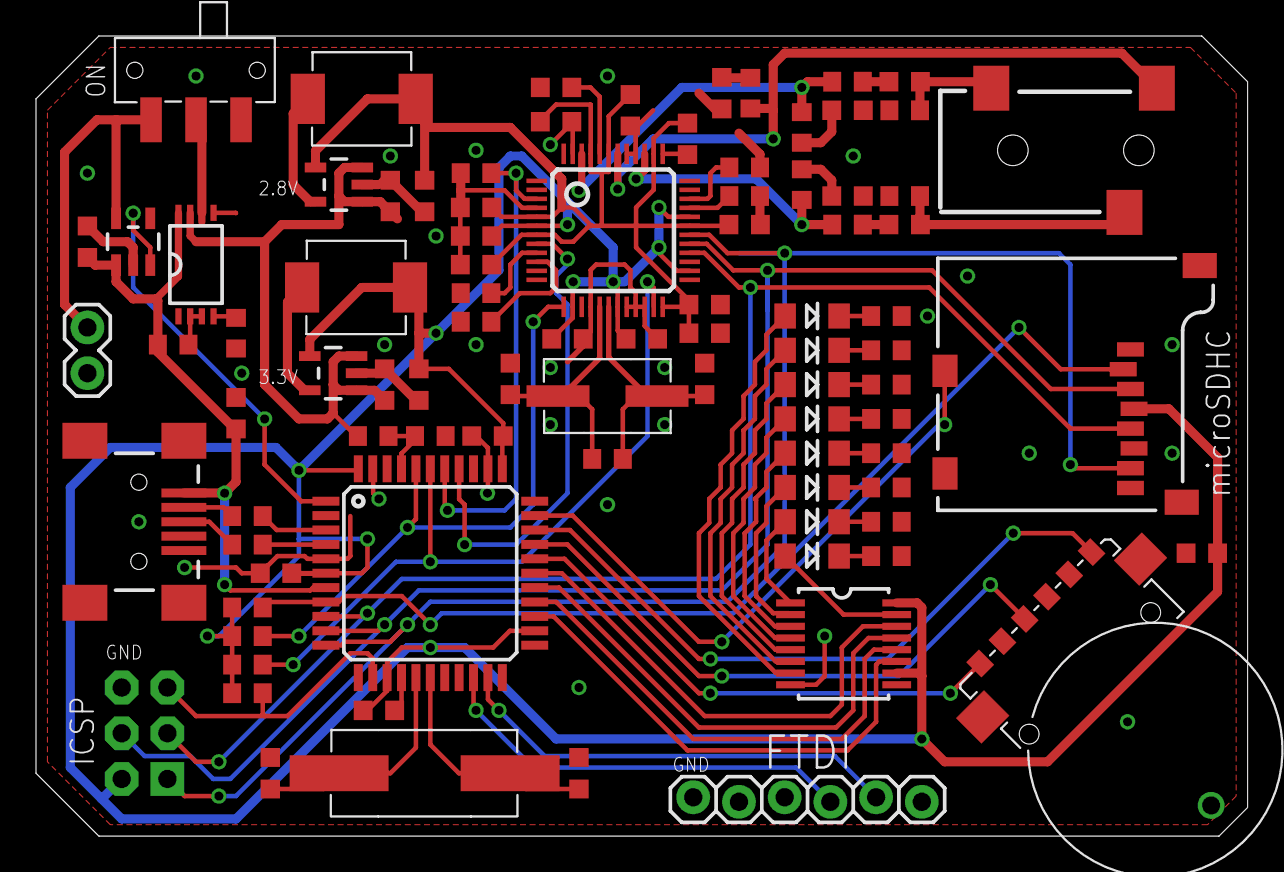
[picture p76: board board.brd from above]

Board: 2 copper layers, 67.3 x 44.4 mm, 89 parts (0 on the bottom side), 70 nets.

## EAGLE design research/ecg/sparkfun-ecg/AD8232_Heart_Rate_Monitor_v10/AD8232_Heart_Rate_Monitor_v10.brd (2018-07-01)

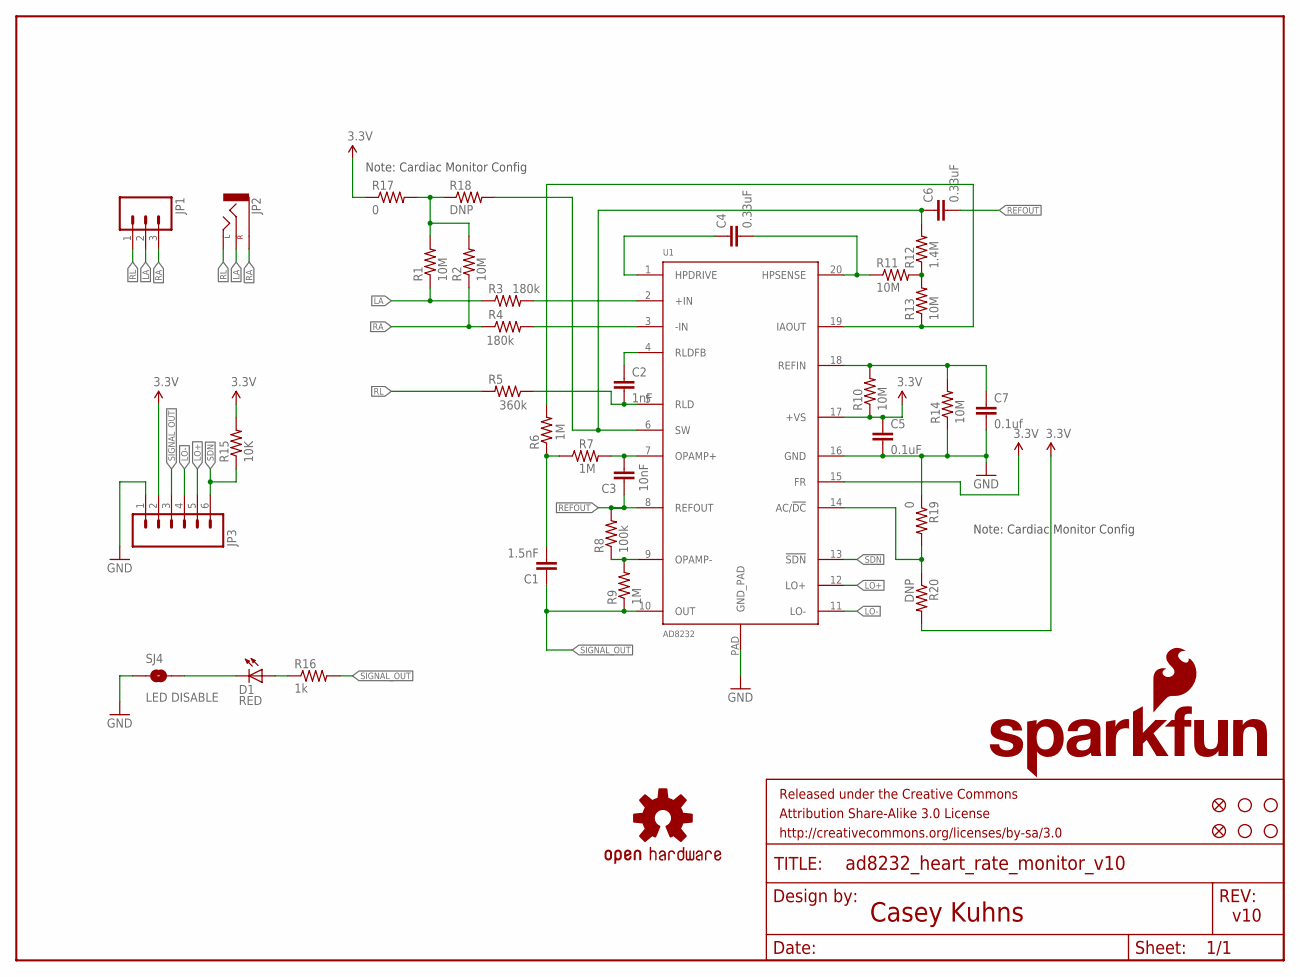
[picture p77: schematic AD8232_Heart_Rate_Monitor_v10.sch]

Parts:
C1: 1.5nF; 0603-CAP
C2: 1nF; 0603-CAP
C3: 10nF; 0603-CAP
C4, C6: 0.33uF; 0805
C5: 0.1uF; 0603-CAP
C7: 0.1uf; 0603-CAP
D1: RED; LED-0603
FID1, FID2: FIDUCIAL1X2; FIDUCIAL-1X2
FRAME1: FRAME-LETTER; CREATIVE_COMMONS
JP1: M03PTH; 1X03
JP2: AUDIO-JACKSMD2; AUDIO-JACK-3.5MM-SMD
JP3: M06SIP; 1X06
LOGO1: OSHW-LOGOS; OSHW-LOGO-S
LOGO2: SFE_LOGO_NAME_FLAME.1_INCH; SFE_LOGO_NAME_FLAME_.1
R1, R2, R10, R11, R13, R14: 10M; 0603-RES
R3, R4: 180k; 0603-RES
R5: 360k; 0603-RES
R6, R7, R9: 1M; 0603-RES
R8: 100k; 0603-RES
R12: 1.4M; 0603-RES
R15: 10K; 0603-RES
R16: 1k; 0603-RES
R17, R19: 0; 0603
R18, R20: DNP; 0603
SJ4: LED DISABLE; SJ_2S-TRACE
STANDOFF1, STANDOFF2, STANDOFF3, STANDOFF4: STAND-OFF
U1: AD8232; LFCSP_20

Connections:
3.3V: C5.1, JP3.2, R10.1, R15.2, R17.1, R20.2, U1.15 (FR), U1.17 (+VS)
GND: C5.2, C7.2, JP3.1, R14.1, R19.1, SJ4.1, U1.16 (GND), U1.PAD (GND_PAD)
LA: JP1.2, JP2.RING (RIGHT), R1.1, R3.1
LO+: JP3.5, U1.12 (LO+)
LO-: JP3.4, U1.11 (LO-)
unnamed: R3.2, U1.2 (+IN)
unnamed: R4.2, U1.3 (-IN)
unnamed: C3.2, R7.2, U1.7 (OPAMP+)
unnamed: C4.2, R11.1, U1.20 (HPSENSE)
unnamed: C7.1, R10.2, R14.2, U1.18 (REFIN)
unnamed: D1.A, R16.1
unnamed: R8.1, R9.2, U1.9 (OPAMP-)
unnamed: R6.2, R13.1, U1.19 (IAOUT)
unnamed: C1.2, R6.1, R7.1
unnamed: D1.C, SJ4.2
unnamed: R19.2, R20.1, U1.14 (AC/!DC)
unnamed: C4.1, U1.1 (HPDRIVE)
unnamed: R11.2, R12.1, R13.2
unnamed: C6.1, R12.2, R18.2, U1.6 (SW)
unnamed: C2.1, U1.4 (RLDFB)
unnamed: C2.2, R5.1, U1.5 (RLD)
unnamed: R1.2, R2.2, R17.2, R18.1
RA: JP1.3, JP2.SLEEVE, R2.1, R4.1
REFOUT: C3.1, C6.2, R8.2, U1.8 (REFOUT)
RL: JP1.1, JP2.TIP (LEFT), R5.2
SDN: JP3.6, R15.1, U1.13 (!SDN)
SIGNAL_OUT: C1.1, JP3.3, R9.1, R16.2, U1.10 (OUT)

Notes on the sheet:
Casey Kuhns
v10
Note: Cardiac Monitor Config

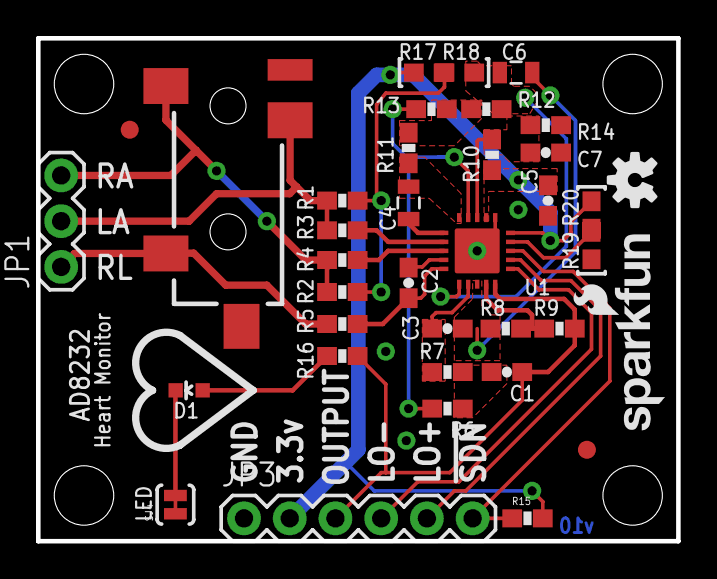
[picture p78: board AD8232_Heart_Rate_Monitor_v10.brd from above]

Board: 2 copper layers, 35.6 x 27.9 mm, 42 parts (0 on the bottom side), 27 nets.

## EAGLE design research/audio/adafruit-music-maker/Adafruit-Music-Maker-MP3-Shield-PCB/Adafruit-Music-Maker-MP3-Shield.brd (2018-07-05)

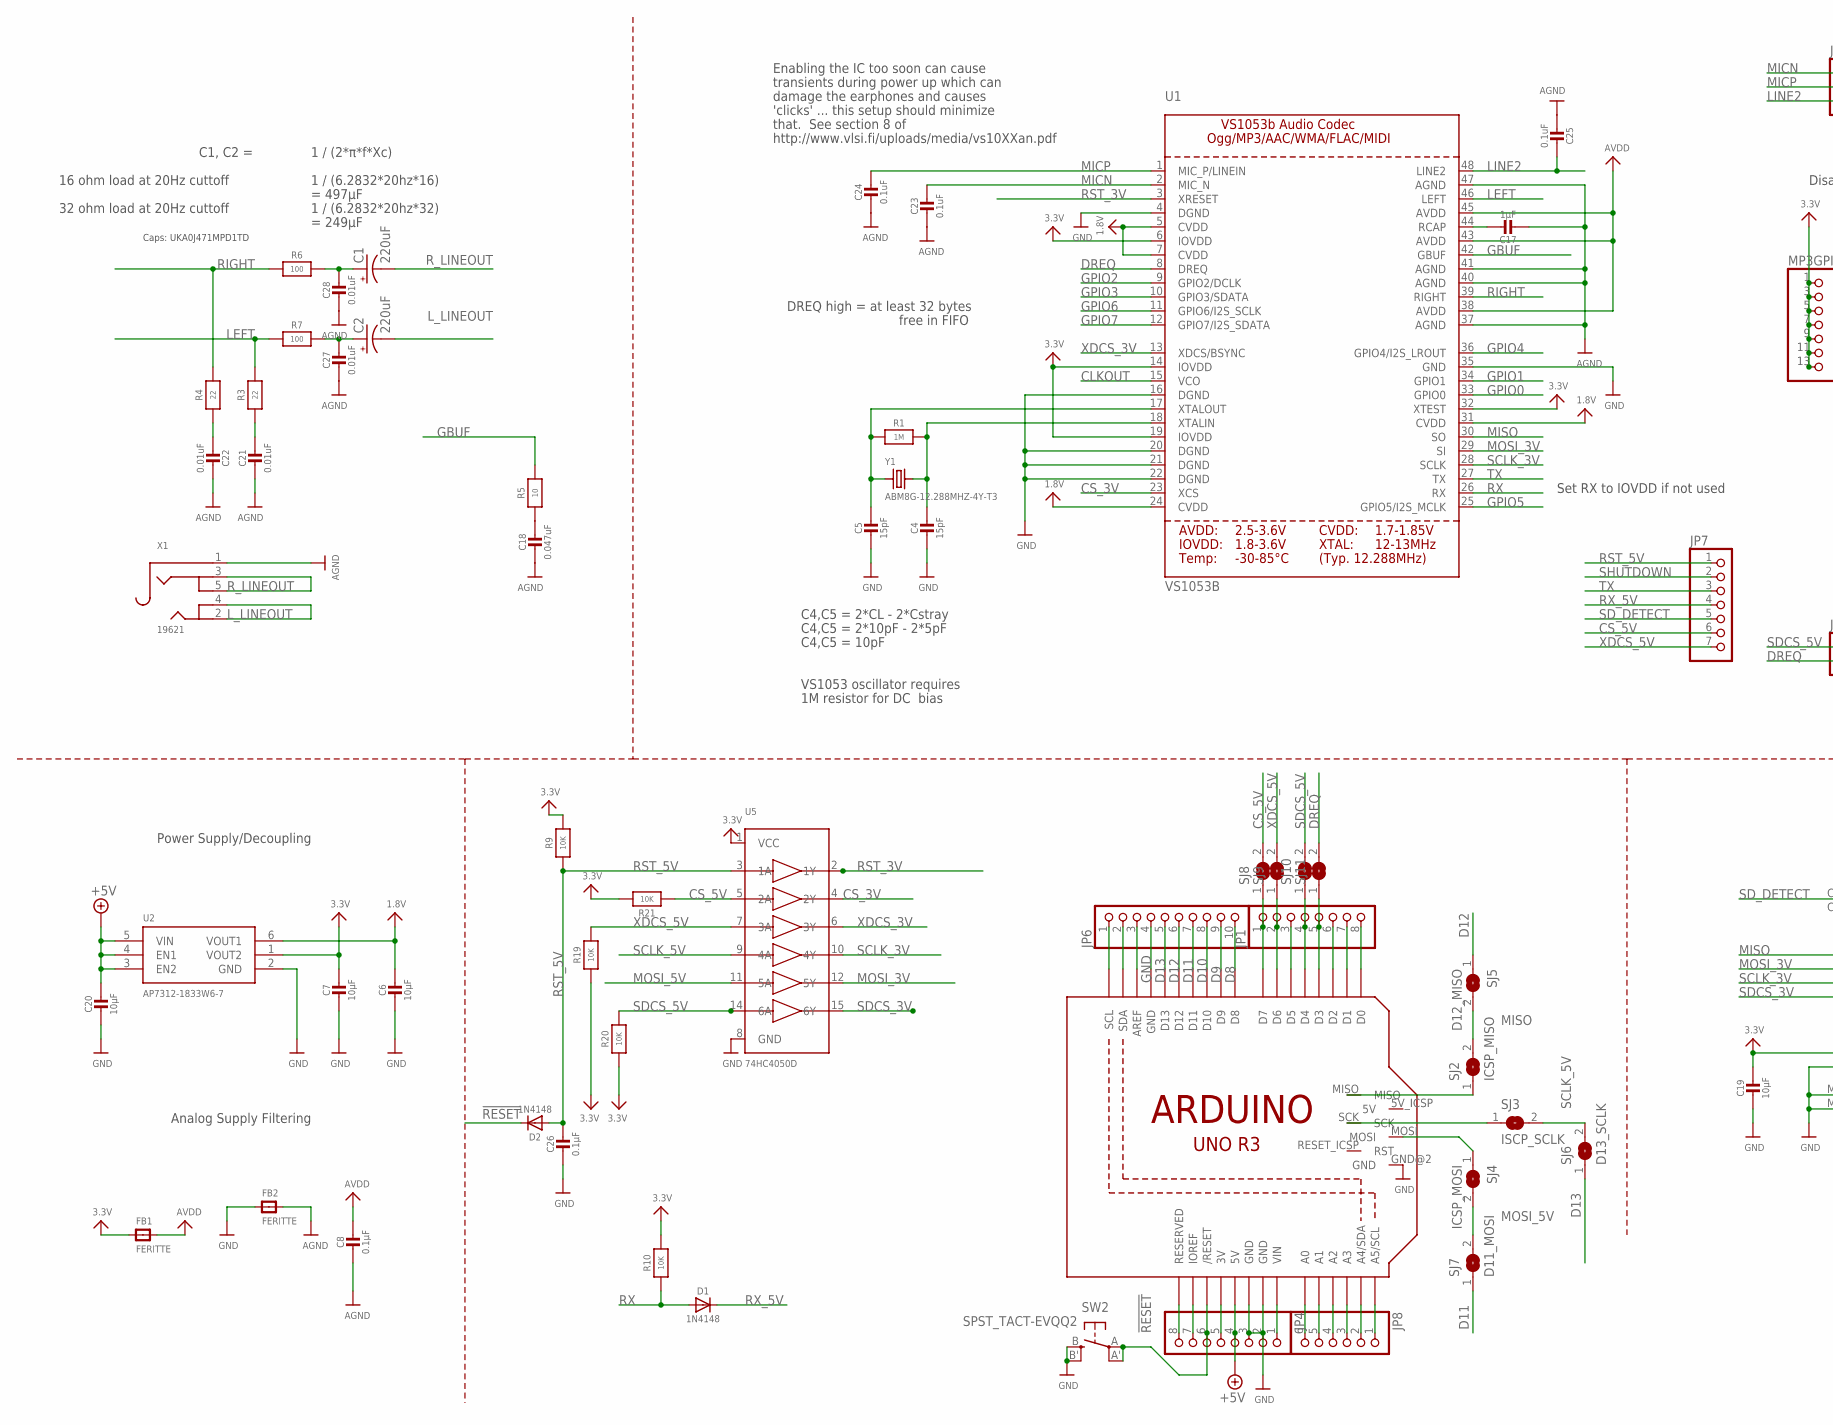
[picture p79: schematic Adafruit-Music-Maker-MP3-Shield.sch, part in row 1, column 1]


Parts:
C1, C2: 220uF; PANASONIC_C
C3, C6, C7, C16, C20: 10µF; 0805-NO
C4, C5: 15pF; 0805-NO
C8, C26: 0.1µF; _0805MP
C9, C10, C11: 0.1µF; 0805-NO
C12, C13, C14, C15, C17: 1µF; 0805-NO
C18: 0.047uF; 0805-NO
C19: 10µF; _0805MP
C21, C27, C28: 0.01uF; 0805-NO
C22: 0.01uF; _0805MP
C23, C25: 0.1uF; 0805-NO
C24: 0.1uF; 0805_10MGAP
CN1: 2908-05WB-M6; MICROSD
D1, D2: 1N4148; SOD-323
FB1, FB2: FERITTE; _0805MP
FB3, FB4: ferrite; _0805MP
FID1, FID2, FID3: FIDUCIAL""; FIDUCIAL_1MM
JP1, JP4: PINHD-1X8CLEANBIG; 1X08-CLEANBIG
JP2: PINHD-1X3CB; 1X03-CLEANBIG
JP3: HEADER-1X2ROUND; 1X02_ROUND
JP6: HEADER-1X1070MIL; 1X10_ROUND70
JP7: HEADER-1X770MIL; 1X07_ROUND_70
JP8: PINHD-1X6CB; 1X06-CLEANBIG
LEFTSPK: 3.5mm Term; TERMBLOCK_1X2-3.5MM
MP3GPIO: HEADER-2X7_ROUND_70MIL; 2X07_ROUND_70MIL
R1: 1M; 0805-NO
R2, R8, R13, R14, R15, R16, R17, R18: 100K; 0805-NO
R3: 22; 0805-NO
R4: 22; _0805MP
R5: 10; 0805-NO
R6: 100; _0805MP
R7: 100; 0805-NO
R9, R10: 10K; _0805MP
R12: 100K; _0805MP
R19, R20, R21: 10K; 0805-NO
RIGHTSPK: 3.5mm Term; TERMBLOCK_1X2-3.5MM
SJ1: +6dB; SOLDERJUMPER_ARROW_NOPASTE
SJ2: ICSP_MISO; SOLDERJUMPER_REFLOW_NOPASTE
SJ3: ISCP_SCLK; SOLDERJUMPER_REFLOW_NOPASTE
SJ4: ICSP_MOSI; SOLDERJUMPER_REFLOW_NOPASTE
SJ5: D12_MISO; SOLDERJUMPER_CLOSEDWIRE
SJ6: D13_SCLK; SOLDERJUMPER_CLOSEDWIRE
SJ7: D11_MOSI; SOLDERJUMPER_CLOSEDWIRE
SJ8, SJ9, SJ10, SJ11: SOLDERJUMPERCLOSED; SOLDERJUMPER_CLOSEDWIRE
SJ12: +12dB; SOLDERJUMPER_ARROW_NOPASTE
SW2: SPST_TACT-EVQQ2; EVQ-Q2
U1: VS1053B; LQFP48
U2: AP7312-1833W6-7; SOT23-6
U4: TS2012; WQFN20
U5: 74HC4050D; SOIC16
U$41: ARDUINO_R3_ICSP; ARDUINOR3_ICSP
X1: 19621; 4UCONN_19269
Y1: ABM8G-12.288MHZ-4Y-T3; CRYSTAL_3.2X2.5

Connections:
1.8V: C6.1, U1.5 (CVDD), U1.7 (CVDD), U1.24 (CVDD), U1.31 (CVDD), U2.6 (VOUT1)
3.3V: C7.1, C19.1, CN1.4 (SD_VDD), FB1.1, MP3GPIO.1, MP3GPIO.3, MP3GPIO.5, MP3GPIO.7, MP3GPIO.9, MP3GPIO.11, MP3GPIO.13, R9.2, R10.2, R19.1, R20.1, R21.2, U1.6 (IOVDD), U1.14 (IOVDD), U1.19 (IOVDD), U1.32 (XTEST), U2.1 (VOUT2), U5.1 (VCC)
!RESET: D2.C, JP4.6, SW2.A, SW2.A' (P1), U$41.RESET (/RESET)
+5V: C3.1, C11.1, C16.1, C20.1, FB3.1, JP4.4, R12.2, SJ1.2, SJ12.2, U2.3 (EN2), U2.4 (EN1), U2.5 (VIN), U4.3 (PVDD), U4.13 (PVDD), U$41.5V
AGND: C8.2, C12.1, C15.1, C17.2, C18.2, C21.2, C22.2, C23.2, C24.2, C25.2, C27.2, C28.2, FB2.2, U1.37 (AGND), U1.40 (AGND), U1.41 (AGND), U1.47 (AGND), X1.1
AVDD: C8.1, FB1.2, U1.38 (AVDD), U1.43 (AVDD), U1.45 (AVDD)
CLKOUT: U1.15 (VCO)
CS_3V: U1.23 (XCS), U5.4 (2Y)
CS_5V: JP7.6, R21.1, SJ8.2, U5.5 (2A)
D8: JP6.10, U$41.D8
D9: JP6.9, U$41.D9
D10: JP6.8, U$41.D10
D11: JP6.7, SJ7.1, U$41.D11
D12: JP6.6, SJ5.1, U$41.D12
D13: JP6.5, SJ6.1, U$41.D13
DREQ: JP3.2, SJ11.2, U1.8 (DREQ)
GAIN0: SJ1.1, U4.15 (G0)
GBUF: R5.1, U1.42 (GBUF)
GND: C3.2, C4.2, C5.2, C6.2, C7.2, C10.1, C11.2, C16.2, C19.2, C20.2, C26.2, CN1.6 (GND), CN1.MT1 (GND), CN1.MT2 (GND), FB2.1, FB4.1, JP4.2, JP4.3, JP6.4, R2.2, R8.2, R13.2, R14.2, R15.2, R16.2, R17.2, R18.2, SW2.B (S), SW2.B' (S1), U1.4 (DGND), U1.16 (DGND), U1.20 (DGND), U1.21 (DGND), U1.22 (DGND), U1.35 (GND), U2.2 (GND), U4.4 (PGND), U4.12 (PGND), U4.21 (THERMAL), U5.8 (GND), U$41.GND, U$41.GND@1 (GND), U$41.GND@2 (GND), U$41.GND@3 (GND)
GPIO0: R2.1, U1.33 (GPIO0)
GPIO1: MP3GPIO.2, R8.1, U1.34 (GPIO1)
GPIO2: MP3GPIO.4, R13.1, U1.9 (GPIO2/DCLK)
GPIO3: MP3GPIO.6, R14.1, U1.10 (GPIO3/SDATA)
GPIO4: MP3GPIO.8, R15.1, U1.36 (GPIO4/I2S_LROUT)
GPIO5: MP3GPIO.10, R16.1, U1.25 (GPIO5/I2S_MCLK)
GPIO6: MP3GPIO.12, R17.1, U1.11 (GPIO6/I2S_SCLK)
GPIO7: MP3GPIO.14, R18.1, U1.12 (GPIO7/I2S_SDATA)
LEFT: C13.1, R3.1, R7.2, U1.46 (LEFT)
LEFT_FILTERED: C2.+, C27.1, R7.1
LINE2: C25.1, JP2.3, U1.48 (LINE2)
L_LINEOUT: C2.-, X1.2, X1.4
MICN: C23.1, JP2.1, U1.2 (MIC_N)
MICP: C24.1, JP2.2, U1.1 (MIC_P/LINEIN)
MISO: CN1.7 (DATA_OUT), SJ2.2, SJ5.2, U1.30 (SO)
MOSI_3V: CN1.3 (DATA_IN), U1.29 (SI), U5.12 (5Y)
MOSI_5V: SJ4.2, SJ7.2, U5.11 (5A)
unnamed: C5.1, R1.1, U1.17 (XTALOUT), Y1.1
unnamed: C4.1, R1.2, U1.18 (XTALIN), Y1.2
unnamed: JP6.1, U$41.SCL
unnamed: JP6.2, U$41.SDA
unnamed: C21.1, R3.2
unnamed: C22.1, R4.2
unnamed: JP6.3, U$41.AREF
unnamed: C13.2, U4.20 (INL+)
unnamed: C12.2, U4.19 (INL-)
unnamed: C15.2, U4.17 (INR-)
unnamed: C14.2, U4.16 (INR+)
unnamed: C9.2, C10.2, FB4.2, U4.18 (AGND)
unnamed: JP4.1, U$41.VIN
unnamed: C9.1, FB3.2, U4.9 (AVDD)
unnamed: SJ4.1, U$41.MOSI
unnamed: SJ3.1, U$41.SCK
unnamed: JP4.5, U$41.3V
unnamed: JP1.1, SJ8.1, U$41.D7
unnamed: JP4.7, U$41.IOREF
unnamed: JP4.8, U$41.RESERVED
unnamed: SJ2.1, U$41.MISO
unnamed: JP1.2, SJ9.1, U$41.D6
unnamed: JP1.5, SJ11.1, U$41.D3
unnamed: JP1.4, SJ10.1, U$41.D4
unnamed: JP1.3, U$41.D5
unnamed: SJ12.1, U4.1 (G1)
unnamed: C17.1, U1.44 (RCAP)
unnamed: JP1.6, U$41.D2
unnamed: JP1.7, U$41.D1
unnamed: JP1.8, U$41.D0
unnamed: C18.1, R5.2
unnamed: JP8.1, U$41.A5 (A5/SCL)
unnamed: JP8.2, U$41.A4 (A4/SDA)
unnamed: JP8.3, U$41.A3
unnamed: JP8.4, U$41.A2
unnamed: JP8.5, U$41.A1
unnamed: JP8.6, U$41.A0
OUT-L-N: LEFTSPK.1, U4.5 (OUTL-)
OUT-L-P: LEFTSPK.2, U4.2 (OUTL+)
OUT-R-N: RIGHTSPK.2, U4.11 (OUTR-)
OUT-R-P: RIGHTSPK.1, U4.14 (OUTR+)
RIGHT: C14.1, R4.1, R6.2, U1.39 (RIGHT)
RIGHT_FILTERED: C1.+, C28.1, R6.1
RST_3V: U1.3 (XRESET), U5.2 (1Y)
RST_5V: C26.1, D2.A, JP7.1, R9.1, U5.3 (1A)
RX: D1.A, R10.1, U1.26 (RX)
RX_5V: D1.C, JP7.4
R_LINEOUT: C1.-, X1.3, X1.5
SCLK_3V: CN1.5 (SCLK), U1.28 (SCLK), U5.10 (4Y)
SCLK_5V: SJ3.2, SJ6.2, U5.9 (4A)
SDCS_3V: CN1.2 (CS), U5.15 (6Y)
SDCS_5V: JP3.1, R20.2, SJ10.2, U5.14 (6A)
SD_DETECT: CN1.CD1 (CARD_DETECT), JP7.5
SHUTDOWN: JP7.2, R12.1, U4.7 (SHUTDOWN_L), U4.8 (SHUTDOWN_R)
TX: JP7.3, U1.27 (TX)
XDCS_3V: U1.13 (XDCS/BSYNC), U5.6 (3Y)
XDCS_5V: JP7.7, R19.2, SJ9.2, U5.7 (3A)

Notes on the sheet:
Analog Supply Filtering
C4,C5 = 2*CL - 2*Cstray
C4,C5 = 2*10pF - 2*5pF
C4,C5 = 10pF
VS1053 oscillator requires
1M resistor for DC bias
Set RX to IOVDD if not used
DREQ high = at least 32 bytes
Power Supply/Decoupling
transients during power up which can
damage the earphones and causes
'clicks' ... this setup should minimize
that. See section 8 of
http://www.vlsi.fi/uploads/media/vs10XXan.pdf
Enabling the IC too soon can cause
free in FIFO
Disable SPI boot with GPIO0 low
1 / (2*π*f*Xc)
16 ohm load at 20Hz cuttoff
1 / (6.2832*20hz*16)
C1, C2 =
= 497µF
32 ohm load at 20Hz cuttoff
1 / (6.2832*20hz*32)
= 249µF
Caps: UKA0J471MPD1TD
GAIN1 and GAIN0 have built-in pull down resistors. VS1053 out is 2Vpp so 2V/V gain keeps it under 4.5V for low distortion.
Place C1 as close as possible to PVDD.
Any resistance or inductance in the trace
between the device and the capacitor can
cause a loss in efficiency
Using speakers more resistive than 4-Ω
dramatically increases the thermal performance
by reducing the output current and increasing
the efficiency of the amplifier.
Note on speaker choice (4/8/16/32 ohm, etc.):
The audio input pins (INR+/-
and INL+/-) must run
side-by-side to maximize
common-mode noise cancellation.



Board: 2 copper layers, 68.6 x 53.3 mm, 89 parts (4 on the bottom side), 92 nets.

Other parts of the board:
U$50: ADAFRUIT_9MM

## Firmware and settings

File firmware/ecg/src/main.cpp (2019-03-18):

/*******************************************************************************
 *
 *	@brief	MAX30003 ECG
 *
 ********************************************************************************/

/*******************************************************************************
 * Includes
 ********************************************************************************/
#include <Arduino.h>
#include <max30003.h>
#include <plot.h>

/*******************************************************************************
 * Pin Configuration
 ********************************************************************************/

// MAX30003 Interrupt 1 to receive ECG readings
const uint8_t ECG_INT1_PIN = 2;
// Heart Pulse LED on MCU Module
const uint8_t MCU_HEART_PULSE_PIN = A1;
// Heart Pulse to DSP GPIO MP2
const uint8_t DSP_HEART_PULSE_PIN = A0;

/*******************************************************************************
 * Definitions
 ********************************************************************************/
#define CURRENT_SYSTEM_TIME_MS millis()
#define RTOR_INTERRUPT_PULSE_ON 10
#define RTOR_INTERRUPT_PULSE_OFF 2
#define STABLE_RTOR_STATUS_UNKNOWN 2
#define STABLE_RTOR_STATUS_FALSE 0
#define STABLE_RTOR_STATUS_TRUE 1

// Active HIGH logic state of DSP output
#define DSP_HEART_PULSE_ON HIGH
#define DSP_HEART_PULSE_OFF LOW

/*******************************************************************************
 * Variable declarations
 ********************************************************************************/
const uint32_t EINT_STATUS_MASK = 0x800000;   // D[23] bit
const uint32_t DCLOFF_STATUS_MASK = 0x100000; // D[20] bit
const uint32_t RTOR_STATUS_MASK = 0x400;      // D[11] bit
const uint8_t FIFO_OVF_MASK = 0x7;
const uint8_t FIFO_VALID_SAMPLE_MASK = 0x0;
const uint8_t FIFO_FAST_SAMPLE_MASK = 0x1;
const uint8_t ETAG_BITS_MASK = 0x7;
const float RTOR_LSB_RES = 0.0078125f;
// 8ms RTOR resolution is for 32768Hz master clock
const uint8_t RTOR_PRESCALE = 8;

max30003 ecg;
plot plotter;

uint32_t ecg_fifo, sample_count, etag_bits[32], rtor;
int16_t ecg_sample[32];
float bpm;
volatile bool ecg_int_flag = 0;

// 120 bpm
const uint16_t MIN_RTOR_INTERVAL = 500;
// 60 bpm
const uint16_t MAX_RTOR_INTERVAL = 1000;
bool heart_pulse_status = DSP_HEART_PULSE_OFF;
int16_t rtor_interrupt_pulse = 1;
uint32_t heart_pulse_on_time_ms = 0;
uint32_t heart_pulse_off_time_ms = 0;
uint16_t current_rtor_interval_ms = 0;
uint32_t last_rtor_interrupt_time_ms = 0;
uint32_t last_fake_rtor_time_ms = 0;

// portion of RTOR when QRS happens
const uint16_t HEART_PULSE_QRS_TIME = 200;
// 72 bpm before RTOR stablized
const uint16_t FAKE_RTOR_INTERVAL_MS = 833;

// avg voltage of samples when electrodes touched. It should be just above the avg peak of when electrodes not-touched
// count of avg voltage of samples above threshold when electrodes touched
// counts to check since electrodes touched, before confirming real touch, to avoid noises
// time to wait since electrodes touched, before sending the fake rtor, to avoid noises
// It takes approximately 20 seconds to get stablized RTOR from MAX30003/ Thompkins Algorithm

const int16_t HANDS_OFF_TOP_VOLTAGE = -5;
const int16_t HANDS_OFF_BOTTOM_VOLTAGE = -25;
uint16_t hands_off_count = 0;
uint16_t hands_on_count = 0;
uint16_t hands_off_count_threshold = 0;
uint16_t hands_on_count_threshold = 0;
int16_t hands_on_detection_batch_count = 0;
bool hands_on_status = false;
const int16_t hands_on_detection_batch_size = 5;
int16_t stable_rtor_status = STABLE_RTOR_STATUS_UNKNOWN;

/*******************************************************************************
 * Functions
 ********************************************************************************/

// interrupt service routine
void ecg_callback()
{
    ecg_int_flag = 1;
}

void setup()
{
    // setup serial port for plotting
    Serial.begin(115200);
    Serial.println("#####################");
    Serial.println("araBeat Firmware v0.6");
    Serial.println("#####################");

    // setup outputs
    pinMode(MCU_HEART_PULSE_PIN, OUTPUT);
    pinMode(DSP_HEART_PULSE_PIN, OUTPUT);

    // test outputs
    digitalWrite(MCU_HEART_PULSE_PIN, HIGH);
    digitalWrite(DSP_HEART_PULSE_PIN, HIGH);
    delay(200);
    digitalWrite(MCU_HEART_PULSE_PIN, LOW);
    digitalWrite(DSP_HEART_PULSE_PIN, LOW);

    // setup interrupt
    pinMode(ECG_INT1_PIN, INPUT);
    attachInterrupt(digitalPinToInterrupt(ECG_INT1_PIN), ecg_callback, CHANGE);

    // setup chipselect pin
    pinMode(MAX30003_CS_PIN, OUTPUT);

    // chip deselect
    digitalWrite(MAX30003_CS_PIN, HIGH);

    // setup SPI
    SPI.begin();
    SPI.setBitOrder(MSBFIRST);
    SPI.setDataMode(SPI_MODE0);

    // initialize max30003 chip
    ecg.max30003_init();
    Serial.println("Hardware initialized");
}

// switch off outputs after RTOR interval timeout
void check_heart_pulse_off_timer()
{
    if ((CURRENT_SYSTEM_TIME_MS - heart_pulse_on_time_ms) >= HEART_PULSE_QRS_TIME)
    {
        heart_pulse_status = DSP_HEART_PULSE_OFF;
        heart_pulse_off_time_ms = CURRENT_SYSTEM_TIME_MS;
        digitalWrite(MCU_HEART_PULSE_PIN, heart_pulse_status);
        digitalWrite(DSP_HEART_PULSE_PIN, heart_pulse_status);
    }
}

// switch on outputs after RTOR detection
void set_heart_pulse_on(uint16_t rtor_interval_ms)
{
    heart_pulse_status = DSP_HEART_PULSE_ON;
    heart_pulse_on_time_ms = CURRENT_SYSTEM_TIME_MS;
    current_rtor_interval_ms = rtor_interval_ms;
    digitalWrite(MCU_HEART_PULSE_PIN, heart_pulse_status);
    digitalWrite(DSP_HEART_PULSE_PIN, heart_pulse_status);
    plotter.send_data_to_arabeat_gui(plot::RTOR_IN_MS, rtor_interval_ms);
}

// send fake pulses when RTOR detection is unstable
void check_stable_rtor_status()
{
    if (hands_on_status == true &&
        ((CURRENT_SYSTEM_TIME_MS - last_rtor_interrupt_time_ms) > MAX_RTOR_INTERVAL) &&
        ((CURRENT_SYSTEM_TIME_MS - last_fake_rtor_time_ms) > FAKE_RTOR_INTERVAL_MS) &&
        heart_pulse_status == DSP_HEART_PULSE_OFF)
    {
        stable_rtor_status = STABLE_RTOR_STATUS_FALSE;
        last_fake_rtor_time_ms = CURRENT_SYSTEM_TIME_MS;
        set_heart_pulse_on(FAKE_RTOR_INTERVAL_MS);
    }
    else if (hands_on_status == false)
        stable_rtor_status = STABLE_RTOR_STATUS_UNKNOWN;
}

/*******************************************************************************
 * ECG voltage readout for serial plotting
 *
 * R-R is always above 0 at 20V/V ECG Gain in the serial plotter, when no ac
 * noise is present ac noise in the system comes from laptop charger, monitor HDMI
 ********************************************************************************/
void loop()
{
    check_stable_rtor_status();
    check_heart_pulse_off_timer();

    if (ecg_int_flag)
    {
        ecg_int_flag = 0;
        uint32_t status = ecg.max30003_read_register(max30003::STATUS);

        // DC Lead-off detection interrupt
        if ((status & DCLOFF_STATUS_MASK) == DCLOFF_STATUS_MASK)
        {
            // Serial.println("DC Lead-off detected");
        }

        // R-to-R readout interrupt
        if ((status & RTOR_STATUS_MASK) == RTOR_STATUS_MASK)
        {
            // Read RtoR register
            rtor = ecg.max30003_read_register(max30003::RTOR);

            rtor_interrupt_pulse = RTOR_INTERRUPT_PULSE_ON;

            // extract 14 bits data from rtor register
            rtor = ((rtor >> 10) & 0x3fff);

            // rtor must be multiplied by prescaler
            rtor = rtor * RTOR_PRESCALE;

            if (rtor >= MIN_RTOR_INTERVAL && rtor <= MAX_RTOR_INTERVAL)
                last_rtor_interrupt_time_ms = millis();

            // switch on outputs
            if (hands_on_status && (rtor >= MIN_RTOR_INTERVAL && rtor <= MAX_RTOR_INTERVAL))
            {
                stable_rtor_status = STABLE_RTOR_STATUS_TRUE;
                set_heart_pulse_on(rtor);
            }

            // calculate BPM
            bpm = 1.0f / (rtor * RTOR_LSB_RES / 60.0f);
        }

        // ECG readout interrupt
        if ((status & EINT_STATUS_MASK) == EINT_STATUS_MASK)
        {
            // reset sample counter
            sample_count = 0;

            do
            {
                // read ecg data from max30003 fifo
                ecg_fifo = ecg.max30003_read_register(max30003::ECG_FIFO);

                // shift out ETAG[5:3] & PTAG[2:0] bits & extract 18 bits data
                // as signed integer for serial plotting
                ecg_sample[sample_count] = ecg_fifo >> 8;

                // extract ETAG[5:3] bits
                etag_bits[sample_count] = (ecg_fifo >> 3) & ETAG_BITS_MASK;

                // increase sample count
                sample_count++;

                // if sample was last in FIFO, then exit
            } while (etag_bits[sample_count - 1] == FIFO_VALID_SAMPLE_MASK ||
                     etag_bits[sample_count - 1] == FIFO_FAST_SAMPLE_MASK);

            // if FIFO is overflowed, reset FIFO
            if (etag_bits[sample_count - 1] == FIFO_OVF_MASK)
                ecg.max30003_write_register(max30003::FIFO_RST, 0);

            // Print results
            for (int i = 0; (sample_count > 1 && i < sample_count); i++)
            {
                plotter.send_data_to_arabeat_gui(plot::ECG_ANALOG_VOLTAGE, ecg_sample[i]);
                plotter.send_data_to_arabeat_gui(plot::HEART_PULSE, heart_pulse_status);
                plotter.send_data_to_arabeat_gui(plot::RTOR_INTERRUPT_PULSE, rtor_interrupt_pulse);
                rtor_interrupt_pulse = RTOR_INTERRUPT_PULSE_OFF;

                // plotter.send_data_to_protocentral_gui(ecg_sample[i],(uint16_t)rtor, (int16_t)bpm);
                // plotter.send_data_to_arduino_plotter(ecg_sample[i]);

                if (ecg_sample[i] >= HANDS_OFF_TOP_VOLTAGE || ecg_sample[i] <= HANDS_OFF_BOTTOM_VOLTAGE)
                    hands_on_count++;
                else
                    hands_off_count++;
            }

            // hands on detection algorithm
            hands_on_detection_batch_count++;
            hands_off_count_threshold = abs(0.50 * sample_count * 5);
            hands_on_count_threshold = 1;

            if (hands_on_detection_batch_count == hands_on_detection_batch_size)
            {
                plotter.send_data_to_arabeat_gui(plot::HANDS_ON_COUNT, hands_on_count);
                plotter.send_data_to_arabeat_gui(plot::HANDS_OFF_COUNT, hands_off_count);
                plotter.send_data_to_arabeat_gui(plot::HANDS_ON_COUNT_THRESHOLD,
                                                 hands_on_count_threshold);
                plotter.send_data_to_arabeat_gui(
                    plot::HANDS_OFF_COUNT_THRESHOLD, hands_off_count_threshold);
                plotter.send_data_to_arabeat_gui(
                    plot::SAMPLE_COUNT, sample_count * hands_on_detection_batch_size);
                plotter.send_data_to_arabeat_gui(plot::STABLE_RTOR_STATUS, stable_rtor_status);

                if (hands_on_count > hands_on_count_threshold && hands_off_count > hands_off_count_threshold)
                {
                    hands_on_status = true;
                    plotter.send_data_to_arabeat_gui(plot::HANDS_ON, hands_on_status);
                }
                else
                {
                    hands_on_status = false;
                    plotter.send_data_to_arabeat_gui(plot::HANDS_ON, hands_on_status);
                }

                hands_on_detection_batch_count = 0;
                hands_off_count = 0;
                hands_on_count = 0;
            }
        }
    }
}

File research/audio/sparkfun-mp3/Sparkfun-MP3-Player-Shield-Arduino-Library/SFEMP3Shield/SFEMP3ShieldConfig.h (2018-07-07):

/**
\file SFEMP3ShieldConfig.h

\brief Hardware dependent configuration definitions
\remarks comments are implemented with Doxygen Markdown format

This SFEMP3ShieldConfig.h helps configure the SFEMP3Shield library for
various supported different base Arduino boards and shield's using the
VS10xx chip. It is possible this may support other VS10xx chips. But are
unverified at this time.

As the name SFEMP3Shield implies this driver was originally developed from
Sparkfun's MP3 Player Shield. Whereas it can and has been easily adapted
to other hardware, both base Arduino's and shield's using the VS10xx.

The default configuration of this library assumes the SFE MP3 Shield, on
an UNO/Duemilanove, when left un-altered.

\note
Support forArduino Mega's REQUIRES additional jumpers. As the SPI are not on the same
pins as the UNO/Duemilanove.
When using a mega with SFE compatible shields jump the following pings :
<tt>
\n Mega's 51 to the MP3's D11 for MOSI
\n Mega's 50 to the MP3's D12 for MISO
\n Mega's 52 to the MP3's D13 for SCK
</tt>
\n The remainder of pins may remain unchanged. Including INT0 as the Mega maps
INT0 to D2 as to support USE_MP3_INTx, as is. Like the Uno.
\n Where the default SFEMP3ShieldConfig.h should not need changing.
\n Yes, SdFat's SoftSPI.h was tried, but has problems when used twice once with
Sd2Card.cpp and a 2nd time with SFEMP3Shield.cpp.

\n

\note
Support for Arduino Leonardo is afflicted by having the SPI pins not routing the same pins as the UNO. This is similar to the Arduino Mega. Where as it appears it should simply work with additional jumpers, from the Leonardo's ICSP port, which has the SPI pins to the MP3 shields equivalent SPI pins.
<tt>
\n Leo's ICSP4 to the MP3's D11 for MOSI
\n Leo's ICSP1 to the MP3's D12 for MISO
\n Leo's ICSP3 to the MP3's D13 for SCK
</tt>
\n and remember to \b NOT use D10 as an input. It must be left as output.

\todo Please let us know if this works? I think it should.

\sa SEEEDUINO as to how to configure for Seeeduino's Music Shield.
\sa GRAVITECH as to how to configure for Gravitech's MP3-4NANO Shield.
 */

#ifndef SFEMP3ShieldConfig_h
#define SFEMP3ShieldConfig_h

//------------------------------------------------------------------------------

/**
 * \def SEEEDUINO
 * \brief A macro to configure use on a Seeeduino MP3 player shield
 *
 * Seeduino MP3 Players is supported. However, its DREQ is not connected to a
 * hard INT(x) pin, hence it MUST be polled. This can be configured, using
 * USE_MP3_SimpleTimer.
 * When using a Seeeduino MP3 Player shield set the below define of SEEEDUINO
 * to 1. As so the correct IO pins are configured MP3_XCS, MP3_XDCS and MP3_DREQ
 *
 * Along with USE_MP3_REFILL_MEANS should not be USE_MP3_INTx, unless extra
 * jumper wires are used.
 *
 * Set \c SEEEDUINO to \c 0 to use on a SparkFun MP3 player shield
 *
 * Set \c SEEEDUINO to \c 1 to use on a Seeeduino MP3 player shield
 */
#define SEEEDUINO 0 // set to 1 if using the Seeeduino Music Shield

/**
 * \def GRAVITECH
 * \brief A macro to configure use on a Gravitech's MP3-4NANO shield
 *
 * Gravitech's MP3-4NANO shield is supported. However, its chip select of the
 * SdCard connected to D4. This can be configured, simply by setting the below
 * define of GRAVITECH to 1.
 *
 * Set \c GRAVITECH to \c 0 to use on a Gravitech's MP3-4NANO shield
 *
 * Set \c GRAVITECH to \c 1 to use on a Gravitech's MP3-4NANO
 */
#define GRAVITECH 0 // set to 1 if using the Gravitech's MP3-4NANO shield

/**
 * \def TEENSY2
 * \brief Macro to configure pins for connecting the Sparkfun shield to a Teensy 2
 *
 * You can connect the Sparkfun Mp3 shield to a Teensy 2 with jumper cables on a
 * breadboard. Teensy SDI pins are CS=0, SCK=1, MOSI=2, MISO=3. If you are using
 * a Teensy 2 then set TEENSY2 to 1 below and scroll down for pin assignments.
 *
 * Set \c TEENSY2 to \c 0 to use on a Gravitech's MP3-4NANO shield
 *
 * Set \c TEENSY2 to \c 1 to use on a Gravitech's MP3-4NANO
 */
#define TEENSY2 0 // set to 1 if using the Sparkfun Mp3 shield with Teensy 2
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

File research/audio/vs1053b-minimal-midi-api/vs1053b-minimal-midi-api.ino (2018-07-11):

/*
 *
 * File:     MP3_Shield_RealtimeMIDI.ino 
 * Author:   Matthias Neeracher
 *
 * This code is in the public domain, with the exception of the contents of sVS1053b_Realtime_MIDI_Plugin.
 *
 * The code is based on Nathan Seidle's Sparkfun Electronics example code for the Sparkfun 
 * MP3 Player and Music Instrument shields and and VS1053 breakout board. 
 *
 * http://www.sparkfun.com/Code/MIDI_Example.pde
 * http://dlnmh9ip6v2uc.cloudfront.net/datasheets/Dev/Arduino/Shields/VS_Shield_Example.zip
 *
 *      Spark Fun Electronics 2011
 *      Nathan Seidle
 *
 *      This code is public domain but you buy me a beer if you use this and we meet someday (Beerware license).
 *
 * THEORY OF OPERATIONS
 *
 * The VS1053b has two ways of playing MIDI: One method is that you simply send a Standard MIDI level 0 file through
 * SPI, and the chip will play it. This works exactly the same way as MP3 mode and will not be discussed further here.
 * The other method is that the VS1053b has a "Real Time MIDI mode", in which it will instantly execute MIDI commands 
 * sent to it through either the UART or SPI. 
 *
 * Real Time MIDI mode can be enabled with two different methods, controlled by USE_GPIO_INIT 
 *  (1) Setting GPIO1 to HIGH (which is hardwired in the Sparkfun Music Instrument shield, and can be done through 
 *      pin 4 in the MP3 Player Shield)
 *  (0) Sending a small software patch through SPI.
 *
 * MIDI data can be sent with two different methods as well, controlled by USE_SPI_MIDI
 *  (0) Through a (software) serial connection on pin 3, at 31250 baud
 *  (1) Through SPI, at an arbitrary data rate. For SPI, each byte of MIDI data needs to be prefixed by a 0 byte 
 *      (The V1053b data sheet erroneously states that the padding should be a 0xFF byte).
 *
 * Both initialization methods and both transmission methods can be selected through the #defines below. Out of the box, 
 * it probably makes most sense to enable real time MIDI through pin 4, and send serial data through pin 3, but if you 
 * want to cut the traces for pin 3 and 4 and use those pins for another purpose, the alternative methods may come in 
 * handy. 
 */ 

#define USE_GPIO_INIT  1
#define USE_SPI_MIDI   0

#define USE_PATCH_INIT  !USE_GPIO_INIT
#define USE_SERIAL_MIDI !USE_SPI_INIT
#define USE_SPI         (USE_SPI_MIDI||USE_PATCH_INIT)

#if USE_SPI
#include <SPI.h>
#endif
#if USE_SERIAL_MIDI
#include <SoftwareSerial.h>
SoftwareSerial midiSerial(0,2); // Soft TX on 3, RX not used (2 is an input anyway, for VS_DREQ)
#endif

#if USE_SPI
#define VS_XCS    6 // Control Chip Select Pin (for accessing SPI Control/Status registers)
#define VS_XDCS   7 // Data Chip Select / BSYNC Pin
#define VS_DREQ   3 // Data Request Pin: Player asks for more data
#endif
#if USE_GPIO_INIT
#define VS_GPIO1  5  // Mode selection (0 = file / 1 = real time MIDI)
#endif

#define VS_RESET  9 //Reset is active low

#if USE_PATCH_INIT
//Write to VS10xx register
//SCI: Data transfers are always 16bit. When a new SCI operation comes in 
//DREQ goes low. We then have to wait for DREQ to go high again.
//XCS should be low for the full duration of operation.
void VSWriteRegister(unsigned char addressbyte, unsigned char highbyte, unsigned char lowbyte){
  while(!digitalRead(VS_DREQ)) ; //Wait for DREQ to go high indicating IC is available
  digitalWrite(VS_XCS, LOW); //Select control

  //SCI consists of instruction byte, address byte, and 16-bit data word.
  SPI.transfer(0x02); //Write instruction
  SPI.transfer(addressbyte);
  SPI.transfer(highbyte);
  SPI.transfer(lowbyte);
  while(!digitalRead(VS_DREQ)) ; //Wait for DREQ to go high indicating command is complete
  digitalWrite(VS_XCS, HIGH); //Deselect Control
}

//
// Plugin to put VS10XX into realtime MIDI mode
// Originally from http://www.vlsi.fi/fileadmin/software/VS10XX/vs1053b-rtmidistart.zip
// Permission to reproduce here granted by VLSI solution.
//
const unsigned short sVS1053b_Realtime_MIDI_Plugin[28] = { /* Compressed plugin */
  0x0007, 0x0001, 0x8050, 0x0006, 0x0014, 0x0030, 0x0715, 0xb080, /*    0 */
  0x3400, 0x0007, 0x9255, 0x3d00, 0x0024, 0x0030, 0x0295, 0x6890, /*    8 */
  0x3400, 0x0030, 0x0495, 0x3d00, 0x0024, 0x2908, 0x4d40, 0x0030, /*   10 */
  0x0200, 0x000a, 0x0001, 0x0050,
};

void VSLoadUserCode(void) {
  int i = 0;

  while (i<sizeof(sVS1053b_Realtime_MIDI_Plugin)/sizeof(sVS1053b_Realtime_MIDI_Plugin[0])) {
    unsigned short addr, n, val;
    addr = sVS1053b_Realtime_MIDI_Plugin[i++];
    n = sVS1053b_Realtime_MIDI_Plugin[i++];
    while (n--) {
      val = sVS1053b_Realtime_MIDI_Plugin[i++];
      VSWriteRegister(addr, val >> 8, val & 0xFF);
    }
  }
}

#endif

void setup() {
#if USE_SPI
  pinMode(VS_DREQ, INPUT);
  pinMode(VS_XCS, OUTPUT);
  pinMode(VS_XDCS, OUTPUT);
  digitalWrite(VS_XCS, HIGH); //Deselect Control
  digitalWrite(VS_XDCS, HIGH); //Deselect Data
#endif
#if USE_SERIAL_MIDI
  midiSerial.begin(31250);
#endif

  pinMode(VS_RESET, OUTPUT);

  Serial.begin(57600); //Use serial for debugging 
  Serial.println("\n******\n");
  Serial.println("MP3 Shield Example");

  //Initialize VS1053 chip 
  digitalWrite(VS_RESET, LOW); //Put VS1053 into hardware reset

#if USE_SPI
  //Setup SPI for VS1053
  pinMode(10, OUTPUT); //Pin 10 must be set as an output for the SPI communication to work
  SPI.begin();
  SPI.setBitOrder(MSBFIRST);
  SPI.setDataMode(SPI_MODE0);

  //From page 12 of datasheet, max SCI reads are CLKI/7. Input clock is 12.288MHz. 
  //Internal clock multiplier is 1.0x after power up. 
  //Therefore, max SPI speed is 1.75MHz. We will use 1MHz to be safe.
  SPI.setClockDivider(SPI_CLOCK_DIV16); //Set SPI bus speed to 1MHz (16MHz / 16 = 1MHz)
  SPI.transfer(0xFF); //Throw a dummy byte at the bus
#endif

  delayMicroseconds(1);
  digitalWrite(VS_RESET, HIGH); //Bring up VS1053
  
#if USE_PATCH_INIT
  VSLoadUserCode();
#else
  pinMode(VS_GPIO1, OUTPUT);
  digitalWrite(VS_GPIO1, HIGH);  // Enable real time MIDI mode
#endif
}

void sendMIDI(byte data)
{
#if USE_SPI_MIDI
  SPI.transfer(0);
  SPI.transfer(data);
#else
  midiSerial.write(data);
#endif
}

//Plays a MIDI note. Doesn't check to see that cmd is greater than 127, or that data values are less than 127
void talkMIDI(byte cmd, byte data1, byte data2) {
#if USE_SPI_MIDI
  //
  // Wait for chip to be ready (Unlikely to be an issue with real time MIDI)
  //
  while (!digitalRead(VS_DREQ))
    ;
  digitalWrite(VS_XDCS, LOW);
#endif
  sendMIDI(cmd);
  //Some commands only have one data byte. All cmds less than 0xBn have 2 data bytes 
  //(sort of: http://253.ccarh.org/handout/midiprotocol/)
  if( (cmd & 0xF0) <= 0xB0 || (cmd & 0xF0) >= 0xE0) {
    sendMIDI(data1);
    sendMIDI(data2);
  } else {
    sendMIDI(data1);
  }

#if USE_SPI_MIDI
  digitalWrite(VS_XDCS, HIGH);
#endif
}

//Send a MIDI note-on message.  Like pressing a piano key
//channel ranges from 0-15
void noteOn(byte channel, byte note, byte attack_velocity) {
  talkMIDI( (0x90 | channel), note, attack_velocity);
}
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

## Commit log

2018-07-01 Add pcb design files, schematics and datasheets
    [AD8232_Heart_Rate_Monitor_v10.brd, AD8232_Heart_Rate_Monitor_v10.sch]
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2018-07-05 Add adafruit music maker files
    [Adafruit-Music-Maker-MP3-Shield.brd, Adafruit-Music-Maker-MP3-Shield.sch]
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2018-07-11 Add mini speaker enclosure design
    [speaker-front.f3d, speaker-front.stl]
2018-07-11 Update mini speaker enclosure design
    [enclosure-back.stl, enclosure-front.stl, mini-speaker-enclosure.f3d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]
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2018-07-15 Add atmega2560 baseboard pcb
    [atmega2560-basebord.kicad_pcb, atmega2560-basebord.sch]
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2018-07-15 Resize schematics and add reset line
    [atmega2560-basebord.sch]
2018-07-15 Update oscillator and reset line in schematics
    [atmega2560-baseboard.sch]
2018-07-15 Add 02x12 connector strip
    [atmega2560-baseboard.sch]
2018-07-16 Add pinout wiring to schematics
    [atmega2560-baseboard.sch]
2018-07-16 Add annotations to schematics
    [atmega2560-baseboard.sch]
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2018-07-16 Update crystal resonator in schematics
    [atmega2560-baseboard.sch]
2018-07-16 Add pcb layout file
    [atmega2560-baseboard.kicad_pcb, atmega2560-baseboard.sch]
2018-07-16 Spread out all footprints
    [atmega2560-baseboard.kicad_pcb]
2018-07-16 Route VCC and GND pin
    [atmega2560-baseboard.kicad_pcb]
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2018-07-18 Add lpkf test pcb file
    [lpkf-test.kicad_pcb, lpkf-test.sch]
2018-07-18 Update schematics with QFN chip
    [lpkf-test.kicad_pcb, lpkf-test.sch]
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2018-07-18 Add LKPF Test min files
    [lpkf-test-min.kicad_pcb, lpkf-test-min.sch]
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2018-07-31 Add araBase-atmega2560 kicad5 project
    [araBase-atmega2560.kicad_pcb, araBase-atmega2560.sch]
2018-07-31 Add pwr flags, labels and mark unconnected pins
    [araBase-atmega2560.sch]
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2018-07-31 Update schematics with 5V to 3.3V regulator, connect all the pins
    [araBase-atmega2560.sch]
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2018-08-01 Update schematics and assign foot prints
    [araBase-atmega2560.sch]
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2018-08-01 Setup design rules for 10mil/10mil trace and 0.8mm/0.4mm via/drill
    [araBase-atmega2560.kicad_pcb]
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2018-11-08 Add silkscren text, logo, gnd copper fill, traces
    [ecg-baseboard.kicad_pcb]
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2018-11-09 Add complete routing, copper fill, silkscreen texts, fiducials
    [ecg-baseboard.kicad_pcb, ecg-baseboard.sch]
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2018-11-14 Add symbol, footprints, datasheets of MAX30003CTI ecg module
    [ecg-module.kicad_pcb, ecg-module.sch]
2018-11-14 Add footprint and symbol of LDO AP2112K-1.8TRG1, Clean files
    [ecg-module.sch]
2018-11-14 Add TXB0108PWR logic level converter symbol and footprint
    [ecg-module.sch]
2018-11-14 Add 1.8 V to 5V Logic Level Conversion schematic
    [ecg-module.sch]
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2018-11-16 Add footprint and symbol of oscillator and audio jack
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2018-12-16 Clean up traces, add design label on copper
    [ecg-module.kicad_pcb]
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2018-12-28 Add production stainless steel sensor-frontend with 10 deg draft, 5mm shell
    [left-final.stl, right-final.stl, right-final.stp]
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2019-01-31 [hw] Add ECG cassette schematic, footprint, symbol, 3D models, datasheets
    [ecg-cassette.kicad_pcb, ecg-cassette.sch]
2019-02-02 [hw] Add routing, silkscreen, copper pour, edgecut to ecg-cassette
    [ecg-cassette-edgecut.dxf, ecg-cassette-mark.dxf, ecg-cassette-silkscreen.dxf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]
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2019-02-03 [hw] Add schematic, layout, datasheets, footprints, 3d models, logo of MCU module
    [mcu-cassette.kicad_pcb, mcu-cassette.sch]
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2019-02-03 [hw] Move copper pour to back layer, Add signature, Update pcb images
    [mcu-cassette.kicad_pcb]
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2019-02-13 Add a parent project folder and migrate libraries of footprints and symbol to parent project folder,
    [Nano-Rev3_0.step, ecg-baseboard-edgecut.dxf, ecg-baseboard.step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]
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2019-02-13 [hw] Update ECG Cassette with new footprints & schematics
    [ecg-cassette.kicad_pcb, ecg-cassette.sch]
2019-02-13 [hw] Update Motherboard with new footprints & schematics
    [motherboard.sch]
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2019-02-25 [hw] Add schematics, footprints, layout of Proto Module
    [proto-module.kicad_pcb, proto-module.sch]
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2019-02-26 [hw] Add motherboard edgecut, silkscreen & mark designs and clean files
    [ecg-cassette-edgecut.dxf, ecg-cassette-mark.dxf, ecg-cassette-silkscreen.dxf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]
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2019-02-26 [hw] Add 3D models of complete ECG, MCU & PROTO modules
    [ecg-cassette.step, mcu-cassette.step, proto-module.step]
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2019-02-26 [hw] Add jumper, pwr led, silkscreen logo to Motherboard
    [motherboard.kicad_pcb, motherboard.sch]
2019-02-27 [hw] Add mounting hole to mother board to fit into heated enclosure
    [heated-enclosure.dxf, motherboard-mounting.dxf, motherboard.kicad_pcb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]
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2019-02-27 [hw] Update gerber setting to enable edge-layer exclusion
    [ecg-cassette.kicad_pcb]
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2019-03-02 [hw] Update motherboard schematics, footprints and 3d models
    [keystone-5000.step, motherboard.kicad_pcb]
2019-03-02 [hw] Update MCU module schematics, footprints, 3d models
    [arduino-nano.step, mcu-cassette.kicad_pcb]
2019-03-02 hw] Update ECU module schematics, footprints, 3d models
    [ecg-cassette.kicad_pcb]
2019-03-02 [hw] Update ECU module v0.1 schematics, footprints, 3d models
    [ecg-module.kicad_pcb]
2019-03-02 [hw] Update Motherboard v0.1 schematics, footprints, 3d models
    [ecg-baseboard.kicad_pcb]
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2019-03-05 [fw] Fix heart pulse generation
    [main.cpp]
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

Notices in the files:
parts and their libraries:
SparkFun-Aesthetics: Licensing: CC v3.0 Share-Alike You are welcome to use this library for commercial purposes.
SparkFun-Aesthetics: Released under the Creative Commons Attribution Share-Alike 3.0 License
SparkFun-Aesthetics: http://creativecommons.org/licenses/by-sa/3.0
